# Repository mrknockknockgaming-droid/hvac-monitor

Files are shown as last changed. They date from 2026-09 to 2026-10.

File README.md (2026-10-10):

# Fullscope: continuous HVAC diagnostics

Fullscope monitors a home's heat pump or air conditioner continuously, the way a technician
would with gauges on it, and tells the contractor and the homeowner when something is going
wrong, before it becomes a no-cool call.

Two small ESP32 monitors sit on the equipment:
- **Outdoor:** refrigerant pressures, line temperatures, outdoor air.
- **Indoor:** supply and return air.

Both read which calls the thermostat is making. A cloud service turns their readings into
superheat, subcooling, delta-T and other checks, and shows them in a web app with two views:
- a **technician view** with live trends and diagnostics;
- a **homeowner view** in plain language.

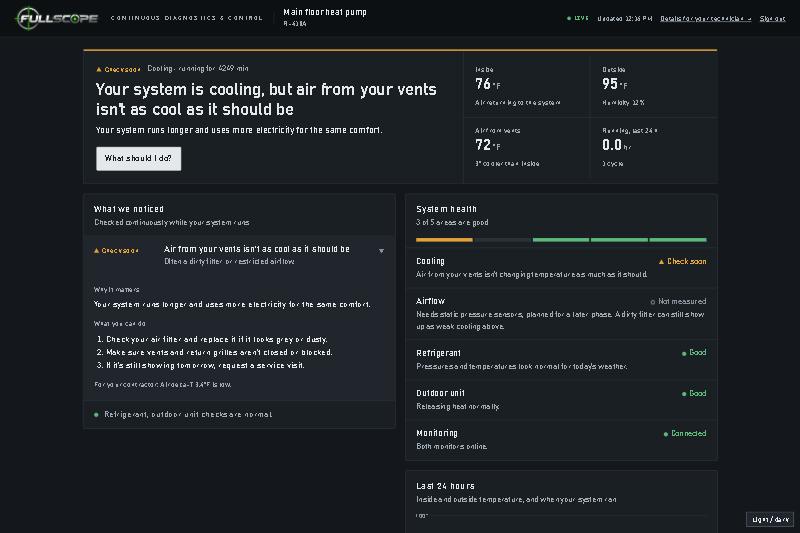
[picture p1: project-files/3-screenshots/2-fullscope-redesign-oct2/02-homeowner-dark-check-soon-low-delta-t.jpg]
Homeowner view


## Status (October 2026)

| Part | State |
|---|---|
| Node firmware (outdoor + indoor) | v0.2.0 built; both dev boards online running 0.1.0, 0.2.0 goes on at board bring-up |
| Carrier boards (rev A, KiCad) | Arrived and assembled; waiting on the pressure sensors for bring-up |
| Cloud + web app | Working locally (SQLite) and in Docker (TimescaleDB); production setup ready to deploy |
| Contractor demo | Seven scripted homes for customer interviews |
| Display thermostat (add-on) | Cloud side, screen and firmware written and tested on the PC; no hardware yet |
| Electrical module (add-on) | Diagnostics written; no hardware yet |
| 900 MHz LoRa radio | Designed and written (nodes, gateway, thermostat as gateway); waiting on a range test |

The full plan is in [project-files/1-plans/roadmap.md](project-files/1-plans/roadmap.md).

## How it fits together

```
 outdoor node ─┐                       ┌─ web app: homeowner + technician views, fleet page
 indoor node  ─┼─ WiFi (or LoRa via ─▶ MQTT broker ─▶ cloud: ingest → diagnostics → alerts
 thermostat   ─┘   a gateway)                          (FastAPI, SQLite / TimescaleDB)
                                                       └─ email alerts, thermostat config + display feed
```

- The nodes publish JSON on `hvac/<site>/<node>/{telemetry,status,reply}` and take
  calibration commands on `.../cmd`.
- The cloud judges each check only when it can be judged, for example refrigerant after
  10 minutes of steady running. A problem that lasts 5 minutes raises an alert.
- The optional display thermostat runs all its control and safety logic on the device itself,
  so heating and cooling never depend on the internet.

## What's where

| Folder | What it is |
|---|---|
| [hvac-firmware](hvac-firmware) | ESP32 firmware for the outdoor and indoor nodes (PlatformIO) |
| [hvac-cloud](hvac-cloud) | Cloud: MQTT ingest, diagnostics, alerts, REST API, the Fullscope web app, contractor demo, Docker / production setup ([DEPLOY.md](hvac-cloud/DEPLOY.md)) |
| [hvac-monitor-app](hvac-monitor-app) | PC dashboard for bench work with one system |
| [hardware](hardware) | Rev A carrier boards (KiCad, fabrication files, schematic PDFs) |
| [docs](docs) | Wiring schematics and carrier-board notes (HTML) |
| [thermostat](thermostat) | Display thermostat: design ([README](thermostat/README.md)) and firmware for the Waveshare ESP32-S3 4.3" board |
| [electrical](electrical) | Electrical monitoring module: design and diagnostic rules |
| [radio](radio) | 900 MHz LoRa: FCC research, frame format, Python reference, C++ library, gateway, range test |
| [design](design) | Fullscope design system, mockups and logos |
| [project-files](project-files) | Roadmap, contractor interview kit, parts list, screenshots, branding |
| [_archive](_archive) | Early prototypes, kept for reference |

[CLAUDE.md](CLAUDE.md) is the detailed, up-to-date technical overview of the whole project.

## Running it

**On Windows, the quick way:** `start-hvac.bat` (the Desktop "HVAC Monitor" shortcut) starts
three things:
- the MQTT broker;
- the PC dashboard on http://localhost:8080;
- the cloud with its web app on http://localhost:8000.

**Cloud only, for development:**

```powershell
cd hvac-cloud
python -m venv .venv
.venv\Scripts\python.exe -m pip install -r requirements-dev.txt
.venv\Scripts\python.exe -m pytest -q
```

Then follow [hvac-cloud/README.md](hvac-cloud/README.md) to create an account and system and
start the ingest worker and API.

**The contractor demo:** after the cloud is running, `hvac-cloud\start-demo.bat` creates a demo
contractor account with seven homes acting out common faults. The sign-ins are saved to
`hvac-cloud\demo-login.txt`.

**Firmware:** copy `include/config.example.h` to `include/config.h`, fill in WiFi and the
broker, then build and flash with PlatformIO:

```powershell
cd hvac-firmware
pio run -e outdoor -t upload
```

See [hvac-firmware/README.md](hvac-firmware/README.md) for calibration and the command list.

## Tests

| Where | Command | What it checks |
|---|---|---|
| `hvac-cloud` | `.venv\Scripts\python.exe -m pytest -q` | Cloud, diagnostics, alerts, accounts, thermostat, demo |
| `thermostat/firmware` | `pio test -e native` | The thermostat's C++ controller replayed against the Python reference |
| `radio/lora` | `pio test -e native` | LoRa frames and encryption, byte for byte against the Python reference |
| `radio` | `.venv\Scripts\python.exe -m pytest -q` | The Python frame format reference |

The native PlatformIO tests need a host C++ compiler, for example MSYS2 `ucrt64` on the PATH.

## Safety

The monitors are low-voltage (24 VAC from the equipment's control circuit). Never connect a
board to USB and 24 VAC at the same time. The electrical module and the thermostat touch more
than that, and their READMEs cover what is needed before either goes near real equipment
(isolation, qualified installation, UL 60730 / 61010). Readings are diagnostic inferences, not
confirmed diagnoses.

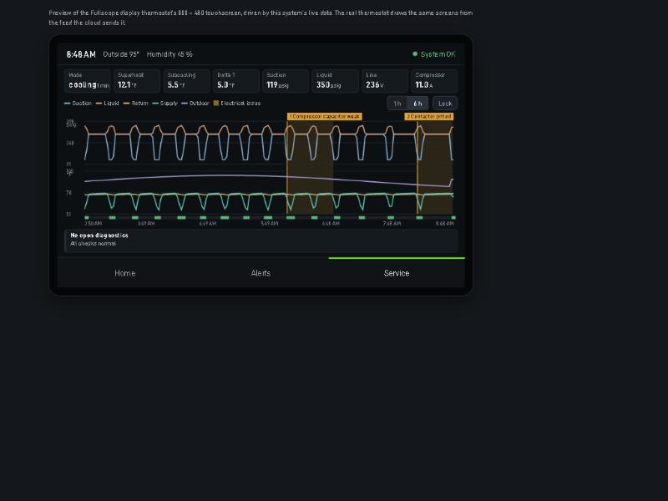
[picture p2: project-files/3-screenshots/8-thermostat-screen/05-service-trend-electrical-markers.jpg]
The thermostat's technician screen: pressure and air trend with an electrical fault marker


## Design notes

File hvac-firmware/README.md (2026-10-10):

# HVAC Monitor firmware (v0.2.0)

One PlatformIO project builds both nodes:

| Build env | Node | Sensors |
|---|---|---|
| `outdoor` | Refrigerant side | 3× XDB307 (2 fitted), 2× NTC (+2 future), SHT30, Y and O/B |
| `indoor`  | Air side | 2× DS18B20 (supply/return), Y, W, G, O/B |

Pins and net names match the rev A schematics.

## 1. Tools
1. Install **VS Code** and the **PlatformIO** extension.
2. Install an MQTT broker on your PC: **Mosquitto** (mosquitto.org). The web app will read from the same broker.
   - Mosquitto 2.x only accepts local connections by default. Create `mosquitto.conf` with:
     ```
     listener 1883 0.0.0.0
     allow_anonymous true
     ```
     and start it with `mosquitto -c mosquitto.conf -v`. Allow port 1883 through your PC firewall.
3. Give your PC a fixed IP (DHCP reservation in your router) so the nodes can always find it.

## 2. Configure
Copy `include/config.example.h` to `include/config.h` and fill in WiFi, the PC's IP (`MQTT_HOST`), and an OTA password. Use the same OTA password in the `*_ota` sections of `platformio.ini`.

**Bench / PC broker:** `MQTT_TLS 0`, port 1883 (as before; a 0.1.0 `config.h` still builds).

**Outdoor divider resistors:** the firmware assumes the schematic's values:
- the pressure dividers are 10k top and 20k bottom (R1/R2, R3/R4, R5/R6);
- the rail monitor is 10k top and 15k bottom (R7/R8).

If the board is built with 10k in place of the 20k and 15k, add `#define P_DIV_BOTTOM_K 10.0` and
`#define RAIL_DIV_BOTTOM_K 10.0` to `config.h` (see `config.example.h`). The build refuses
values that would push the ADS1115 past its 3.3 V supply (for example 22k for R8). The node's
status reports the divider gains it was built with (`p_div`, `rail_div`).

**Cloud server** (see `hvac-cloud/DEPLOY.md`): `MQTT_HOST` = the server's domain (the name in
its certificate), `MQTT_PORT 8883`, `MQTT_TLS 1`, `MQTT_USER` / `MQTT_PASS` = the server's
`MQTT_NODES_USER` / `MQTT_NODES_PASS`, and the server's `tls/ca.crt` pasted into `config.h` as

```cpp
static const char MQTT_CA_CERT[] = R"PEM(
-----BEGIN CERTIFICATE-----
...
-----END CERTIFICATE-----
)PEM";
```

(a string constant: a `#define` can't hold the multi-line certificate). The node checks the
broker's certificate and name against it. TLS needs the right date, so the node sets its
clock by NTP after WiFi connects and waits up to 15 s for it before the first TLS attempt.

### What 0.2.0 changed
- MQTT over TLS (above). Builds: plain 66 % flash, TLS 76 %.
- Every reading carries `"ts"` (UTC seconds) once NTP has set the clock. While the broker
  can't be reached, up to 120 readings (10 min at 5 s) are kept in memory and sent oldest first
  on reconnect; the cloud and the PC dashboard file them under their own time. Status reports
  `backlog` and `dropped` (readings lost to a longer outage) and `tls`.
- After any successful command the node re-publishes its retained status, so new settings
  show up at once; status now includes `interval_ms`.
- No more `nvs_get_blob ... NOT_FOUND` lines at boot for settings that were never saved.

### LoRa instead of WiFi (optional)
With an SX1262 module wired up (pins in `config.example.h`), set `LORA_ENABLED 1` and the node's
`LORA_DEVICE_ID` / `LORA_KEY` from `radio/tools/new_device.py`. The node then talks only to the
site's LoRa gateway (`radio/README.md`), which republishes everything on the usual MQTT topics.
Readings carry no `ts` (the gateway stamps them), and over-the-air updates need WiFi.

## 3. Flash
With **24 VAC disconnected**, plug the ESP32 into USB, then:
```
pio run -e outdoor -t upload -t monitor
```
(or pick the env in the PlatformIO sidebar). Use `-e indoor` for the other board.
After the first USB flash you can update over WiFi: `pio run -e outdoor_ota -t upload`.

On boot the serial monitor shows which sensors were found, e.g.
`[hw] ADS1115 #1 ok, ADS1115 #2 ok, SHT30 ok`, then one JSON line per reading.

## 4. Status LED (GPIO2)
- Fast blink: no WiFi
- Slow blink: WiFi OK, can't reach MQTT broker
- Short flash every 3 s: all good

## 5. MQTT topics
`hvac/<SITE_ID>/<node>/telemetry`, `/status` (retained, last-will), `/cmd`, `/reply`

Watch everything:
```
mosquitto_sub -h localhost -t 'hvac/#' -v
```
Send a command:
```
mosquitto_pub -h localhost -t hvac/home/outdoor/cmd -m '{"cmd":"status"}'
```

### Outdoor telemetry
```json
{"node":"outdoor","fw":"0.1.0","uptime":312,"rssi":-58,
 "mode":{"Y":true,"OB":false},
 "p":{"liq":318.4,"vap":121.7,"tsuc":null},          // psig
 "t":{"suc":54.2,"liq":96.1,"tsuc":null,"dis":null}, // °F
 "air":{"t":104.5,"rh":11.8},
 "v5":5.03,
 "raw":{"p_liq":2.31,"p_vap":1.36,"t_suc":13880,"t_liq":4712},
 "err":[]}
```
`null` means not fitted or no valid reading; `err` lists what's wrong.

### Indoor telemetry
```json
{"node":"indoor","mode":{"Y":true,"W":false,"G":true,"OB":false},
 "air":{"supply":55.8,"return":75.4,"dt":19.6},"err":[]}
```
Saturation temps, superheat and subcooling are calculated by the web app, so refrigerant tables can be updated without reflashing.

## 6. Commands
Common: `reboot`, `status`, `{"cmd":"interval","ms":5000}`

Outdoor:
| Command | Use |
|---|---|
| `{"cmd":"cal_zero","ch":"p_liq"}` | Sensor open to atmosphere → sets 0 psig |
| `{"cmd":"cal_span","ch":"p_liq","ref":300}` | At a known pressure (≥50 psi) from your reference gauge |
| `{"cmd":"cal_ref","ch":"t_suc","ref":32}` | Probe at a known temp (ice bath = 32 °F) |
| `{"cmd":"cal_set","ch":"p_vap","offset":-1.5,"scale":1.0}` | Manual values |
| `{"cmd":"cal_reset","ch":"p_liq"}` | Back to factory |
| `{"cmd":"range","ch":"p_tsuc","bar":35}` | Transducer full-scale range |
| `{"cmd":"fitted","ch":"p_tsuc","on":true}` | Enable a channel once installed |
| `{"cmd":"ntc_b","value":3950}` | Thermistor B-value |
| `{"cmd":"v33","value":3.29}` | Measured 3V3 pin voltage (better thermistor accuracy) |

Channels: `p_liq`, `p_vap`, `p_tsuc`, `t_suc`, `t_liq`, `t_tsuc`, `t_dis`

Indoor: `ds_swap` (supply/return reversed), `rescan`, `cal_ref` / `cal_set` / `cal_reset` with `t_sup` or `t_ret`.

Calibration is stored in flash and survives reboots and firmware updates.

## 7. Bench calibration procedure
1. **Zero:** both transducers open to atmosphere → `cal_zero` on `p_liq` and `p_vap`.
2. **Span:** tee both transducers and your Fieldpiece probe on a nitrogen regulator, bring it to ~300 psi, let it settle → `cal_span` with the reference reading on each channel.
3. **Check:** step through 100 / 200 / 400 psi and compare. Expect within ~2–3 psi.
4. **Thermistors:** meter the 3V3 pin → `v33`. Put both probes in a stirred ice bath → `cal_ref` with 32.
5. **Mode inputs:** apply 24 VAC to Y, confirm `"Y":true` within ~0.1 s, remove it and confirm it drops.

## Notes
- The ESP32 uses a PCB antenna: mount it in a plastic enclosure outside sheet metal. Watch `rssi` (better than −75 dBm is comfortable).
- Never connect USB and 24 VAC at the same time.

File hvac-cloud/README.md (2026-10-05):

# HVAC Monitor cloud

Stores node data for many systems and serves it over a REST API. It is the multi-customer
version of `hvac-monitor-app` (the PC dashboard), using the same MQTT topics and the same
superheat / subcooling / fault-flag math.

| Part | What it does |
|---|---|
| `hvaccloud/ingest.py` | Subscribes to `hvac/<site>/<node>/{telemetry,status,reply}`, stores raw telemetry, derived snapshots and node status, pairs command replies |
| `hvaccloud/alerts.py` | Turns fault flags that last 5 min into alerts, adds "no data" alerts, emails the account |
| `hvaccloud/api.py` | FastAPI: systems, live state, history, CSV export, settings, commands to nodes |
| `hvaccloud/calc.py` | Port of the dashboard's `Hub.compute` / `Hub.flags`; `tests/test_calc.py` checks they match |
| `hvaccloud/db.py` | SQLAlchemy models; SQLite in development, TimescaleDB hypertables in production |
| `web/` | Fullscope web app (homeowner + technician views), served by the API at `/app/` |
| `hvaccloud/electrical.py` | Optional electrical module (third node `electrical`): amps, voltage, capacitor, contactor rules |
| `hvaccloud/equipment.py` | Equipment details; nameplate subcooling targets applied after `calc` (cloud only) |
| `hvaccloud/auth.py` | Passwords (scrypt), sign-in sessions, who is asking (contractor / homeowner / API key) |
| `hvaccloud/service.py` | Maintenance reminders (air filter, tune-up) and the service contractor |
| `hvaccloud/maintenance.py` | Nightly backup of `dev.db` and thinning of old data |
| `manage.py` | Create accounts, API keys and systems; send a test alert email; backup / prune by hand |
| `demo.py`, `start-demo.bat` | Contractor demo: a separate demo account with seven homes acting out common faults |
| `demo_publisher.py` | Simulated outdoor + indoor nodes over MQTT (site `demo`); `--thermostat` adds a display thermostat and a simulated house |

A system's `site_id` is the node's `SITE_ID` in `hvac-firmware/include/config.h`, so the
firmware needs no changes. Messages from sites with no system are ignored.

## Development (no Docker)

```powershell
cd C:\Users\mrkno\hvac-monitor\hvac-cloud
python -m venv .venv
.venv\Scripts\python.exe -m pip install -r requirements-dev.txt
.venv\Scripts\python.exe -m pytest -q
```

With a Mosquitto broker on localhost:1883 (`start-hvac.bat` starts one), in separate windows:

```powershell
.venv\Scripts\python.exe manage.py create-account "Tyler" you@example.com
.venv\Scripts\python.exe manage.py create-key 1
.venv\Scripts\python.exe manage.py create-system 1 "Home" home --atm-psia 14.0
.venv\Scripts\python.exe -m hvaccloud.ingest
.venv\Scripts\python.exe demo_publisher.py          # optional, needs: manage.py create-system 1 "Demo" demo
.venv\Scripts\python.exe -m uvicorn hvaccloud.api:app --port 8000
```

Data goes to `dev.db` (SQLite). Web app: http://localhost:8000/ (sign in with the API key).
Interactive API docs: http://localhost:8000/docs (click Authorize and paste the API key).

## Contractor demo

`start-demo.bat` (or `python demo.py setup` then `python demo.py run`) adds a separate demo
account, "Desert Air Demo Co.", with seven homes, a day of history and past alerts:

| Home | Shows |
|---|---|
| Garcia residence | healthy, with a Fullscope thermostat and electrical module (its homeowner sign-in shows the homeowner page) |
| Thompson residence | low delta-T and an overdue filter |
| Patel home | high superheat, low subcooling (below the nameplate target): a slow leak |
| Miller rental | condensing 36+ °F over ambient: dirty coil or blocked airflow |
| Nguyen casita | indoor monitor offline for 3 hours |
| Brooks home | superheat near zero: floodback risk, service needed |
| Rivera home | thermostat + electrical module: the compressor's run capacitor reads weak (38 of 45 uF) since 2.5 h before setup; "See the thermostat's screen" shows the alert and, on the Service page (PIN 0000), the marker on the trend |

The sign-ins are generated at setup and saved in `demo-login.txt` (git-ignored). Readings go
straight through the ingest code (no broker or nodes), into the same database as the local
cloud; `run` first fills any gap since it last ran so the homes look continuous. Demo systems
never send email. `python demo.py reset` removes the demo account and everything in it, nothing
else.

## Display thermostat (phase 11, optional)

Design: [../thermostat/README.md](../thermostat/README.md). The thermostat runs its own control
and safety logic (`hvaccloud/thermostat.py`, `Controller`, the reference for the firmware). The
cloud stores the settings and publishes them, retained and versioned, to
`hvac/<site>/thermostat/config`. The thermostat reports on `hvac/<site>/thermostat/telemetry`.
Its state and diagnostics ride along in the system's snapshots, under `tstat`. Systems
without a thermostat are unchanged. Homeowners get a thermostat card (setpoint, mode, fan,
schedule, resume); technicians get thermostat rows on Monitor and its safety settings on
Equipment. Try it with `python demo_publisher.py --site demo --thermostat` (add
`--electrical --fault pitted_contactor` for the electrical module).

Changes made on the thermostat's own screen arrive on `hvac/<site>/thermostat/request`. Ingest
merges them into the stored settings (`thermostat.apply_request`) and sends back a newer config.

The thermostat's own screen (Home, Alerts for homeowners, Service for technicians, with a trend
and electrical fault markers) has a browser preview at `/app/thermostat.html#<system id>`, using
the display feed from `hvaccloud/display.py`. Ingest publishes the feed retained to
`hvac/<site>/thermostat/display`.

## Sign-in and roles

- **Contractor** users belong to an account and see all of its systems, including the
  technician pages. **Homeowner** users see only the systems they are members of: the
  homeowner page, read-only except "I changed it" for the air filter.
- Users sign in with email and password (scrypt hashes). The session lives in an HttpOnly
  cookie for `SESSION_DAYS` (30, renewed while in use); set `COOKIE_SECURE=true` once the site
  runs on HTTPS. Requests that change something with the cookie must carry `X-Requested-With`
  (the web app adds it), which stops other sites from forging them. Eight wrong passwords for
  one email lock it for 15 minutes; unknown emails take as long to answer as wrong passwords.
  Users change their password on the Account page, which signs out their other sessions.
  Contractors can remove a colleague from "Your team".
- **Forgotten password:** "Forgot password?" on the sign-in page emails a one-time link
  (`#/reset/<token>`, 1 hour, at most 3 emails an hour per address; the answer never says
  whether the email has a sign-in). Using it sets the new password, ends every other session
  and signs the person in. Without SMTP, a contractor can make the link for a homeowner from
  "Homeowner access" (**Reset link**) and pass it on; `manage.py set-password` also works.
- API keys still work (header `X-API-Key`) and act as a contractor of their account.
- **Invites:** on a system's Sensors & calibration page ("Homeowner access") a contractor invites
  a homeowner by email; on the Account page ("Your team") a colleague. The person opens the
  link (`#/invite/<token>`, valid 7 days, works once), chooses a password and is signed in. The
  link is emailed when SMTP is set up and always shown to copy. An email that already has a
  homeowner sign-in is given access straight away. Links use `APP_URL`, so they only work on
  this PC until the site has a public address.
- **Fleet** (`#/fleet`, contractors' landing page): every system on the account, most in need of
  attention first (service needed, offline, check soon, good to know, maintenance due), with
  current issues and open alerts, node health, filter and tune-up. Refreshes every 15 s.

```powershell
.venv\Scripts\python.exe manage.py create-user you@example.com --name "Tyler" --account 1
.venv\Scripts\python.exe manage.py create-user owner@example.com --role homeowner --system 1
.venv\Scripts\python.exe manage.py set-password you@example.com
```
Both commands ask for the password at a hidden prompt (typed twice, at least 10 characters).

## Web app

Plain HTML/CSS/JS in `web/`, no build step; styles are copied from the Fullscope mockups in
`design/`. It polls the API every 5 s.

- **Home** (`#/home/<id>`): plain-language status, inside/outside/vent temperatures, what we
  noticed (each fault flag explained for a homeowner), maintenance, recent alerts, system
  health, last 24 hours.
  - **Maintenance:** air filter (due after 90 days or 500 hours of blower run time, whichever
    comes first; the homeowner presses "I changed it") and tune-up (every 182 days), with the
    service contractor and a **Request service** button. It opens the homeowner's email with
    the current issues filled in, or calls if only a phone number is set. Run time is added up
    per day by the ingest worker (`runtime_days`).
- **Monitor** (`#/monitor/<id>`): superheat, subcooling, delta-T, condensing over ambient,
  compression ratio; live trend (15 min to 7 days); operating state; sensor health from the
  nodes' own error codes; refrigerant and air-side tables; current diagnostics; alert log;
  CSV export.
- **Equipment** (`#/equipment/<id>`), laid out like the mockup's equipment configuration:
  system type, heat pump / straight cool, O/B, refrigerant, metering device, tonnage; nameplate
  subcooling target ± tolerance, rated capacity and airflow, maximum external static; site
  elevation (sets atmospheric pressure). With a TXV or EEV and a target, subcooling in cooling is
  judged against target ± tolerance instead of the generic 3–20 °F, and Monitor shows the target.
  Superheat keeps the generic 3–30 °F (the valve controls it; a piston's target needs indoor
  humidity, phase 6). Ratings and static are stored for phase 6 and marked "not used yet". The
  PC dashboard and `calc.py` are unchanged, so the parity test still holds.
- **Electrical module** (optional, design in `../electrical/README.md`): readings on
  `hvac/<site>/electrical/telemetry` are joined to the next snapshot as `elec` and judged against
  the nameplate RLA / LRA / FLA / capacitor µF / voltage range on the Equipment page. They show as
  rows in Monitor's Operating state table ("Not installed" without a module) and roll up into the
  homeowner's "Outdoor unit" area. Try it: `demo_publisher.py --electrical --fault weak_cap`.
- **Service history** (`#/service/<id>`): log a visit (date, type, technician, work done,
  "replaced the air filter", "attach the current readings" from a snapshot under 15 minutes
  old). A tune-up moves the tune-up reminder and a changed filter the filter reminder forward
  (never back). Homeowners see the last three visits under Maintenance.
- **Sensors & calibration** (`#/setup/<id>`): for commissioning. Per channel: on/off, live
  reading, raw sensor volts or ohms, and the calibration stored on the node. Buttons send the
  firmware's commands (zero, span, ice bath / reference temperature, reset, range, B-value,
  measured 3.3 V rail, swap indoor probes, rescan, reporting interval, reboot). The command log
  shows each node's reply; after a change the page asks the node for its settings again. Buttons
  are disabled while a node is offline, and zero / reset / reboot ask for confirmation.
  Also the service contractor (name, phone, email) and the maintenance schedule (intervals and
  last-done dates).

Both views list the last 7 days of alerts (homeowner: "Recent alerts"; technician: "Alert log").

## Alerts and email

- A fault flag opens an alert once it has lasted `ALERT_HOLD_SECONDS` (5 min), and the alert
  clears once the flag has been gone that long, so a value hovering at a limit gives one alert.
- Checks that only run while the equipment runs (superheat, subcooling, delta-T, condensing over
  ambient: after 10 minutes of steady running) can't be judged while it's idle or a node is
  offline, so their alerts stay open between cycles (`alerts.unjudged`). They clear when a
  later run no longer shows the problem: one low-charge alert, not one per cycle (and no
  "back to normal" email every time the compressor stops).
- If a system that has reported goes silent for `ALERT_NO_DATA_SECONDS` (10 min), the ingest
  worker's once-a-minute sweep opens a "no data" alert; it clears on the next reading.
- Raised alerts are emailed at most once per fault type per `ALERT_EMAIL_COOLDOWN_HOURS` (6 h);
  a "back to normal" email follows an emailed alert unless someone acknowledged it.
- **Recipients** (Sensors & calibration page, "Alert email"), both on by default: the
  system's **homeowners** (everyone with homeowner access) get plain language with what to do;
  the **contractor** (the contractor panel's email, else the account's email) gets the technical
  reading, the site id and a link to the technician view.
- **Acknowledge** (Alert log) marks an open alert as being handled; the homeowner sees "Being
  handled". **Mute** stops emails for one kind of alert on a system for 1, 7 or 30 days; alerts
  are still recorded and shown.
- Email is off until SMTP is set up. Copy `.env.example` to `.env` (never committed) and fill
  in the `SMTP_*` lines. For Gmail, use `smtp.gmail.com`, port 587 and an App Password
  (Google account > Security > 2-Step Verification > App passwords). Then check it with
  `.venv\Scripts\python.exe manage.py test-email 1` and restart the ingest worker. Set where emails
  go with `manage.py set-email 1 <address>`.

Values the hardware does not measure yet (indoor humidity, static pressure, capacity) are
shown as "Not installed", never estimated. The API key is kept in the browser's local
storage; real per-user sign-in comes with going live (roadmap phase 8).

## Backups and data cleanup (SQLite)

Each node reports every 5 s, so `dev.db` grows by tens of MB a day. The ingest worker looks
after it once a night (3 AM, or on its next start if the PC was off then):

1. **Backup:** a consistent copy to `backups/dev-YYYYMMDD-HHMM.db` (safe while running),
   keeping the newest `BACKUP_KEEP` (7). `backups/` is not committed.
2. **Prune:** snapshots older than `FULL_DETAIL_DAYS` (30) are averaged into one per minute,
   raw telemetry older than that is deleted (each node's newest message is kept), and anything
   older than `KEEP_DAYS` (365) is deleted. Charts, history, summaries and CSV export work the
   same on thinned data, at 1-minute resolution.

Run either by hand with `manage.py backup` and `manage.py prune`. SQLite reuses the freed
space instead of shrinking the file. To restore: close the two cloud windows, delete
`dev.db-wal` and `dev.db-shm`, copy a backup over `dev.db`, then run `start-cloud.bat`.
On PostgreSQL, TimescaleDB's retention policy expires old data; back up with `pg_dump`.

## API

All endpoints except `/health` and `/api/auth/login` need a signed-in session cookie or the
header `X-API-Key: <key from manage.py create-key>`. Endpoints marked *tech* answer 403 to homeowners.

| Method | Path | |
|---|---|---|
| POST | `/api/auth/login` | `{"email","password"}`; sets the session cookie |
| POST | `/api/auth/logout` | Ends the session |
| GET | `/api/auth/me` | Role, user and account of whoever is asking |
| POST | `/api/auth/password` | `{"current","new"}` |
| GET | `/api/systems` | Systems this user can see |
| GET / POST | `/api/systems/{id}/visits` | Service visits (POST *tech*: `date`, `kind`, `technician`, `work`, `filter_changed`, `attach_readings`) |
| DELETE | `/api/systems/{id}/visits/{visit_id}` | *tech* Remove a visit logged by mistake |
| GET / PUT | `/api/systems/{id}/equipment` | *tech* Equipment page; PUT sends every field (null to clear) |
| GET | `/api/fleet` | *tech* All systems with status, issues, nodes and maintenance, worst first |
| POST | `/api/systems/{id}/invites` | *tech* `{"email"}`: invite a homeowner (or add an existing one) |
| GET | `/api/systems/{id}/people` | *tech* Homeowners with access and pending invites |
| DELETE | `/api/systems/{id}/members/{user_id}` | *tech* Remove a homeowner's access |
| POST / GET | `/api/account/invites`, `/api/account/people` | *tech* Invite a colleague; list the team |
| DELETE | `/api/account/users/{user_id}` | *tech* Remove a colleague (deletes their sign-in, signs them out) |
| DELETE | `/api/invites/{id}` | *tech* Revoke an invite |
| POST | `/api/auth/forgot`, `/api/auth/reset` | `{"email"}` sends a reset link; `{"token","password"}` uses it |
| POST | `/api/systems/{id}/members/{user_id}/reset-link` | *tech* A reset link for one of the system's homeowners |
| POST | `/api/invites/lookup`, `/api/invites/accept` | `{"token"}` / `{"token","name","password"}`: open an invite link and create the sign-in (the token is never in a URL the server logs) |
| GET | `/api/systems/{id}` | Settings + nodes (online, age, fw, ip, rssi) |
| PATCH | `/api/systems/{id}` | `refrigerant`, `heat_pump`, `ob_energized` (`cool`/`heat`), `atm_psia` |
| GET | `/api/systems/{id}/latest` | Newest derived snapshot (mode, pressures, sat temps, SH, SC, delta-T, flags) + each node's raw telemetry |
| GET | `/api/systems/{id}/summary?hours=24` | Compressor runtime, cycles, average on-time, outside high, inside average |
| GET | `/api/systems/{id}/history?minutes=60` | Averaged series, at most ~600 points |
| GET | `/api/systems/{id}/export.csv?minutes=1440` | Snapshots as CSV (UTC times) |
| GET | `/api/systems/{id}/alerts?days=7` | Raised alerts open during the last `days`, newest first |
| POST | `/api/systems/{id}/alerts/{alert_id}/ack` | `{"ack": true}` (false undoes) |
| GET / PUT | `/api/systems/{id}/alert-settings` | `email_owner`, `email_contractor`; GET also lists active mutes |
| PUT | `/api/systems/{id}/alert-mutes/{code}` | `{"hours": 24}`; 0 unmutes |
| GET | `/api/systems/{id}/service` | Contractor + maintenance items (status, days and run hours since, next due) |
| PUT | `/api/systems/{id}/service/contractor` | `{"name","phone","email"}` |
| PATCH | `/api/systems/{id}/service/items/{filter\|tuneup}` | `interval_days`, `interval_run_hours` (null = days only), `last_done` |
| POST | `/api/systems/{id}/service/items/{kind}/done` | `{"date":"2026-10-03"}` (defaults to today) |
| GET / PUT | `/api/systems/{id}/thermostat` | Display thermostat: settings, schedule, what it reports, whether it runs the latest version; PUT `mode`, `fan`, `heat_sp`, `cool_sp`, `schedule` (homeowners too) |
| GET | `/api/systems/{id}/thermostat/display` | What the thermostat's screen shows: plain alerts, health areas, key numbers, 6 h trend, electrical markers |
| POST / DELETE | `/api/systems/{id}/thermostat/hold` | `{"heat"?, "cool"?, "permanent"?}` holds until the next scheduled change; DELETE resumes the schedule |
| PUT | `/api/systems/{id}/thermostat/tech` | *tech* Safety settings (compressor protection, aux heat lockouts, time zone) |
| POST | `/api/systems/{id}/commands` | `{"node":"outdoor","cmd":{"cmd":"cal_zero","ch":"p_liq"}}` |
| GET | `/api/systems/{id}/commands` | Recent commands with the node's reply |

Commands are the firmware's (see the top of `hvac-firmware/src/node_outdoor.cpp`), e.g.
`{"cmd":"fitted","ch":"t_tsuc","on":true}` to enable the J9 thermistor channel.

## Docker (TimescaleDB): the production setup

Tested 2026-10-03 on Docker Desktop 29.8 / Compose 5.5 (TimescaleDB 2.30, Mosquitto 2.1): all
tables created, `snapshots` and `telemetry` as hypertables with 365-day retention, nodes
publishing as `nodes`, ingest and API on the `backend` account, anonymous and wrong-password
broker logins refused, web app served from the container.

1. Copy `.env.example` to `.env` and set `POSTGRES_PASSWORD`, `MQTT_BACKEND_PASS` and
   `MQTT_NODES_PASS` (long random strings). The broker builds its password file from these on
   every start (`mosquitto/start.sh`), so changing one only needs `docker compose up -d`.
2. `docker compose up -d --build`, then
   `docker compose exec api python manage.py create-account ...` etc. as above.
3. Point a node at it in `config.h`: `MQTT_HOST` = this machine, `MQTT_PORT 1884`,
   `MQTT_USER` = `MQTT_NODES_USER` (default `nodes`), `MQTT_PASS` = `MQTT_NODES_PASS`. Reflash.

The SQLite nightly backup / thinning doesn't run here; TimescaleDB's retention policy expires
old rows. Back up with `docker compose exec db pg_dump -U hvac hvac > backup.sql`.

**Public server:** add `-f docker-compose.prod.yml` for HTTPS (Caddy), MQTT over TLS on 8883
with a private CA (`tls/make-certs.sh`), the secure cookie and a daily `pg_dump` backup. Step by
step in [DEPLOY.md](DEPLOY.md).

## Not done yet

- Web app: service requests sent through the cloud (now the homeowner's email),
  sending the homeowner and contractor emails from separate per-user accounts.
- Per-device MQTT accounts and topic ACLs (every node shares one account for now).
- Firmware with MQTT over TLS (the server side is ready, see DEPLOY.md).

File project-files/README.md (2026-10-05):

# Project files

Everything about the HVAC Monitor / Fullscope project that isn't code: plans, the parts list,
screenshots of each stage of the web app and the thermostat screen, and branding. The design
documents live next to the code they describe; the table at the end points to each one.

Collected Oct 4, 2026. The roadmap and the interview kit are copies: the live versions are the
Claude Docs linked at the top of each file, and those are the ones to edit.

## 1-plans

| File | What it is |
|---|---|
| [roadmap.md](1-plans/roadmap.md) | Phases 0–12, the radio decision point, customer discovery and IP tracks, with what's done ([live doc](https://claude.ai/code/artifact/e6a28e8e-9f92-404c-92b2-67be47d77f7e)) |
| [contractor-interview-kit.md](1-plans/contractor-interview-kit.md) | Who to talk to, demo setup, the 10-minute demo script, 21 questions, what each answer decides, notes sheet ([live doc](https://claude.ai/code/artifact/73343a90-f40b-4778-9df8-f79033e4813c)) |

## 2-parts

[HVAC_Monitor_Parts_List.xlsx](2-parts/HVAC_Monitor_Parts_List.xlsx): a copy of the parts list from the Desktop (Oct 4), with these sheets:
- Summary, Power Kit, Outdoor Node, Indoor Node, Infrastructure
- Display Node, with the thermostat module
- LoRa Radio

Costs are split by phase: V1, Optional, Phase 2, Future (thermostat) and LoRa. The working copy stays on the Desktop.

## 3-screenshots

Taken in the browser while each feature was built and checked. They show test and demo data only.

| Folder | Shows |
|---|---|
| 1-first-web-app-sep29 | The first web app: homeowner page, technician monitor, live trends, refrigerant/air tables, sensor health |
| 2-fullscope-redesign-oct2 | The Fullscope design system: logo header, dark and light themes |
| 3-technician-tools | Alert log; Sensors & calibration (zero / span from the browser) |
| 4-homeowner | Maintenance card: filter and tune-up reminders, contractor, recent service |
| 5-accounts-and-fleet | Email and password sign-in; the contractor's fleet page, worst first |
| 6-contractor-demo | The interview demo: fleet, Brooks home (floodback), Rivera's thermostat screen and capacitor marker |
| 7-thermostat-web | Thermostat card, holds and schedule, technician rows, safety settings, phone width |
| 8-thermostat-screen | The thermostat's own 800 × 480 screen: Home, Alerts (plain language, System health, what to do), Service (trend with electrical markers) |
| 9-electrical-module | Technician electrical rows: line volts, contactor, amps, run capacitor |

## 4-branding

`fullscope-logo-original.png`, a copy of the original logo file (the `fullscope logo` file at the
top of the repo). The web app's logos and design system are in [../design](../design).

## Where everything else is

| Topic | Where |
|---|---|
| Project overview and current state | [../CLAUDE.md](../CLAUDE.md) |
| Cloud: setup, demo, alerts, API | [../hvac-cloud/README.md](../hvac-cloud/README.md) |
| Going live on a server | [../hvac-cloud/DEPLOY.md](../hvac-cloud/DEPLOY.md) |
| Node firmware: flashing, MQTT topics, commands, calibration, LoRa mode | [../hvac-firmware/README.md](../hvac-firmware/README.md) |
| Wiring schematics (rev A) | [../docs/hvac-schematics.html](../docs/hvac-schematics.html) |
| Carrier boards (rev A, KiCad, JLCPCB) | [../docs/carrier-boards.html](../docs/carrier-boards.html), [../hardware](../hardware) (schematic PDFs in each carrier folder) |
| Display thermostat: design, safety rules, screen, firmware | [../thermostat/README.md](../thermostat/README.md) |
| Electrical module: design and rules | [../electrical/README.md](../electrical/README.md) |
| 900 MHz LoRa radio: FCC rules, frames, security, gateway, range test, firmware | [../radio/README.md](../radio/README.md) |
| Design system, mockups, logos | [../design](../design) |
| PC dashboard (bench tool) | [../hvac-monitor-app](../hvac-monitor-app) |

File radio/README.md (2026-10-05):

# 900 MHz radio (LoRa) for the nodes: design and decision work

Roadmap: *Decision point: 900 MHz radio architecture (before Phase 9)*. Sheet-metal cabinets
and homeowner WiFi are the weak points for nodes at the condenser and in the attic. The idea,
like Honeywell's RedLINK: each node carries a LoRa radio and talks to a gateway (a plug-in unit,
or built into the display thermostat) that forwards to the cloud.

**Status (2026-10-03):** regulatory and module research done; radio settings chosen; frame
format, encryption and gateway logic written as a tested Python reference (`lorafmt.py`, 8 tests,
`vectors.json` for the firmware); range-test firmware for two Heltec V3 boards built (not run).
Waiting on: buying the prototype boards, the range test, contractor interviews.

## 1. US rules (FCC Part 15.247, 902–928 MHz)

There are three ways to be legal, and they decide the radio settings:

| Approach | Requirement | Power |
|---|---|---|
| Frequency hopping (FHSS) | ≥ 50 channels, pseudo-random hops, **≤ 400 ms on any channel per 20 s** | 1 W (30 dBm) |
| Digital modulation (DTS) | **6 dB bandwidth ≥ 500 kHz**, ≤ 8 dBm per 3 kHz | 1 W |
| Hybrid | hops (no 500 kHz minimum), 400 ms dwell, DTS power density | 1 W |

**A fixed 125 kHz or 250 kHz LoRa channel meets none of them**: it is too narrow for DTS and
doesn't hop. LoRaWAN avoids this by hopping over 64 channels, which needs an 8-channel
concentrator gateway (SX1302, ~$100+).

**Choice: one fixed channel at 500 kHz bandwidth (DTS).** It's legal without hopping, works with
a single-chip SX1262 gateway, and a 45-byte frame takes 77 ms at SF9. It costs 6 dB of
sensitivity against 125 kHz, but the link budget below has plenty to spare.

## 2. Radio settings and link budget

915-ish MHz, 500 kHz bandwidth, coding rate 4/5, preamble 8, explicit header, CRC on, private
sync word. Spreading factor 9 by default (11 as the fallback for a hard install).

| SF (500 kHz) | 7 | 8 | 9 | 10 | 11 | 12 |
|---|---|---|---|---|---|---|
| Outdoor frame (45 B) airtime, ms | 23 | 41 | 77 | 144 | 267 | 494 |
| SX1262 sensitivity, dBm (≈) | −117 | −120 | −123 | −126 | −128 | −131 |

At 20 dBm transmit power and SF9 the link budget is about **143 dB**. A path from a condenser
or attic through a house typically loses 90–120 dB at 915 MHz, so even with 10–20 dB for metal
cabinets and antenna placement there should be 15+ dB left. The range test (section 7) checks
that on a real house. Airtime is tiny: one 77 ms frame every 5 s is 1.5 % of the time.
(`python lorafmt.py` prints the full airtime table.)

## 3. Frames (`lorafmt.py`, format version 1)

```
| ver|type (1) | device id (4) | counter (4) | encrypted payload | tag (8) |
  └──── authenticated, not encrypted ─────┘
```

- **Readings:** outdoor 28-byte payload → 45-byte frame; indoor 13 → 30. Values are int16 tenths
  (psig, °F), humidity in tenths of a percent, the 5 V rail in 10 mV steps, mode inputs and error
  codes as bit fields, and `age` (seconds since measured, for readings kept during an outage).
  The gateway turns them back into **exactly the JSON the WiFi firmware sends**, plus `ts` and
  the radio's RSSI/SNR, and publishes it on the same MQTT topics: **the cloud and the PC
  dashboard need no changes.**
- **Status:** firmware version, interval, backlog, dropped (10 bytes).
- **Commands / replies:** every command on the Sensors & calibration page fits in 7 bytes
  (command, channel, value, flag); replies carry ok, an error code and the new offset/scale.
- **Not over LoRa:** the raw sensor volts/ohms and the full calibration table. Commissioning
  (zero, span, ice bath) can still be done over LoRa; the raw numbers are only visible when the
  node is set up on WiFi. A "send raw values" command can be added if technicians miss them.

## 4. Security

- **AES-128-CCM** per frame (encrypt + 8-byte authentication tag; mbedTLS on the ESP32 has it).
  The header is authenticated too, so the device id and counter can't be changed.
- **Per-device key**, loaded at manufacturing and registered with the cloud (Phase 9: QR claim
  codes). A copied frame from a neighbour's system fails authentication.
- **Replays refused:** the counter must go up. The node saves it to flash every 100 frames and
  jumps ahead by 100 after a reboot, so a counter is never reused; the gateway keeps the highest
  one it accepted per device.
- The nonce (device id + counter + type) never repeats for a key, which CCM requires.

## 5. Gateway

- ESP32-S3 + SX1262 (prototype: a third Heltec V3). Listens continuously on the site's channel.
- For each frame: look up the device key, authenticate, check the counter, decode, publish to
  `hvac/<site>/<node>/telemetry|status|reply` over MQTT/TLS (firmware 0.2's TLS and outage
  buffer code carries over), and add `radio: {rssi, snr}` so the technician view can show link
  quality.
- **Downlink:** the nodes run from 24 VAC, so they can listen whenever they're not sending: the
  gateway forwards a command as soon as it arrives on `.../cmd` and the node replies at once.
- Its own status (`hvac/<site>/gateway/status`): uptime, frames per node, last RSSI/SNR, errors.
- **WiFi-direct mode stays:** a node with WiFi credentials and no gateway works exactly as today.

## 6. Channel plan

Eight 500 kHz channels, 903.0 + 1.6·n MHz (n = 0–7, the LoRaWAN US915 500 kHz uplink grid). A
site uses one, chosen from its site id (FNV-1a hash mod 8, `channel_mhz` in both lorafmt.py and
the C++ library), so neighbouring systems usually don't share. The range test uses 915.0 MHz.

## 7. Range test (two Heltec V3 boards, `rangetest/`)

1. Flash one board as `sender`, one as `receiver` (PlatformIO, see `rangetest/platformio.ini`).
2. Put the receiver where a gateway would plug in (near the router or thermostat), on USB to a
   laptop logging the serial CSV.
3. Put the sender, on a USB power bank, at the outdoor unit (inside the service panel area,
   then outside the cabinet), in the attic next to the air handler, and in the garage.
4. At each spot, run SF9 for 5 minutes, then SF7 and SF11 (press PRG on both boards).

**Pass at SF9:** < 1 % packets lost, and RSSI ≥ −108 dBm (15 dB above sensitivity) at the
worst spot. If it only passes at SF11, LoRa still works but with less margin; if it fails at
SF11, rethink the antenna placement before the whole approach.

## 8. Hardware

**Prototype (order now if going ahead):**

| Item | Qty | Approx. |
|---|---|---|
| Heltec WiFi LoRa 32 (V3), **915 MHz** version (ESP32-S3 + SX1262, OLED) | 3 (2 range test + gateway) | $20–25 each |
| 915 MHz antenna, 3 dBi, SMA, with u.FL-to-SMA pigtail | 3 | $8 each |
| USB power bank (for the sender during the walk-around) | 1 | (any) |

**Production candidates (FCC modular approval, so the product doesn't need its own radio
certification beyond the usual unintentional-emitter testing):**

| Module | What it is | FCC ID |
|---|---|---|
| Heltec **HT-CT62** | ESP32-C3 + SX1262 in one 18 mm module, ~$7 | 2A2GJ-HT-CT62 |
| Seeed **Wio-SX1262** | SX1262 radio module, pairs with any ESP32 | Z4T-WIO-SX1262 |
| RAKwireless **RAK3172** | STM32WL (MCU + LoRa radio) | 2AF6B-RAK3172 |

Before choosing, confirm with each module's FCC grant (or a test lab) that it covers 500 kHz DTS
operation at the power we'd use, and which antennas it was approved with.

## 9. The decision

| | LoRa + gateway | WiFi only (today) | Cellular (LTE-M) |
|---|---|---|---|
| Reaches attic / condenser | Yes, with margin (range test to confirm) | Often weak through metal | Usually yes |
| Extra hardware per install | Gateway (~$15–25 BOM) | None | Modem per node (~$15–25) |
| Monthly cost | None | None | ~$1–3 per node |
| Install effort | Plug in gateway, pair (QR) | Enter WiFi at each node | SIM activation |
| Depends on homeowner WiFi | Gateway only | Every node | No |

Decide after the range test and the contractor interviews (who installs, how much setup they'll
tolerate, what a monthly fee does to the price).

## Firmware (written, tested on the PC, not yet run on radios)

- **`lora/lib/lorafmt`**: the C++ port of `lorafmt.py`. It covers AES-128-CCM (portable code;
  the S-box is computed rather than typed in; checked against FIPS-197), the frames, the channel
  plan and the gateway logic. `tools/make_cpp_vectors.py` produces exact cases from the Python
  reference: 300 random readings, plus statuses, commands, replies, the channel plan, and a
  gateway session with replays, a wrong key, an unknown device and a tampered frame.
  `pio test -e native` in `lora/` matches every byte (7 tests).
- **`lora/lib/lora_radio`**: the SX1262 via RadioLib on the site's channel (500 kHz, SF9,
  20 dBm). It always listens between transmissions.
- **Plug-in gateway**: `lora/src/main.cpp`, for a Heltec V3 (`pio run -e gateway_heltec`). It
  republishes frames on the usual topics and sends commands from `hvac/<site>/<node>/cmd` to the
  node. An OLED shows frames and RSSI per node, and it reports its own status (retained) on
  `hvac/<site>/gateway/status`.
- **Nodes**: `hvac-firmware`, with `LORA_ENABLED 1` in `config.h`. Readings, status (every
  5 min and after changes) and command replies go over LoRa instead of WiFi, and commands are
  handled exactly as over MQTT.
- **Thermostat as the gateway**: `thermostat/firmware`, with `LORA_GATEWAY 1`. It does the same
  job, and takes the outdoor air temperature straight from the outdoor node's frames, so the
  heat-pump lockouts work with the internet down. It needs free pins on the display board for
  the SX1262; check Waveshare's schematic.
- **Keys**: `tools/new_device.py outdoor` prints a node's device id and key, and the matching
  line for the gateway. There is one key per node.
- **Counters**:
  - Each node saves its counter every 100 frames and starts 100 ahead after a reboot, so a nonce
    is never reused.
  - The gateway saves each node's highest counter every 20 frames, so after a reboot at most 20
    old frames could be replayed once.
  - The gateway's own command counter jumps 100 ahead on boot.
- **Over LoRa there is:**
  - no "ts", because nodes on LoRa have no clock (the gateway stamps arrival time);
  - no over-the-air updates;
  - no WiFi status fields.

## Files

- `lorafmt.py`: reference frame format, encryption, gateway logic, airtime calculator.
- `test_lorafmt.py`: 8 tests; `python test_lorafmt.py` rewrites `vectors.json`.
- `vectors.json`: exact frames (key, ids, counters, bytes) the C++ firmware must reproduce.
- `rangetest/`: sender/receiver firmware for the range test (builds; not yet run on boards).
- `lora/`: C++ frame library, radio wrapper, plug-in gateway firmware and their tests (see above).
- `tools/make_cpp_vectors.py`, `tools/new_device.py`.

Run the tests: `python -m venv .venv`, `.venv\Scripts\pip install cryptography pytest`,
`.venv\Scripts\python -m pytest -q`.

Sources: FCC 47 CFR 15.247; nodakmesh.org, "FCC Part 15.247: The 500 kHz Minimum and LoRa
Mesh"; Semtech SX1261/2 datasheet (time on air, sensitivity); FCC grants listed above.

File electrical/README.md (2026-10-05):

# Electrical monitoring module (roadmap phase 11): design

Measures the outdoor unit's electrical side: compressor and condenser-fan current, line voltage,
the voltage drop across the contactor, and the run capacitor under load. Sold and installed as
a separate module so the core product stays low-voltage.

**Status (2026-10-04):** the cloud side is built and tested with simulated data (the
`electrical` node, ten diagnostic rules, technician and homeowner views, nameplate fields; see
`hvac-cloud/hvaccloud/electrical.py`). No hardware or firmware yet.

> **Line voltage.** Anything that connects to the 208/240 V side must be built and installed by
> a qualified person, with the circuit de-energized and locked out, and the measuring side
> isolated from everything a person or the low-voltage wiring can touch (section 4). Version 1
> below avoids line contact entirely.

## 1. What it catches

| Rule (code) | Needs | Measured how | Level |
|---|---|---|---|
| Compressor not running with the contactor closed (`comp_not_running`) | amps | CT on the compressor common (C) wire | fault |
| Condenser fan not running (`fan_not_running`) | amps | CT on a fan motor lead | fault |
| Cooling call but contactor not closed (`contactor_open`) | contactor state | coil voltage (24 VAC, low-voltage side) or current | fault |
| Compressor amps above RLA (`comp_amps_high`) | amps + nameplate RLA | CT | caution |
| Fan amps above FLA (`fan_amps_high`) | amps + nameplate FLA | CT | caution |
| Slow / hard start (`slow_start`) | inrush peak and duration | CT, sampled fast at start-up | caution |
| Run capacitor outside ±6 % (`cap_herm`, `cap_fan`) | current through the cap and voltage across it | CT on HERM / FAN wire + isolated voltage | caution |
| Contactor drop over 1 V (`contactor_drop`; replace over 2 V) | voltage across the closed contacts | isolated voltage, line vs load side of one pole | caution |
| Line voltage outside the nameplate range (`voltage`) | line voltage | isolated voltage | caution |

Capacitance under load: µF = amps × 2652 ÷ volts (60 Hz), compared with the rating (±6 %).
Contactor: under 1 V across closed contacts is normal (good ones read tens of millivolts); over
2 V means pitted contacts. All rules wait for a minute of compressor call before judging amps.

## 2. Two versions

**Version 1: current only (no line contact).** Clamp-on split-core current transformers (CTs)
on the insulated compressor common and fan leads, plus the contactor coil (24 VAC) for state.
Covers five of the rules (not running, fan not running, contactor not closing, high amps, slow
start). Low-voltage only, so it can be added to the outdoor carrier board's next revision or a
small add-on board, powered with the outdoor node.

**Version 2: adds isolated voltage.** Line voltage, voltage across each run-capacitor section,
and across one contactor pole: the capacitor test, contactor drop and voltage rules. Needs a
separate, isolated measuring board (section 4) and a certification path (section 6).

## 3. Sensors and parts (prototype)

| Part | Use | Notes |
|---|---|---|
| Split-core CT, 100 A (e.g. YHDC SCT-013-000, 50 mA output + burden resistor) | compressor common | 100 A so the start inrush (LRA ~70–110 A) doesn't saturate |
| Split-core CT, 5–10 A | fan lead; HERM lead for the capacitor current | small, accurate at low current |
| Energy-metering IC (e.g. ADE7953 or ATM90E26: RMS current/voltage, waveform sampling) | version 2 voltage + current | does the RMS maths; 24-bit inputs resolve millivolts for the contactor drop |
| Digital isolator + isolated DC-DC (reinforced) | version 2 | separates the line-referenced IC from the ESP32 |
| ESP32 (or the outdoor node's) ADC with a burden resistor | version 1 CT inputs | sample ~2–4 kHz for RMS; catch the inrush peak and duration at contactor close |

Wiring at the condenser: compressor C wire and fan lead through the CTs; the HERM lead through a
small CT for the capacitor current. Version 2 taps: L1/L2 (line side of the contactor), the load
side of one pole, and the capacitor C/HERM/FAN terminals, each through fused, high-value
divider resistors on the isolated board.

## 4. Isolation (version 2)

- The measuring board's ground is a line conductor. Everything on it is treated as live.
- Reinforced isolation between it and the ESP32/low-voltage side: a digital isolator for the
  IC's SPI/UART and an isolated DC-DC (or a transformer-isolated supply) rated for reinforced
  isolation at 300 V working voltage.
- Creepage/clearance on the PCB per the standard (several millimetres for 240 V), slots under
  the isolation barrier, fused inputs, divider resistors rated for the voltage.
- Its own enclosure in the unit's electrical compartment, with strain relief; the CTs clamp on
  insulated wire and don't touch conductors.

## 5. Data (already accepted by the cloud)

The module publishes `hvac/<site>/electrical/telemetry`, every few seconds:

```json
{"node": "electrical", "uptime": 312, "contactor": true,
 "v":   {"line": 241.0, "contactor": 0.05},
 "i":   {"comp": 11.8, "fan": 1.1},
 "cap": {"herm": {"v": 372.0, "i": 6.3}, "fan": {"v": 368.0, "i": 0.69}},
 "start": {"peak_a": 58.0, "ms": 240},
 "err": []}
```

Version 1 sends `null` for the voltages and capacitor values; those rules then don't run. It can
be its own ESP32 or extra fields published by the outdoor node on the `electrical` topic. Over
LoRa it would need its own compact frame type (see `radio/`, branch `radio/lora-design`).

Nameplate values for the rules go on the Equipment page: compressor RLA / LRA, fan FLA, run
capacitor µF (HERM and fan), voltage range (197–253 V assumed for 208/230 V units when empty).

## 6. Certification

Line-voltage measuring equipment needs safety certification before sale: typically UL/IEC 61010-1
(measurement equipment) with 61010-2-030, or UL 60730 if it ends up switching anything. Version 1
(current transformers on insulated wire, low-voltage electronics) is a much smaller step than
version 2. A test lab review of the version 2 isolation design early saves a re-spin.

## 7. Trying it now (no hardware)

```powershell
.venv\Scripts\python.exe demo_publisher.py --site demo --electrical --fault weak_cap
```

Faults: `weak_cap`, `pitted_contactor`, `fan_dead`, `comp_tripped`, `low_voltage`, `slow_start`
(or `none`). Enter RLA 14.1, LRA 73, fan FLA 1.4, capacitor 45/5 µF on the demo system's
Equipment page. Each fault raises its one flag in the technician view, the alert log and the
homeowner page.

## Next

1. Decide whether version 1 goes on the outdoor carrier rev B or a separate add-on board.
2. Prototype version 1: two CTs + burden resistors into the outdoor ESP32, firmware to sample
   RMS current and catch starts, publish on the `electrical` topic.
3. Version 2 isolated board design, then a test-lab review.

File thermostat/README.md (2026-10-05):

# Fullscope display thermostat (roadmap phase 11)

An optional add-on that replaces the customer's existing thermostat. Fullscope already watches
the equipment; owning the thermostat as well lets it compare what was asked for with what
happened, adjust the schedule remotely, and give the contractor one place to see both.

**Status:** design, cloud side, screen preview and firmware (on main). The firmware builds
for the Waveshare board, and its control logic is tested on the PC. Nothing has run on hardware
yet.

## The rule that shapes everything

**All control and safety logic runs on the thermostat.** The cloud only stores settings and
sends them down. With the internet, WiFi or the cloud down, the thermostat keeps heating and
cooling with the last settings it received and its own clock, and it never needs the cloud
to stay safe.

## How the pieces fit

```
 web app ── PUT /thermostat, POST/DELETE /thermostat/hold, PUT /thermostat/tech
    │
 cloud API ── stores ThermostatConfig (settings, tech, version)
    │         publishes the whole config, retained:  hvac/<site>/thermostat/config
    ▼
 thermostat ── runs the control loop every few seconds (Controller)
    │          reports every 5 s:                       hvac/<site>/thermostat/telemetry
    ▼
 ingest ── stores the report; the next indoor/outdoor snapshot carries it ("tstat")
           plus its diagnostics (room too hot/cold, setpoint not reached, call mismatch)
```

- **Config** is versioned: every change bumps `ver`. The thermostat reports the `cfg_ver` it is
  running, so the web app can show "Sending to the thermostat…" until it matches. Because the
  message is retained, a thermostat that was offline gets the latest config as soon as it
  reconnects.
- **Outdoor temperature** for the heat-pump lockouts comes from the outdoor node over the local
  broker (`hvac/<site>/outdoor/telemetry`). If it's missing, the lockouts that depend on it
  are skipped. The safe direction: aux heat is allowed and the compressor isn't locked out.
- **Time** comes from NTP, as on the nodes (firmware 0.2). The schedule is in the house's time
  zone (`tech.tz`). The firmware converts the IANA name to a POSIX TZ string.

## The screen

Three tabs on the 800 × 480 touchscreen. `hvac-cloud/web/thermostat.html` is a browser preview of
the screen, driven by a system's live data; open it from the thermostat card ("See the
thermostat's screen") or from the Equipment page.

- **Home:** room temperature, setpoint −/+, mode, what it's doing ("Cooling to 76°", "Protecting
  the compressor"), schedule or hold with Resume. Top bar: clock, outdoor temperature, humidity
  and the monitoring status ("System OK", "Check soon"), which opens Alerts.
- **Alerts (homeowner):** the monitoring system's open alerts in plain words, the same as the
  emails. Tap one for why it matters and what to do. Beside them are the System health areas,
  as on the homeowner web page, plus Comfort.
- **Service (technician, behind the service PIN):**
  - top: key numbers (mode and run time, superheat, subcooling, delta-T, suction, liquid, line
    volts, compressor amps), outlined when one has an alert
  - middle: a trend of suction and liquid pressure, and return, supply and outdoor air, over
    1 or 6 hours, with the compressor's run times along the bottom and shaded, numbered markers
    where the electrical module found a problem (weak capacitor, pitted contactor, high amps,
    voltage…)
  - bottom: the open diagnostics in technical words

  It locks again after 5 minutes without a touch. The PIN is set on the Equipment page
  (default 0000).

### The display feed

The cloud does the diagnosing, so the thermostat only draws. Ingest publishes a feed, retained,
on `hvac/<site>/thermostat/display`: at most once a minute, and at once when an alert is raised
or cleared. It is built by `hvaccloud/display.py` and is also available at
`GET /api/systems/{id}/thermostat/display`. Contents:

- status and headline
- open alerts: plain title, why, what to do, technical text, since when
- health areas
- key numbers
- the 6-hour trend at 2-minute steps
- electrical markers: code, label, start, end

It is about 6 KB. The firmware needs an MQTT buffer of at least 16 KB.

Alerts on the screen are the raised ones (5-minute hold), so it doesn't flicker. Problems that
can only be checked while the unit runs (refrigerant, delta-T, the electrical checks) stay
shown between cycles. They clear only when a later run shows them gone.

## Settings

Homeowner (`settings`): `mode` (off, heat, cool, auto, emergency_heat), `fan` (auto, on,
circulate), `heat_sp`, `cool_sp`, `schedule` (weekly periods: `{"days": [0-6], "at": "HH:MM",
"heat": 68, "cool": 78}`, Monday = 0) and `hold` (`{"heat", "cool", "until"}`; `until` null =
until resumed).

Technician only (`tech`; Equipment page): `has_aux`, `tz`, `service_pin`, `differential`, `min_on_s`,
`min_off_s` (at least 120 s), `max_starts_h`, `comp_lockout_f`, `aux_lockout_f`, `aux_droop_f`,
`aux_delay_s`, `fan_purge_s`, `circulate_min_h`. Allowed ranges are in `TECH_LIMITS`.
`heat_pump` and `ob_energized` come from the system's Equipment settings, so they are set in
one place.

## Control rules (reference: `hvac-cloud/hvaccloud/thermostat.py`, `Controller`)

The firmware implements the same rules. `tests/test_thermostat.py` checks them, including every
step of simulated random days:

| Rule | Detail |
|---|---|
| Hysteresis | A call starts at setpoint ± half the differential and ends at ∓ half |
| Auto mode | Cooling setpoint at least 3 °F above heating |
| Compressor minimum off | No restart within `min_off_s` (floor 120 s) |
| Compressor minimum run | Once started, runs `min_on_s` unless the mode is switched off |
| Starts per hour | At most `max_starts_h` |
| Reversing valve | Set only while the compressor is off, just before it starts |
| Compressor lockout | Heat pump below `comp_lockout_f` outdoors: aux heat only |
| Aux heat | Joins after the room has been `aux_droop_f` below setpoint for `aux_delay_s`, only at or below `aux_lockout_f` outdoors; emergency heat = aux only |
| Blower | On with any call, for `fan_purge_s` after it, always (fan on), or `circulate_min_h` minutes an hour |
| Sensor fail-safe | Room reading missing or outside 32–120 °F: all outputs off |

## Hardware (proposed)

- **MCU + display:** ESP32-S3 with a 3.5–4.3" capacitive touchscreen (an off-the-shelf
  ESP32-S3 display module to start), WiFi built in. Its FCC-certified radio module keeps the
  Part 15 work to a modular-approval check. Later it could double as the LoRa gateway for the
  monitors (see the radio design).
- **Power:** from R and C (24 VAC), rectified, then a buck converter to 3.3 V. Version 1
  requires a C wire. "Power stealing" without C is a later option, with known problems on some
  equipment.
- **Outputs:** Y, W, G, O/B, each a solid-state switch rated for 24 VAC loads (PhotoMOS relay,
  or opto-triac plus triac). They are open on reset and power loss, with a hardware watchdog
  that drops all outputs if the firmware stops servicing it. A second compressor stage (Y2) and
  aux stage (W2) are left for later.
- **Room sensor:** SHT4x on a tab thermally isolated from the board, with self-heating
  compensation for the display and regulator (calibrated against a reference in the
  enclosure).
- **Terminals:** R, C, Y, W, G, O/B, labelled like a standard thermostat sub-base.

## Diagnostics the cloud adds (on top of the monitors' and the electrical module's)

| Code | When | Level |
|---|---|---|
| `room_hot` | Room ≥ 90 °F | Service needed |
| `room_cold` | Room ≤ 50 °F | Service needed |
| `setpoint_not_reached` | Calling ≥ 90 min and still ≥ 2 °F off target | Check soon |
| `call_mismatch` | Thermostat's Y differs from the Y the indoor node sees (alerts after the usual 5-min hold) | Check soon |
| `node_offline` (node thermostat) | No thermostat report | Good to know |

`call_mismatch` is the one only Fullscope can do: it catches a broken wire or a stuck relay
between the thermostat and the equipment.

## Certification and liability (to confirm with a compliance lab)

- **UL 60730-1 / UL 60730-2-9** (automatic electrical controls, temperature-sensing controls)
  is the usual listing for a line-voltage-free 24 V thermostat sold in the US. It covers the
  software class for the safety functions above, which is why they are kept small and
  separately tested.
- **FCC Part 15:** a pre-certified WiFi module plus unintentional-radiator testing of the
  finished product.
- **Optional later:** ENERGY STAR connected-thermostat certification (needs a data-sharing
  API) and California Title 24 JA5 (occupant-controlled smart thermostat; demand-response
  signals).
- Installation by the contractor, using the existing thermostat wires. No line-voltage work.

## Firmware (`firmware/`, PlatformIO)

```
pio test -e native         # the control logic on this PC (needs a host g++, e.g. MSYS2 ucrt64)
pio run -e waveshare43     # build for the Waveshare ESP32-S3-Touch-LCD-4.3
```

- **`lib/tstat_core`**: the controller, schedule, holds, config parsing, telemetry and the
  display-feed parser. It is a line-by-line port of `hvaccloud/thermostat.py`, with no Arduino
  code. `tools/make_vectors.py` runs the Python Controller through four scenarios, 32,400 steps:
  - cooling with a schedule and holds
  - a heat-pump winter with aux heat, emergency heat and lockouts
  - auto mode with mode changes and sensor glitches
  - a furnace with AC

  The C++ must give the same outputs at every step. Holds made on the screen are checked against
  Python too, including month, year and leap-day rollovers. `tools/make_feed_sample.py` produces
  a real display feed for the parser test.
- **`src/`**:
  - `main.cpp`: every 2 s read the room, step the controller, set the outputs; report every 5 s;
    feed the watchdog every 200 ms
  - `io.cpp`: SHT45; MCP23017 outputs, state sensing and watchdog
  - `net.cpp`: WiFi, MQTT, NTP, time zone; settings kept in flash
  - `display.cpp`: LovyanGFX RGB panel, GT911 touch, CH422G backlight and resets
  - `ui.cpp`: the three LVGL screens
- **Safety details:**
  - The controller runs on the chip's monotonic clock, so the wall clock jumping when NTP first
    sets it can't cut short a minimum-off time.
  - Until the clock is set, the schedule and timed holds are suspended, and it runs the base
    setpoints.
  - Tech values from the cloud are clamped to the safe limits on the thermostat too.
  - Three failed room readings in a row turn everything off.
  - Settings are kept in flash, so it runs the last settings after a power cut with no
    internet.
- **Changes made on the screen** (−/+, mode, resume):
  - They are applied at once and saved under the same version, so a stale retained config can't
    undo them.
  - They are sent on `hvac/<site>/thermostat/request`, 1.5 s after the last tap. The cloud merges
    them into the stored settings (`thermostat.apply_request`), bumps the version and sends the
    config back.
  - The thermostat only applies a config newer than the one it has.
- **Before the first power-up:**
  - Copy `include/config.example.h` to `include/config.h` and fill it in.
  - Check the display pin numbers in `include/board.h` against Waveshare's schematic.
  - Calibrate `ROOM_OFFSET_F` against a reference thermometer once the case is closed.

## Trying it without hardware

```
python demo_publisher.py --site demo --thermostat
```

This simulates a house whose room temperature drifts toward the outdoor temperature. The
reference controller runs it, following the config the cloud publishes. Changing the setpoint,
mode or schedule in the web app changes what the simulated equipment does, and the
indoor/outdoor readings follow.

## Open questions

- Version 1 display hardware: a module (faster) or a custom board with the carrier design
  (cheaper at volume)?
- Editing the whole schedule on the thermostat itself. Setpoint, mode and resume changes already
  go back to the cloud as requests; schedule edits would use the same path.
- Demand response and utility programs: which ones the target market's contractors care about.

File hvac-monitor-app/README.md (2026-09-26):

# HVAC Monitor — PC dashboard

Receives data from the ESP32 nodes over MQTT, stores it, calculates saturation
temperatures, superheat, subcooling and air delta-T, and shows it all live in your browser.

## Start it (Windows)
1. Install **Python 3.12** from python.org. On the first installer screen, tick **"Add python.exe to PATH"**.
2. Keep Mosquitto running (the `mosquitto -c hvac.conf -v` window).
3. Double-click **`start.bat`**. The first run sets up a Python environment and installs two packages
   (paho-mqtt and CoolProp), which takes a minute. It also builds the refrigerant tables once.
4. Your browser opens **http://localhost:8080**.

Want to look around before the hardware is wired? Double-click **`start-demo.bat`** for simulated data.

You can open the dashboard from your phone on the same WiFi at `http://<your-PC-IP>:8080`
(allow Python through Windows Firewall on private networks when asked).

## What it calculates
| Mode | Low side | High side | Superheat | Subcooling |
|---|---|---|---|---|
| Cooling | vapor port | liquid line | suction line temp − dew point | bubble point − liquid line temp |
| Heating (heat pump) | true suction | vapor line (discharge) | true-suction temp − dew point | bubble point − liquid line temp |

Also: air ΔT (return − supply), condensing temperature over ambient, and liquid approach (cooling).
Mode comes from the Y, W, G and O/B inputs. Heating superheat appears once the true-suction
transducer and thermistor are installed and marked as fitted.

Refrigerants: R-410A, R-32, R-454B, R-22, R-134a, R-407C. Blends use separate bubble and dew curves.

## Setup panel
- **Refrigerant** for the connected system
- **Heat pump / air conditioner**
- **Reversing valve:** O (energized in cooling, most brands) or B (energized in heating)
- **Atmospheric pressure:** 14.7 at sea level, about 14.0 around 1,200 ft. Gauge readings are converted to absolute for the tables.

Settings are saved in `config.json`. MQTT broker address, site ID and web port can be changed there too.

## Calibration panel
Sends the calibration commands to the nodes (zero, span, temperature reference, reset, mark
sensor installed). Replies from the node appear in the log below the form.

## Data
Stored in `hvac_data.db` (SQLite), kept for 90 days. **Export CSV** downloads the selected time range.

## Flags
Conservative first-pass checks, judged only after 10 minutes of steady running: floodback risk,
high or low superheat and subcooling, low air ΔT, high condensing-over-ambient, plus offline nodes
and sensor faults. Thresholds live in `Hub.flags()` in `server.py`.

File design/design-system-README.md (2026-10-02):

# Fullscope

Fullscope is the interface of a residential HVAC monitoring and diagnostic system for contractors and service technicians. ESP32 nodes on the refrigerant and air sides of a split system report over MQTT; the software calculates saturation temperatures, superheat, subcooling, delta-T, static pressure and capacity, and interprets them. It should read like a professional service instrument: calm, dense, exact. It is a tool, not a marketing site.

## Brand

- **Name**: Fullscope. **Tagline**: *Continuous diagnostics & control* — written in sentence case in running text; the logo itself sets it in capitals.
- **Logo**: chrome wordmark with a green reticle. Files in the Logos group: the full lockup with tagline and the wordmark alone, each as the original on black and as a transparent PNG. The artwork is light chrome and glow, so the transparent version only works on dark grounds — never place it on white or light grey; use the black original there.
- **In the UI** the transparent wordmark sits at the left of the header bar, which is dark (`bar-*` tokens) in both themes so the logo always has its ground. The tagline is set as text in the logo's style — tracked capitals (`.caps`, 0.18em) — the one place the UI uses all caps. Below about 120px wide the tagline in the lockup is unreadable, so use the wordmark and set the tagline as text beside it.
- **Brand colours** (`brand-black`, `brand-chrome`, `brand-green`) belong to the logo and brand surfaces only. The UI never uses the reticle green — green in the UI means *ok*, and a neon brand green next to state colours would blur that.

The **Monitor** screen (component `Dashboard`) is the reference layout. Everything else in this system is a piece of it.

## The four questions

The Monitor screen is ordered so a technician can answer, top to bottom:

1. **What is the system doing right now?** — status bar: mode and thermostat calls (Y G O W), node links, last update, outdoor air, runtime.
2. **Are refrigerant conditions normal?** — summary strip (superheat, subcooling) and the unified refrigerant table.
3. **Is the air side performing?** — delta-T, TESP, airflow, capacity; the air-side table with static pressure.
4. **Is anything wrong?** — diagnostics counts in the status bar, the diagnostics table with evidence.

## Raw → calculated → interpretation

This is the product's core rule. Never hide a measurement behind a score.

| Layer | Where it appears | Marker |
|---|---|---|
| Raw measurement | Tables, trend, sensor health | `MEAS` tag (solid outline) |
| Calculated value | Tables, summary strip, trend "Calculated" lane | `CALC` tag (dashed outline) |
| Configured value | Airflow, targets, limits | `CFG` tag |
| Interpretation | Only status words (Normal / Above target / High) and the diagnostics table | state glyph + word |

Diagnostics always show their evidence and use hedged language: "Possible airflow restriction", never "Airflow is restricted". Each row expands to *what triggered it*, *current vs expected*, *how long*, and *possible causes ranked by evidence*.

## Voice

- Sentence case everywhere; no all-caps headings. Short tags (`MEAS`, `CALC`, `Y`, `O`) and the tagline are the only uppercase.
- Units always, and always visually secondary: `128.4 psig`, `12.4 °F`, `0.72 in. w.c.`, `1,400 CFM`, `34,900 BTU/hr`. Negative static uses a true minus (−0.28); positive static carries a plus (+0.44).
- Don't imply precision you don't have: capacity rounds to 100 BTU/hr and states its airflow source.
- Missing optional sensors say "Not installed", in `ink-faint` — never a fault. Only a sensor configured as required can raise a fault.

## Visual foundations

- **Dark first**, charcoal not black (`bg`, `surface`, `surface-2`, `surface-3`, `inset` for chart wells). A light theme exists for bright rooms and printing.
- **Structure from lines, not cards.** Hairlines (`line`) divide rows and cells; panels have a 1px outline and `radius-2` (3px) at most. No shadows, gradients, glows or glass.
- **Colour means state.** `ok`, `caution`, `fault`, `advisory`, `sensor`, `offline`. Every state is also a glyph shape (● ▲ ■ ◆ ✕ ○) plus a word, so it survives colour blindness and greyscale printing. A non-normal summary cell gets a 2px top rule in its state colour; a warning cell also gets `caution-soft` behind it.
- **Low vs high side** are told apart by a 2px rule under the column header (`side-low` steel, `side-high` copper) and by line colour in the trend — never by filling whole areas blue and red.
- **Type**: everything is set in DIN, the face of the logo's tagline — D-DIN (open licence, DIN 1451) loaded as a web font on every device, Bahnschrift (Microsoft's DIN 1451, built into Windows) as the fallback. One family for all text, including tags, ids and numbers; D-DIN has regular and bold, so headings are bold and values regular. Self-host the D-DIN files before production rather than relying on a public font CDN.
- **Numbers**: tabular numerals everywhere (`font-feature-settings: "tnum"`). The value dominates; label above in `ink-muted`; target and source below in `caption`.
- **Density**: 13px body, 6px/12px cell padding, 12px gaps. Designed for a 13–16" laptop at 1366–1440 wide; collapses to two and then one column for tablets.

## Trend chart

Stacked lanes sharing one time axis (pressure, temperature, calculated, static, capacity), each with its own scale — the SCADA/oscilloscope pattern, not dual-axis overlays. A `Y` run bar on top shows compressor calls. Presets (Refrigerant, Air side, Pressure, Temperature, Performance, All) choose channels; the legend is also the live readout and switches to cursor values on hover. Saturation temperatures are dashed in their side's colour. Configured limits (max ESP) draw as dashed `caution` lines; targets as a faint band.

## Homeowner view

A second screen (group **Homeowner**) for the people who live with the equipment. Same tokens and state colours; different rules:

- **Plain language, no jargon.** "Air may be restricted", not "High TESP". Level words map to states: *Good* (`ok`), *Good to know* (`advisory`), *Check soon* (`caution`), *Service needed* (`fault`), *Offline* (`offline`). A sensor error is told to the homeowner as *Good to know* with "your contractor has been notified".
- **One headline, one next action.** The top card says what the system is doing and what to do about it, in a sentence.
- **Few numbers, all everyday ones**: inside and outside temperature, air from the vents, hours run. Pressures, superheat and static stay in the technician view; the one number a contractor needs appears once in a "For your contractor" line.
- **Still hedged.** "May be", "most often" — the same honesty as the technician diagnostics.
- **No health score.** Health is five named areas each with a word; the bar counts areas, it doesn't grade.
- Larger type (15px body, 28px headline) and more space than the technician view; one column below 860px, built for phones first.

## Iconography

None beyond state glyphs, a checkbox and a chevron. Text labels do the work.

## Extending

New measurements (compressor amps, voltage, filter ΔP, coil ΔP, extra probes) are new rows in an existing table and new channels in an existing lane; new systems or sites go in the status-bar system selector. Don't add cards.

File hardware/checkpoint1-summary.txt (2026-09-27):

=== outdoor-carrier: 46 components, 25 nets, 0 mismatches

J1  24 VAC
   1 R     VAC_IN     F1.1
   2 C     GND        32 pins

U2  LM2596HV
   1 IN+   VRAW       C1.1, C2.1, D2.1
   2 IN-   GND        31 pins
   3 OUT+  +5V        5 pins
   4 OUT-  GND        31 pins

U1  ESP32 DevKit
   4 D34   MODE_Y     R12.2, U5.5
   5 D35   MODE_OB    R14.2, U6.5
  14 GND   GND        31 pins
  15 VIN   +5V        5 pins
  17 D22   SCL        J8.4, U3.3, U4.3
  20 D21   SDA        J8.3, U3.4, U4.4
  29 GND   GND        31 pins
  30 3V3   +3V3       9 pins
  not connected: 1:EN, 2:VP, 3:VN, 6:D32, 7:D33, 8:D25, 9:D26, 10:D27, 11:D14, 12:D12, 13:D13, 16:D23, 18:TX0, 19:RX0, 21:D19, 22:D18, 23:D5, 24:TX2, 25:RX2, 26:D4, 27:D2, 28:D15

U3  ADS1115 0x48
   1 VDD   +3V3       9 pins
   2 GND   GND        31 pins
   3 SCL   SCL        J8.4, U1.17, U4.3
   4 SDA   SDA        J8.3, U1.20, U4.4
   5 ADDR  GND        31 pins
   7 A0    P_LIQ      C3.1, R1.2, R2.1
   8 A1    P_VAP      C4.1, R3.2, R4.1
   9 A2    P_TSUC     C5.1, R5.2, R6.1
  10 A3    V5_MON     C6.1, R7.2, R8.1
  not connected: 6:ALRT

U4  ADS1115 0x49
   1 VDD   +3V3       8 pins
   2 GND   GND        32 pins
   3 SCL   SCL        J8.4, U1.17, U3.3
   4 SDA   SDA        J8.3, U1.20, U3.4
   5 ADDR  +3V3       8 pins
   7 A0    T_SUC      C7.1, J6.1, R9.2
   8 A1    T_LIQ      C8.1, J7.1, R10.2
   9 A2    T_TSUC     C9.1, J9.1, R15.2
  10 A3    T_DIS      
  not connected: 6:ALRT

J8  SHT30 FS400
   1 3V3   +3V3       9 pins
   2 GND   GND        32 pins
   3 SDA   SDA        U1.20, U3.4, U4.4
   4 SCL   SCL        U1.17, U3.3, U4.3

J3  XDB307 liquid
   1 +5    +5V        5 pins
   2 SIG   P_LIQ_IN   R1.1
   3 GND   GND        32 pins

J4  XDB307 vapor
   1 +5    +5V        5 pins
   2 SIG   P_VAP_IN   R3.1
   3 GND   GND        32 pins

J5  XDB307 t.suction
   1 +5    +5V        5 pins
   2 SIG   P_TSUC_IN  R5.1
   3 GND   GND        32 pins

J6  TH1 suction
   1 TH    T_SUC      C7.1, R9.2, U4.7
   2 TH    GND        32 pins

J7  TH2 liquid
   1 TH    T_LIQ      C8.1, R10.2, U4.8
   2 TH    GND        32 pins

J9  TH3 t.suction
   1 TH    T_TSUC     C9.1, R15.2, U4.9
   2 TH    GND        32 pins

J2  Mode in 24 VAC
   1 Y     Y_24V      R11.1
   2 O/B   OB_24V     R13.1

=== indoor-carrier: 29 components, 21 nets, 0 mismatches

J1  24 VAC
   1 R     VAC_IN     F1.1
   2 C     GND        18 pins

U2  LM2596HV
   1 IN+   VRAW       C1.1, C2.1, D2.1
   2 IN-   GND        17 pins
   3 OUT+  +5V        1 pins
   4 OUT-  GND        17 pins

U1  ESP32 DevKit
   2 VP    MODE_G     R7.2, U5.5
   3 VN    MODE_OB    R9.2, U6.5
   4 D34   MODE_Y     R3.2, U3.5
   5 D35   MODE_W     R5.2, U4.5
  14 GND   GND        17 pins
  15 VIN   +5V        1 pins
  17 D22   SCL        J5.4
  20 D21   SDA        J5.3
  26 D4    ONEWIRE    J3.2, J4.2, R1.2
  29 GND   GND        17 pins
  30 3V3   +3V3       8 pins
  not connected: 1:EN, 6:D32, 7:D33, 8:D25, 9:D26, 10:D27, 11:D14, 12:D12, 13:D13, 16:D23, 18:TX0, 19:RX0, 21:D19, 22:D18, 23:D5, 24:TX2, 25:RX2, 27:D2, 28:D15

J3  DS18B20 supply air
   1 3V3   +3V3       8 pins
   2 DQ    ONEWIRE    J4.2, R1.2, U1.26
   3 GND   GND        18 pins

J4  DS18B20 return air
   1 3V3   +3V3       8 pins
   2 DQ    ONEWIRE    J3.2, R1.2, U1.26
   3 GND   GND        18 pins

J5  I2C expansion (DNP)
   1 3V3   +3V3       8 pins
   2 GND   GND        18 pins
   3 SDA   SDA        U1.20
   4 SCL   SCL        U1.17

J2  Mode in 24 VAC
   1 Y     Y_24V      R2.1
   2 W     W_24V      R4.1
   3 G     G_24V      R6.1
   4 O/B   OB_24V     R8.1

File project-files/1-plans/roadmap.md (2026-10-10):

# HVAC Monitor Roadmap

Sep 24, 2026 · @Tyler

## Overview

Phase 0 is done and Phase 1 is under way. The design, firmware (0.1.0 on the dev boards, 0.2.0 ready to flash), PC dashboard, rev A carrier boards and the cloud stack with its web app are all built. Both nodes are flashed and online, and the rev A carrier boards have arrived from JLCPCB and are assembled. Waiting on the pressure sensors.

Phases run in order. Customer discovery and IP protection run alongside the build from now on. Tick items as you finish them.

## Phase 0: Design groundwork (done)

- [x] Sensor selection and parts list
- [x] Rev A wiring schematics, outdoor and indoor nodes
- [x] Firmware 0.1.0 builds cleanly; the cloud uses its existing MQTT topics, so no separate cloud mode is needed
- [x] PC dashboard app with refrigerant tables
- [x] Mosquitto broker running, ESP32 connected over MQTT
- [x] Cloud stack rebuilt (database, ingest, API) with the Fullscope web app: homeowner and technician views
- [x] Rev A carrier boards designed in KiCad and ordered from JLCPCB (release hardware-rev-a)

## Phase 1: Bench bring-up

- [ ] Build the three 24 VAC to 5 V power supplies
- [ ] Set each LM2596HV to 5.00 V before connecting loads
- [x] Flash both boards and confirm WiFi (2.4 GHz) and MQTT with the PC app
- [ ] Assemble and bench-test one outdoor and one indoor carrier board before building the spares

## Phase 2: Outdoor node on the bench

- [ ] Wire the ADS1115s, dividers, XDB307 transducers, thermistors and SHT30
- [x] Firmware takes the divider resistor values from config.h, so the outdoor board can be built with 10k in place of the 20k and 15k (set for your build); it refuses values that would overdrive the ADC
- [ ] Build notes: 5% resistors are fine for the opto inputs and pull-ups; use 1% for the dividers and 1% (or 0.1%) 10k for the thermistor references, then set v33, check the thermistors' B value and ice-bath each probe; unmarked H11AA1s: find pin 1 with a meter's diode test (the LED pair reads ~1.1 V both ways)
- [ ] Wire the Y and O/B opto inputs
- [ ] Zero the transducers open to atmosphere (use the Sensors & calibration page for this and the steps below)
- [ ] Span against the Fieldpiece on nitrogen at about 300 psi, then check 100, 200 and 400 psi
- [ ] Measure the 3V3 pin and set v33; calibrate thermistors in an ice bath
- [ ] Test Y and O/B with 24 VAC

## Phase 3: Indoor node on the bench

- [ ] Wire the DS18B20 probes and the Y, W, G and O/B inputs
- [ ] Calibrate both probes in an ice bath; swap supply/return if reversed
- [ ] Confirm the delta-T reading in the dashboard

## Phase 4: Install on your own system

- [ ] Mount nodes in shaded, vented, light-colored enclosures outside the cabinets
- [ ] Braze in the true-suction access fitting (or defer to Phase 6)
- [ ] Set atmospheric pressure to about 14.0 psia in the PC app
- [ ] Run through several weeks of real cooling cycles and log the data

## Phase 5: Validate the diagnostics

- [ ] Compare superheat, subcooling and delta-T against your own gauge readings
- [ ] Tune the alert thresholds from real data
- [x] Equipment page in the web app, and nameplate subcooling targets for TXV/EEV systems (cloud; the PC dashboard keeps the generic limits)
- [ ] Add charging-chart target superheat for piston systems (needs indoor humidity from Phase 6)

## Phase 6: Complete the V1 sensors

- [ ] Buy and fit the third XDB307 (0–35 bar) and a thermistor at true suction
- [ ] Enable them with the fitted command; confirm heating-mode superheat
- [ ] Add 3× SDP810-500Pa static pressure sensors with a TCA9548A mux
- [ ] Add SHT45 supply and return humidity (enables piston target superheat and capacity estimates)
- [ ] Update firmware and schematics to rev B

## Phase 7: Cloud stack, running locally

- [x] Run the cloud locally without Docker (SQLite): the HVAC Monitor shortcut now starts the ingest worker and the Fullscope web app at localhost:8000
- [x] Web app restyled to the Fullscope design system: logo on a dark header bar, dark-first theme, D-DIN type self-hosted (no font CDN)
- [x] Sensors & calibration page in the web app: zero, span, ice bath, channels on/off and node settings sent to the nodes from the browser, with each node's reply logged
- [x] Nightly backup of the local database (keeps 7) and cleanup of old data: full detail for 30 days, then 1-minute averages, deleted after a year
- [x] Homeowner maintenance card: filter reminder by days or actual blower run time, tune-up reminder, service contractor details and a Request service button
- [x] Service history: log visits with the readings at the time; tune-ups and filter changes reset the reminders, and homeowners see recent visits
- [x] Install WSL and Docker Desktop (a restart, and accepting Docker's license), then start the TimescaleDB stack (tested: hypertables with 365-day retention, broker logins, data through to the API; broker passwords now come from .env)
- [x] Create your account and system with manage.py
- [ ] Register both nodes: they appear on their first message once powered and online (no firmware change needed, same MQTT topics)
- [ ] Confirm history, alerts, email and remote calibration all work (all built; needs the nodes online and alert email set up)

## Phase 8: Go live in the cloud

- [x] Production setup built and tested on the PC: HTTPS through Caddy, MQTT over TLS (port 8883) with a private CA, secure cookie, daily database backups with a tested restore, and a deployment checklist (DEPLOY.md)
- [ ] Rent a server and register a domain
- [ ] Deploy with DEPLOY.md (about an hour once the server and domain exist; HTTPS and the secure cookie come with it)
- [x] Firmware 0.2.0 written and built for both nodes: MQTT over TLS, timestamped readings with a 10-minute outage buffer, settings sent back after changes (cloud and dashboard store caught-up readings at their own time)
- [ ] Flash firmware 0.2.0 at carrier-board bring-up, then test TLS, the clock sync and the outage buffer on real hardware
- [x] Per-user sign-in with contractor and homeowner roles (email and password, secure session cookie; homeowners see only their own system)
- [x] Invite links for homeowners and contractor colleagues, and a contractor Fleet page listing every system, most in need of attention first
- [x] Review of the cloud code for bugs and security: 8 fixes (alert emails now reach homeowners, password change signs out other sessions, remove colleagues, invite tokens kept out of logs, and smaller hardening)
- [x] Password reset: emailed one-time link, or a link the contractor makes for a homeowner when email is off
- [ ] Move sign-in to a managed provider (Auth0 or Clerk) for password reset, two-factor and phone-friendly login
- [x] Build alerts: a fault lasting 5 min raises an alert, "no data" after 10 min of silence, alert lists in the web app, email with a 6 h cooldown
- [x] Alert recipients (owner and/or contractor; plain-language emails for the owner, technical for the contractor), acknowledge, and mute by alert type
- [x] Alerts for checks that only run while the system runs (refrigerant, delta-T) stay open between cycles instead of clearing every time the compressor stops: one problem, one alert, no "back to normal" email each cycle
- [ ] Turn on alert email (SMTP account and recipient address), and copy the server's daily backups (built) and the CA key off the server regularly

## Decision point: 900 MHz radio architecture (before Phase 9)

Sheet-metal cabinets and homeowner WiFi are the weak points for nodes at the condenser and in the attic. Honeywell's RedLINK solves the same problem with a 900 MHz link to a gateway. Proposed design: the outdoor and indoor nodes each carry a LoRa radio and talk to a gateway that connects to the network. The standard gateway is a plug-in unit; the optional display node, which replaces the existing thermostat, has the gateway built in. Example: a two-story house with the air handler in the attic, where neither equipment node sits near the router.

- [x] Research the US rules: a fixed LoRa channel must be 500 kHz wide (or hop across 50+ channels). Chosen: one 500 kHz channel at SF9, 77 ms per reading, about 143 dB link budget (design in radio/README.md)
- [ ] Buy 3 Heltec WiFi LoRa 32 V3 boards (915 MHz) and prototype the link (range-test firmware is written and builds)
- [ ] Range-test on your own house: attic, condenser and thermostat location, antennas outside the cabinets
- [x] Define a compact telemetry format that fits LoRa airtime limits: 45-byte encrypted frames that decode to the same JSON, so the cloud needs no changes (tested reference in radio/lorafmt.py)
- [x] Gateway buffers readings and forwards them to the cloud over WiFi (written and merged into main Oct 4, not yet run on radios: a plug-in gateway for a Heltec V3, or the thermostat as the gateway, which also feeds the outdoor temperature to the controller offline)
- [x] LoRa firmware for the nodes (LORA\_ENABLED in config.h: readings, status and calibration commands over the radio), with the frame format and encryption ported to C++ and checked byte for byte against the Python reference; each site picks one of 8 channels from its site id; a tool makes each node's id and key
- [x] Keep a WiFi-direct mode for installs without a display node (kept: WiFi stays the default; LoRa is a config switch)
- [ ] Confirm the production module's FCC grant covers 500 kHz operation (candidates with modular approval: Heltec HT-CT62, Seeed Wio-SX1262, RAK3172)
- [ ] Decide: LoRa + gateway, WiFi only, or cellular (use the contractor interviews)

## Phase 9: Productize the device

- [ ] Custom PCB in KiCad combining power, ADCs, optos and the LoRa radio (JLCPCB)
- [ ] Route each equipment node's antenna outside the cabinet
- [ ] Plug-in gateway (standard with every system): LoRa to both nodes, WiFi to the cloud
- [ ] Decide on ESP32-C5 for the gateway's WiFi (adds 5 GHz support)
- [ ] Enable secure boot and flash encryption
- [ ] Load unique device credentials at manufacturing
- [ ] Bluetooth WiFi setup for the gateway from a phone, with QR claim codes that pair all devices
- [ ] Cloud firmware updates, relayed through the gateway to the nodes
- [ ] Local buffering during outages (nodes keep 10 minutes since firmware 0.2; longer storage and the gateway still to do)
- [ ] Heat-rated production enclosures

## Phase 10: Pilot

- [ ] Install on 5–10 systems with a friendly contractor
- [ ] Fix reliability issues found in the field
- [ ] Refine the contractor portal from their feedback
- [ ] Invite homeowners as viewers (invite links are built)

## Phase 11: Optional add-ons

### Display thermostat (replaces the existing thermostat)

- [x] Software side built (merged into main Oct 4): control and safety logic that runs on the thermostat itself (minimum off and run times, starts per hour, reversing valve switched only at rest, compressor and aux heat lockouts by outdoor temperature, emergency heat, sensor fail-safe), weekly schedule and holds, settings sent to the thermostat as a retained, versioned config, homeowner thermostat card, technician safety settings on the Equipment page, new alerts (room too hot or cold, setpoint not reached, thermostat and equipment disagree), a simulator; design in thermostat/README.md
- [x] Thermostat screen designed (browser preview at the real 800 × 480 size): Home; Alerts for homeowners (the monitoring system's alerts in plain words, System health areas, tap for what to do); Service for technicians behind a PIN (key numbers, pressure and air trend over 1 or 6 hours with markers where electrical problems were found, open diagnostics). The cloud sends the thermostat a ready-to-draw feed. Run-only alerts now stay open between cycles instead of clearing each time the compressor stops
- [x] Thermostat firmware written (builds for the Waveshare ESP32-S3 4.3" board, not yet run on hardware): the control and safety logic ported to C++ and checked against the Python version at every one of 32,400 simulated steps; screens, room sensor, output switches, hardware watchdog, settings kept in flash; changes made on the thermostat work offline and sync back to the cloud
- [ ] ESP32-S3 touchscreen with the gateway built in (LoRa + WiFi), so no separate plug-in gateway is needed
- [ ] Output relays for Y, Y2, W, W2, G and O/B, powered from R and C
- [ ] Scheduling, setpoints and heat pump / aux heat staging
- [ ] Safety logic: compressor minimum off time, short-cycle protection, aux heat lockout by outdoor temp, fail-safe if the firmware locks up
- [ ] Uses the system's own data for smarter control (defrost awareness, lockouts when a fault is detected)
- [ ] Thermostat safety certification (UL 60730) on top of FCC
- [ ] Buy the Waveshare ESP32-S3 4.3" touch board (\~$40), check its pin numbers against the schematic, and run the firmware on it
- [x] Thermostat merged into main (Oct 4), so the demo runs without switching branches; it stays unused until thermostat hardware exists

### Electrical monitoring module

- [ ] Amps, contactor voltage drop and capacitor under load (kept separate so the core product stays low-voltage)
- [x] Software side built (merged into main Oct 4): 10 diagnostic rules (compressor or fan not running, contactor not closing, amps vs RLA/FLA, run capacitor ±6 %, contactor drop, line voltage, slow starts), nameplate fields on the Equipment page, technician and homeowner views, a simulator with each fault; design in electrical/README.md
- [ ] Version 1 hardware, clamp-on current sensors only (no line contact, covers 5 of the 10 rules): prototype with the outdoor ESP32, then choose an add-on board or the outdoor carrier rev B
- [ ] Version 2: isolated voltage board for the capacitor test, contactor drop and line voltage, then a test-lab review for UL/IEC 61010
- [x] Electrical module merged into main with the thermostat (Oct 4); it stays unused until a module is installed

## Phase 12: Launch

- [ ] FCC Part 15 testing; UL/ETL for the electrical module
- [ ] Multi-contractor accounts and subscription billing
- [ ] Push notifications
- [ ] Install guides and support docs
- [ ] Volume sourcing direct from manufacturers
- [ ] Final pricing: hardware plus subscription

## Parallel tracks (start now)

### Customer discovery

Their answers shape Phases 5, 8 and 10.

- [x] Demo and interview kit ready: start-demo.bat (seven scripted homes with common faults) and the [Contractor Interview Kit](https://claude.ai/code/artifact/73343a90-f40b-4778-9df8-f79033e4813c) (21 questions, demo script, notes sheet)
- [x] Thermostat in the demo: a seventh home, Rivera, with a thermostat and electrical module whose run capacitor is weakening, shown on the thermostat's Alerts and Service screens; Garcia's homeowner view has a thermostat too. The interview kit's demo script has a Rivera step, shown after question 16
- [x] Project files organized (Oct 4): a project-files folder in the repo with this roadmap and the interview kit, the parts list, 43 screenshots by topic and the logo; a README on the GitHub repo's front page; HVAC Monitor Start and Fullscope Thermostat shortcuts on the Desktop (the thermostat screen now signs in and comes straight back)
- [ ] List 5–10 HVAC contractors to talk to
- [ ] Ask which alerts would save them truck rolls
- [ ] Ask what they would pay per system per month
- [ ] Ask who should get alerts: owner, dispatcher, technician or homeowner

### IP protection

- [ ] Book a consultation with a patent attorney
- [ ] File a provisional application before showing the system publicly or starting the pilot
- [ ] Keep dated notes and design files as you go

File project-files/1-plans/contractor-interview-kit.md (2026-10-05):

# Contractor Interview Kit

Oct 3, 2026 · Tyler · exported Oct 4, 2026 from the
[live doc](https://claude.ai/code/artifact/73343a90-f40b-4778-9df8-f79033e4813c) (the doc is the
current version; edit it there)

Talk to 5–10 HVAC contractors this fall: show them the Fullscope demo for 10 minutes, then ask the questions below. Their answers decide the radio, who gets alerts, the price and which add-on comes next.

## Who to talk to

Aim for residential service companies with 3–30 technicians that sell maintenance agreements: they feel truck rolls and callbacks most, and are the likely first buyers. Mix in one or two owner-operators and one larger shop to see the range.

- **Best first calls:** people you already know from the trade, supply-house counter regulars, your own former employers or crews.
- **Where else:** local ACCA chapter or supply-house training nights, Facebook/Reddit HVAC business groups, manufacturer dealer meetings.
- **Ask for:** 30 minutes, "I'm building a monitoring tool for residential systems and want a contractor's honest opinion before I go further." Offer coffee or lunch.
- **Talk to the owner or service manager**, not only a technician: they decide what gets bought and what a monthly fee is worth.
- **Before showing anything publicly**, the roadmap's IP track says to see a patent attorney first. Keep these conversations one-to-one; consider a simple NDA for anyone you don't know.

## Before the call

The demo runs on your PC with your normal cloud; it is a separate demo account and sends no email.

1. Start the **HVAC Monitor** shortcut (broker, dashboard, cloud).
2. Double-click `hvac-cloud\start-demo.bat`. The first time it builds the demo (about a minute), then it keeps the seven homes live in a window titled "HVAC demo – leave this open" and shows the two demo sign-ins.
3. If the demo was set up before the Rivera home existed (before Oct 4), close the demo window, run `python demo.py reset` in `hvac-cloud`, rerun the **HVAC Monitor** shortcut so the cloud has the thermostat code, and start `start-demo.bat` again.
4. In the browser, sign in as the **demo contractor** (`demo@fullscope.example`). Open a second browser window (or a private window) signed in as the **Garcia homeowner** (`garcia@fullscope.example`). The passwords are in `hvac-cloud\demo-login.txt`.
5. Have this doc open on a tablet or printed, with the notes sheet at the end.
6. Showing it in person: laptop on the table. Over video: share only the browser window.

To start over with a fresh demo: run `python demo.py reset` in `hvac-cloud`, then `start-demo.bat` again.

## The 10-minute demo

Show, then stop talking: the point is their reaction, not the pitch. Ask questions 1–5 first so their answers aren't shaped by what you show.

1. **Fleet page (1 min).** Seven customer systems, worst first. "Which of these would you send a truck to today?" Watch what they look at.
2. **Brooks home (2 min).** Superheat near zero, liquid floodback risk, marked *Service needed*. Show the live trend, the refrigerant table, and the alert log (when it started, Acknowledge).
3. **Patel home (1 min).** High superheat and subcooling below the nameplate target: a slow leak caught before the customer calls. Point at the Equipment page's TXV target.
4. **Miller rental (1 min).** Condensing 36°F+ over ambient: dirty coil. "Would you sell a coil cleaning off this?"
5. **Thompson residence (1 min).** Low delta-T and a filter 118 days old: something the homeowner can fix themselves.
6. **Garcia homeowner view (2 min).** Switch to the homeowner window: plain words, five health areas, maintenance with "I changed it", *Request service*, recent service visits.
7. **Rivera home: thermostat and electrical (2 min, after question 16).** Say first that these are designed and working in software, with no hardware yet. On the thermostat card, open *See the thermostat's screen*: the Alerts tab shows "A part in your outdoor unit is wearing out" in plain words. Then Service (PIN 0000): the pressure and air trend with the weak-capacitor marker where it started. Back in the technician view, Operating state shows the capacitor at 38 of 45 µF. "Would you replace that capacitor before it fails? Would your customers want this on their wall?"
8. **Nguyen casita (30 s).** An indoor monitor offline: how a dropped sensor looks without crying wolf.
9. **Sensors & calibration and Service history (1 min).** Zero and span from the browser; a visit logged with the readings attached.

Don't demo what doesn't exist yet (the radio): ask about it in the questions instead. The thermostat and electrical module work in software but have no hardware yet: show Rivera only after asking question 16, so their first answer isn't shaped by the demo.

## Questions

Ask about what they do today, not what they'd buy: "tell me about the last time…" beats "would you use…". Write down numbers and their exact words.

### Before the demo: their business today

1. How many techs, how many service calls a week in summer, and how many maintenance agreements do you carry?
2. Tell me about the last callback or emergency call that could have been caught earlier. What did it cost you?
3. What share of no-cool calls turn out to be a capacitor, contactor, dirty filter or coil, or low charge?
4. Do you use any monitoring or smart-thermostat alerts today? What do you like and hate about them?
5. How do you find out a customer's system has a problem: they call, you find it on a PM, something else?

### After the demo: value

6. Which of those six homes would you act on first, and what would you do?
7. Which alerts would save you a truck roll or win you a job? Which would you ignore?
8. What's missing that would make you install this on a customer's system tomorrow?

### Alerts

9. Who should get each kind of alert: owner, dispatcher, the tech on the account, the homeowner? Email, text, an app?
10. How many alerts a week per 100 customers is too many?
11. Should the homeowner see problems at all, or only the contractor first?

### Installing it

12. How long can an install take before it isn't worth it on a PM visit: 15 minutes, 30, an hour?
13. Who would install it: a senior tech, anyone on a PM, the installer at changeout?
14. Homeowner WiFi at the condenser and in the attic: how often is it a problem? Would a plug-in gateway that talks to the units by radio be worth $20–30 more?

### Add-ons

15. Electrical monitoring (compressor and fan amps, capacitor health, contactor wear) without opening the panel: how much would that be worth on top?
16. A thermostat that's part of the system (scheduling plus the diagnostics): would you rather sell that, or keep the customer's own thermostat?

### Price and business model

17. What would you pay per system per month, and would you pass it to the homeowner, bundle it into a maintenance agreement, or absorb it?
18. Hardware: what's acceptable up front per system, and should it be yours or the homeowner's?
19. Would this help you sell more maintenance agreements? How many more, roughly?

### Wrap-up

20. Would you put it on 3–5 of your customers' systems as a pilot this cooling season, at no cost, in exchange for feedback?
21. Who else should I talk to?

## What the answers decide

Each open roadmap decision, the questions that settle it, and the answer that would tip it. After 5 interviews, tally the notes sheet against this table.

| Decision | Questions | Tips toward |
|---|---|---|
| Radio: LoRa + gateway, WiFi only, or cellular | 12, 13, 14 | WiFi trouble at the unit is common and installs must be fast → LoRa + gateway; rarely a problem → stay WiFi; no-WiFi homes matter and a monthly fee is fine → cellular |
| Who gets which alert, and how | 9, 10, 11 | Today: homeowners get plain email, the contractor the technical one. Wanting texts, a dispatcher queue or contractor-first → change the routing before the pilot |
| Price per system per month, and who pays | 17, 18, 19 | Sets the subscription and whether hardware is sold or bundled; if most bundle it into agreements, price per agreement, not per homeowner |
| Electrical module: when | 3, 15 | Capacitors and contactors are a big share of no-cool calls and they'd pay extra → version 1 (current sensors only) goes on carrier rev B |
| Display thermostat: build or not | 16 | Most prefer to keep the customer's thermostat → park it; some want to sell one → design it after the pilot |
| What "done" means for the pilot | 6, 7, 8 | The most-asked missing feature becomes the last item before the pilot |
| Pilot partners | 20, 21 | Two or three yeses → schedule installs for the next cooling season |
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

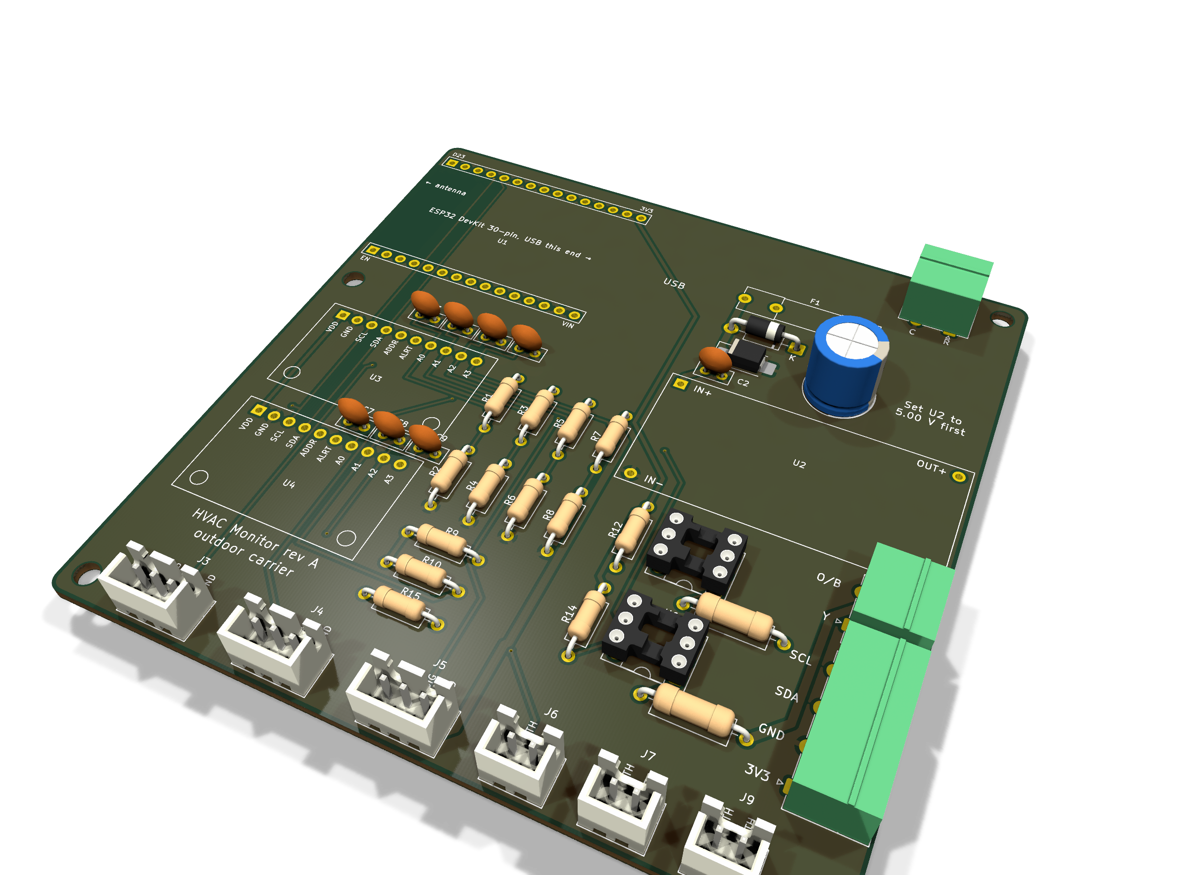
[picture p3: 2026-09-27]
hardware/outdoor-carrier/fab/renders/outdoor-carrier-iso.png

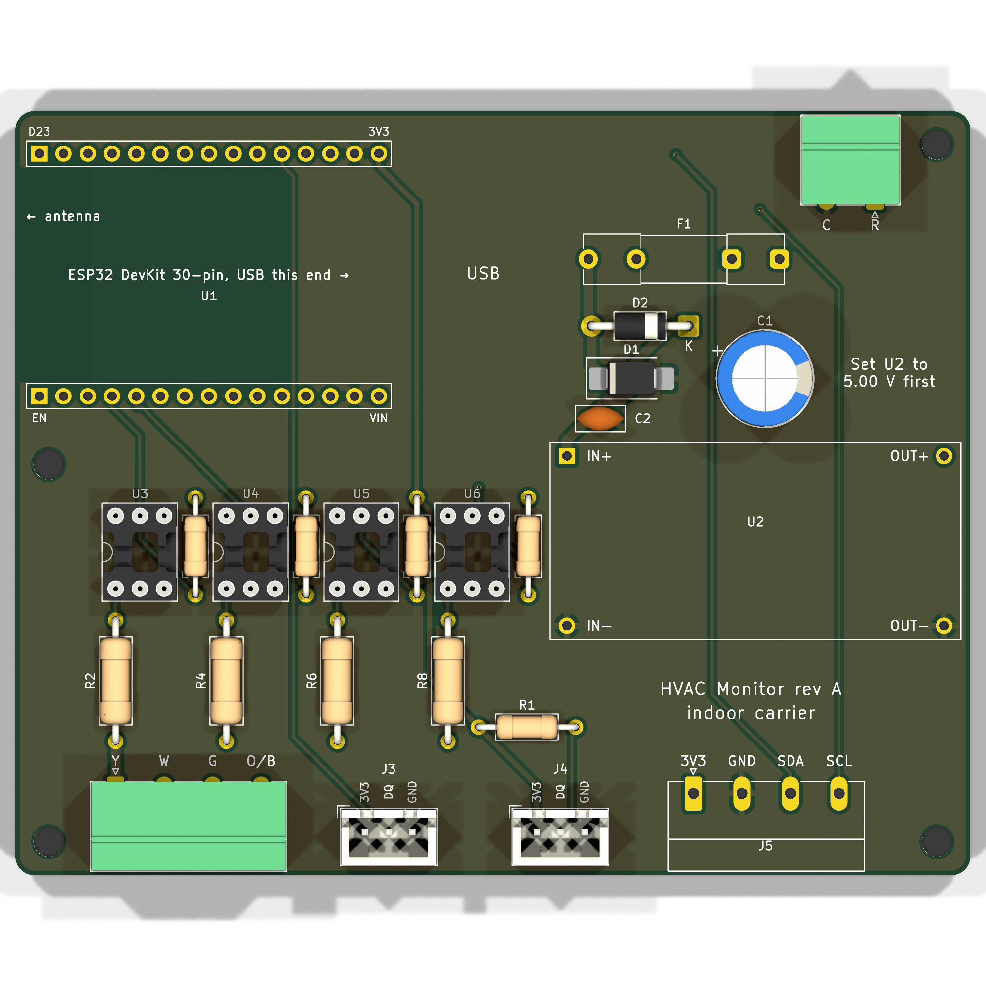
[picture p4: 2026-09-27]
hardware/indoor-carrier/fab/renders/indoor-carrier-top.png

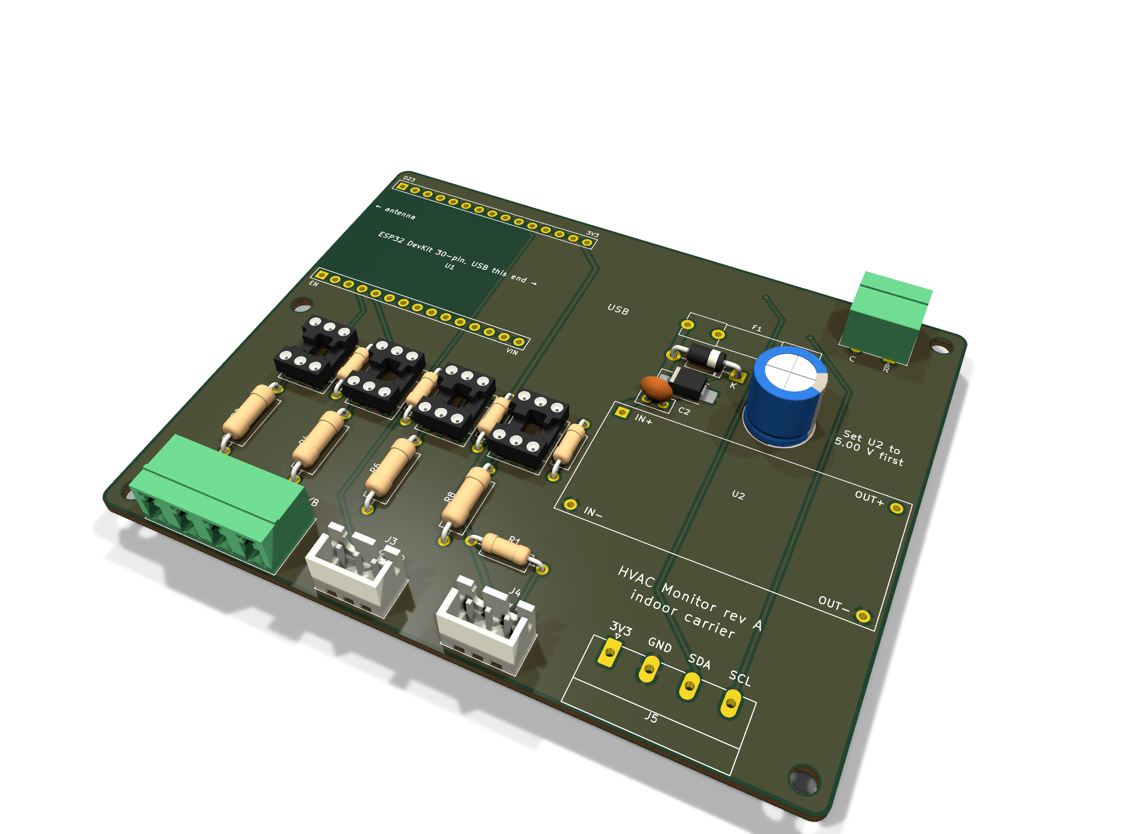
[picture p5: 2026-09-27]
hardware/indoor-carrier/fab/renders/indoor-carrier-iso.png

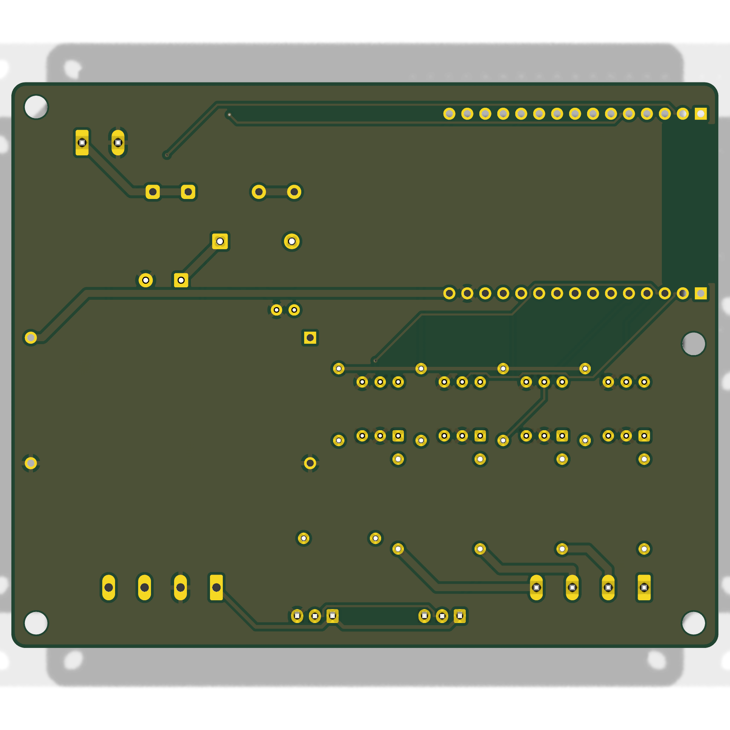
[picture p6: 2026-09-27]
hardware/indoor-carrier/fab/renders/indoor-carrier-bottom.png

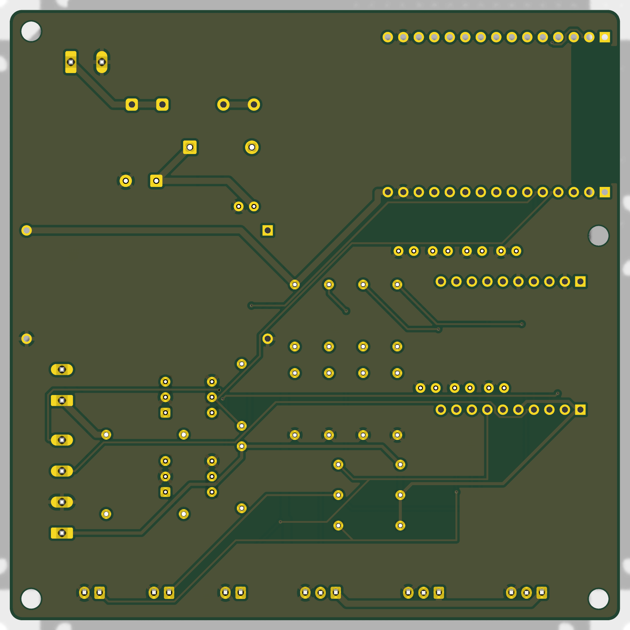
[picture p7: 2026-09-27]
hardware/outdoor-carrier/fab/renders/outdoor-carrier-bottom.png

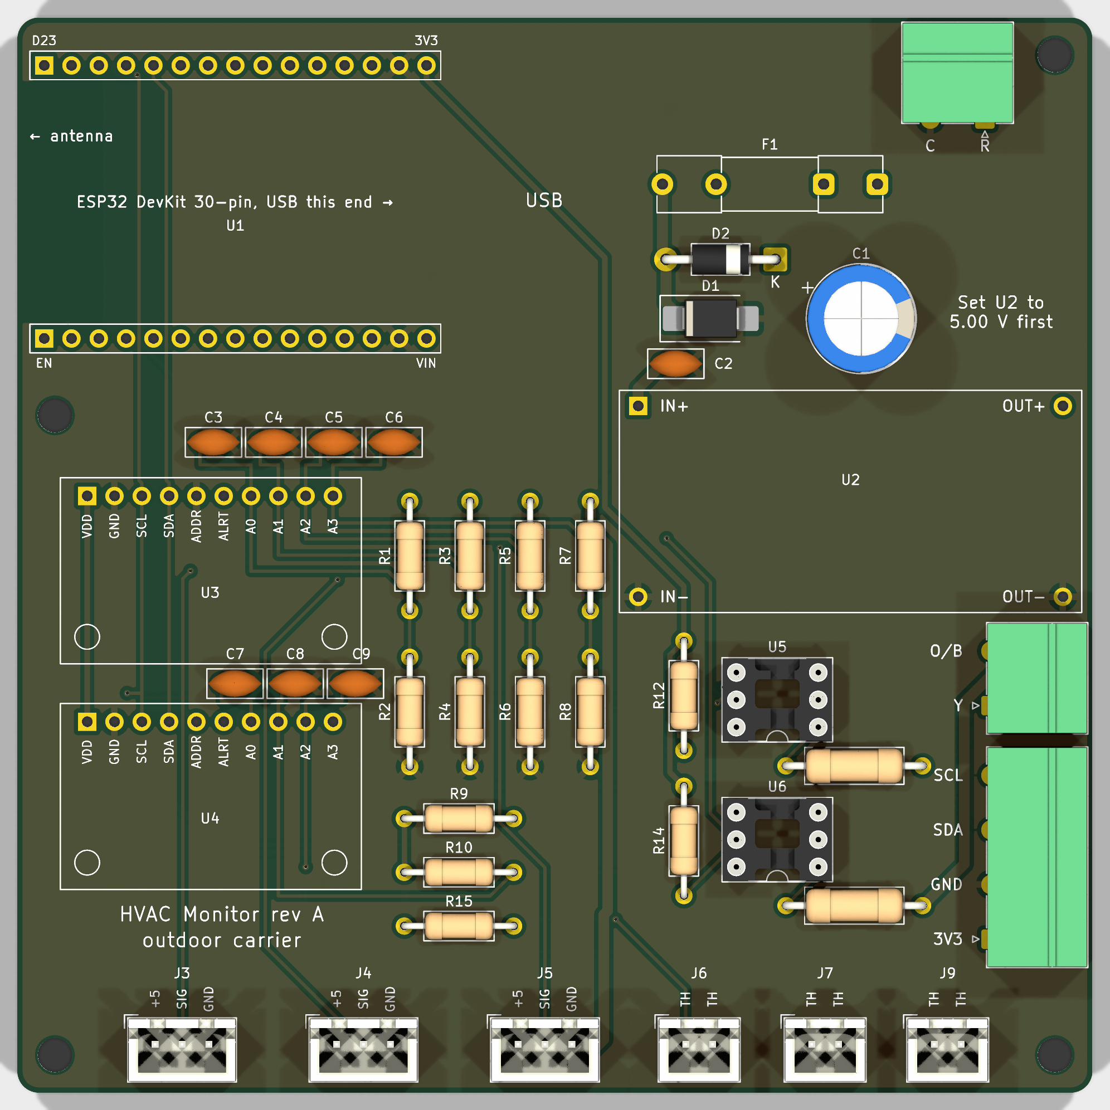
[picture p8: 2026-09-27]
hardware/outdoor-carrier/fab/renders/outdoor-carrier-top.png

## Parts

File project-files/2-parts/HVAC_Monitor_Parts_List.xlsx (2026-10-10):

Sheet: Summary
HVAC Monitoring System — Cost Summary
Totals pull from each node sheet by phase. Edit quantities/costs (blue) on node sheets.
Node | V1 (core) | Optional | Phase 2 | Future | LoRa | All Items
Outdoor Node
Indoor Node
Display Node
LoRa Radio
Infrastructure
Total
Notes
• Power supply kit cost is included in each node's total (3 kits); the Power Kit sheet is not added separately.
• XDB307-3 price ($73.67) is from the Amazon listing you found; other prices are estimates — verify before ordering.
• Production BOM will be far lower: buy transducers direct from the manufacturer at volume and move to a custom PCB.
• Phase legend: V1 = proof of concept · Optional = recommended extras · Phase 2 = electrical monitoring · Future = thermostat replacement · LoRa = 900 MHz radio (range test, node radios, gateway).
• LoRa and the thermostat module follow radio/README.md and thermostat/README.md; both are designs not yet built, so treat prices as estimates.

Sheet: Power Kit
Power Kit — Parts List
Blue = editable estimate. Prices are approximate single-unit retail (Sept 2026); links are supplier search pages.
Build 3 kits — one each for outdoor, indoor and display nodes. Kit cost flows into each node sheet.
Item | Part / Spec | Qty | Est. Unit Cost ($) | Line Total ($) | Phase | Supplier | Link | Notes
Power supply kit parts
Inline fuse holder | 5x20mm or ATO, 18 AWG leads | 1 | $3.00 |  | V1 | DigiKey | Search (https://www.digikey.com/en/products/result?keywords=inline+fuse+holder+5x20mm) | Install on R
Fuse | 0.5 A fast-blow | 1 | $1.00 |  | V1 | DigiKey | Search (https://www.digikey.com/en/products/result?keywords=0.5A+fast+blow+fuse+5x20)
TVS diode | SMBJ48CA bidirectional | 1 | $0.50 |  | V1 | DigiKey | Search (https://www.digikey.com/en/products/result?keywords=SMBJ48CA) | Across 24 VAC input; clamps contactor coil spikes
Rectifier diode | 1N4007 | 1 | $0.10 |  | V1 | DigiKey | Search (https://www.digikey.com/en/products/result?keywords=1N4007) | Half-wave: keeps C as DC ground
Bulk capacitor | 470 µF 63 V electrolytic | 1 | $0.60 |  | V1 | DigiKey | Search (https://www.digikey.com/en/products/result?keywords=470uF+63V+electrolytic)
Bypass capacitor | 0.1 µF 100 V ceramic | 1 | $0.10 |  | V1 | DigiKey | Search (https://www.digikey.com/en/products/result?keywords=0.1uF+100V+ceramic+capacitor)
Buck converter module | LM2596HV (60 V input), set to 5.0 V | 1 | $4.00 |  | V1 | Amazon | Search (https://www.amazon.com/s?k=LM2596HV+buck+converter+module) | Must be HV version; 24 VAC rectifies to ~40 V peak
Terminal block | 2-pos pluggable 5.08 mm | 1 | $1.00 |  | V1 | DigiKey | Search (https://www.digikey.com/en/products/result?keywords=2+position+pluggable+terminal+block+5.08mm) | R, C input
 |  |  | Total

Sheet: Outdoor Node
Outdoor Node — Parts List
Blue = editable estimate. Prices are approximate single-unit retail (Sept 2026); links are supplier search pages.
Item | Part / Spec | Qty | Est. Unit Cost ($) | Line Total ($) | Phase | Supplier | Link | Notes
Controller & interface
ESP32 dev board | ESP32-WROOM-32U (external antenna) | 1 | $10.00 |  | V1 | Amazon | Search (https://www.amazon.com/s?k=ESP32-WROOM-32U+dev+board) | Metal cabinet blocks WiFi
Antenna + pigtail | 2.4 GHz antenna, u.FL to RP-SMA bulkhead | 1 | $8.00 |  | V1 | Amazon | Search (https://www.amazon.com/s?k=2.4GHz+antenna+u.FL+RP-SMA+pigtail) | Mount antenna outside cabinet
Power supply kit | See 'Power Kit' sheet | 1 |  |  | V1 | Built in-house |  | Cost links to Power Kit sheet
ADC module | ADS1115 16-bit, 4-ch | 2 | $6.00 |  | V1 | Amazon | Search (https://www.amazon.com/s?k=ADS1115+module) | Addresses 0x48 / 0x49; run at 3.3 V
AC-input optocoupler | H11AA1 | 3 | $0.80 |  | V1 | DigiKey | Search (https://www.digikey.com/en/products/result?keywords=H11AA1) | Y, O/B, spare
Opto series resistor | 4.7k ½ W | 3 | $0.10 |  | V1 | DigiKey | Search (https://www.digikey.com/en/products/result?keywords=4.7k+1%2F2W+resistor) | One per opto input
Opto pull-up resistor | 10k ¼ W | 3 | $0.05 |  | V1 | DigiKey | Search (https://www.digikey.com/en/products/result?keywords=10k+1%2F4W+resistor) | One per opto output
Refrigerant sensors
Pressure transducer (high/vapor) | XDB307-3, 0.5–4.5 V, 5–12 V, 0–50 bar, 7/16-20 UNF | 2 | $73.67 |  | V1 | Amazon | Search (https://www.amazon.com/s?k=XDB307-3+0.5-4.5V+7%2F16-20UNF+0-50bar) | Liquid line + vapor line port. Price from Amazon listing (LDGSUPH). Confirm depressor with seller
Pressure transducer (true suction) | XDB307-3, 0.5–4.5 V, 0–35 bar | 1 | $73.67 |  | V1 | Amazon | Search (https://www.amazon.com/s?k=XDB307-3+0.5-4.5V+7%2F16-20UNF+0-35bar) | Never sees discharge pressure
Pipe thermistor | 10k NTC strap-on | 2 | $12.00 |  | V1 | Amazon | Search (https://www.amazon.com/s?k=10k+NTC+strap+on+pipe+temperature+sensor+HVAC) | Suction line + liquid line
Pipe thermistor (true suction) | 10k NTC strap-on | 1 | $12.00 |  | Optional | Amazon | Search (https://www.amazon.com/s?k=10k+NTC+strap+on+pipe+temperature+sensor+HVAC) | Heating-mode superheat
Discharge line thermistor | High-temp 10k NTC, 150 °C+ | 1 | $15.00 |  | Optional | Amazon | Search (https://www.amazon.com/s?k=high+temperature+10k+NTC+pipe+sensor+150C) | Compressor health indicator
Signal conditioning
Divider resistor (top) | 10k 1% metal film | 3 | $0.05 |  | V1 | DigiKey | Search (https://www.digikey.com/en/products/result?keywords=10k+1%25+metal+film+resistor) | Sensor dividers: 4.5 V -> 3.0 V
Divider resistor (bottom) | 20k 1% metal film | 3 | $0.05 |  | V1 | DigiKey | Search (https://www.digikey.com/en/products/result?keywords=20k+1%25+metal+film+resistor) | R2, R4, R6. 10k also works: set P_DIV_BOTTOM_K 10.0 in config.h
Rail monitor divider | 10k + 15k 1% (pair) | 1 | $0.10 |  | V1 | DigiKey | Search (https://www.digikey.com/en/products/result?keywords=15k+1%25+metal+film+resistor) | R7 (10k) / R8 (15k): measures the 5 V rail for ratiometric correction. R8 may be 10k (RAIL_DIV_BOTTOM_K 10.0); 15k is the most it can be
Thermistor reference resistor | 10k 0.1% | 4 | $0.50 |  | V1 | DigiKey | Search (https://www.digikey.com/en/products/result?keywords=10k+0.1%25+resistor) | 2 used in V1, 2 for optional thermistors
ADC filter capacitor | 0.1 µF ceramic | 7 | $0.10 |  | V1 | DigiKey | Search (https://www.digikey.com/en/products/result?keywords=0.1uF+50V+ceramic+capacitor) | One per ADC input
Outdoor air
Temp/humidity sensor | SHT45 with PTFE membrane | 1 | $15.00 |  | V1 | Amazon | Search (https://www.amazon.com/s?k=SHT45+PTFE+membrane+sensor) | I²C 0x44
Radiation shield | Solar radiation shield | 1 | $25.00 |  | V1 | Amazon | Search (https://www.amazon.com/s?k=solar+radiation+shield+temperature+sensor) | Keeps sun off the SHT45
Refrigerant hardware
Access valve | Braze-on 1/4" SAE access valve, sized to line | 1 | $6.00 |  | V1 | HVAC supply house | Search (https://www.google.com/search?q=braze+on+access+valve+1%2F4+SAE) | True suction port; requires brazing + EPA 608
Flare gaskets | 1/4" flare copper gaskets / seals | 1 | $8.00 |  | V1 | Amazon | Search (https://www.amazon.com/s?k=1%2F4+flare+copper+gasket+HVAC) | Pack
Flare hose | Short 1/4" flare hose, F x M | 3 | $12.00 |  | Optional | Amazon | Search (https://www.amazon.com/s?k=1%2F4+flare+hose+12+inch+HVAC) | Isolates sensors from vibration
Schrader cores & caps | Spare kit | 1 | $10.00 |  | V1 | Amazon | Search (https://www.amazon.com/s?k=schrader+valve+core+cap+kit+HVAC)
Enclosure & wiring
Enclosure | IP65 ABS, ~200×150×75 mm | 1 | $25.00 |  | V1 | Amazon | Search (https://www.amazon.com/s?k=IP65+ABS+enclosure+200x150x75) | Mount outside compressor compartment
Cable glands | PG7 / PG9 assortment | 1 | $10.00 |  | V1 | Amazon | Search (https://www.amazon.com/s?k=PG7+PG9+cable+gland+assortment)
Prototype board | Perfboard / proto PCB | 1 | $8.00 |  | V1 | Amazon | Search (https://www.amazon.com/s?k=prototype+PCB+perfboard)
Terminal blocks | Pluggable 5.08 mm assortment | 1 | $12.00 |  | V1 | Amazon | Search (https://www.amazon.com/s?k=pluggable+terminal+block+5.08mm+assortment)
Sensor cable | 22 AWG shielded 3-cond, 50 ft | 1 | $25.00 |  | V1 | Amazon | Search (https://www.amazon.com/s?k=22+AWG+shielded+3+conductor+cable+50ft)
Thermostat wire | 18/5, 50 ft | 1 | $30.00 |  | V1 | Amazon | Search (https://www.amazon.com/s?k=18%2F5+thermostat+wire+50ft)
Insulation tape | Foam pipe insulation tape | 1 | $10.00 |  | V1 | Amazon | Search (https://www.amazon.com/s?k=foam+pipe+insulation+tape) | Over thermistors
Zip ties | UV-rated / stainless | 1 | $8.00 |  | V1 | Amazon | Search (https://www.amazon.com/s?k=UV+resistant+zip+ties)
Phase 2 electrical
Energy monitor board | ATM90E32-based (e.g. CircuitSetup) | 1 | $80.00 |  | Phase 2 | CircuitSetup | Search (https://www.google.com/search?q=CircuitSetup+ATM90E32+energy+meter) | True RMS current + voltage
Current transformer | Split-core CT | 3 | $12.00 |  | Phase 2 | Amazon | Search (https://www.amazon.com/s?k=split+core+current+transformer+SCT-013) | Compressor common, start winding, condenser fan
Isolated amplifier | AMC1311 or similar (board) | 2 | $15.00 |  | Phase 2 | DigiKey | Search (https://www.digikey.com/en/products/result?keywords=AMC1311) | Contactor drop + capacitor voltage
HV divider resistors | High-voltage rated resistor set | 1 | $5.00 |  | Phase 2 | DigiKey | Search (https://www.digikey.com/en/products/result?keywords=high+voltage+resistor+1W)
Voltage reference transformer | 9–12 VAC | 1 | $12.00 |  | Phase 2 | Amazon | Search (https://www.amazon.com/s?k=9VAC+wall+transformer) | For energy monitor
Fused test leads / taps | 600 V rated, 1/4" spade | 1 | $20.00 |  | Phase 2 | Amazon | Search (https://www.amazon.com/s?k=fused+test+leads+600V+spade)
HV barrier | Separate compartment / insulating barrier | 1 | $10.00 |  | Phase 2 | Fabricate |  | Isolate line voltage from low voltage
 |  |  | Total

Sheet: Indoor Node
Indoor Node — Parts List
Blue = editable estimate. Prices are approximate single-unit retail (Sept 2026); links are supplier search pages.
Item | Part / Spec | Qty | Est. Unit Cost ($) | Line Total ($) | Phase | Supplier | Link | Notes
Controller & interface
ESP32 dev board | ESP32-WROOM-32U (external antenna) | 1 | $10.00 |  | V1 | Amazon | Search (https://www.amazon.com/s?k=ESP32-WROOM-32U+dev+board) | Furnace cabinet blocks WiFi
Antenna + pigtail | 2.4 GHz antenna, u.FL to RP-SMA | 1 | $8.00 |  | V1 | Amazon | Search (https://www.amazon.com/s?k=2.4GHz+antenna+u.FL+RP-SMA+pigtail)
Power supply kit | See 'Power Kit' sheet | 1 |  |  | V1 | Built in-house |  | Cost links to Power Kit sheet
I²C multiplexer | TCA9548A | 1 | $6.00 |  | V1 | Amazon | Search (https://www.amazon.com/s?k=TCA9548A+I2C+multiplexer) | SDP810s share one address
AC-input optocoupler | H11AA1 | 4 | $0.80 |  | V1 | DigiKey | Search (https://www.digikey.com/en/products/result?keywords=H11AA1) | Y, W, G, O/B
Opto series resistor | 4.7k ½ W | 4 | $0.10 |  | V1 | DigiKey | Search (https://www.digikey.com/en/products/result?keywords=4.7k+1%2F2W+resistor) | One per opto input
Opto pull-up resistor | 10k ¼ W | 4 | $0.05 |  | V1 | DigiKey | Search (https://www.digikey.com/en/products/result?keywords=10k+1%2F4W+resistor) | One per opto output
I²C extender | PCA9615 differential I²C | 2 | $12.00 |  | Optional | Amazon | Search (https://www.amazon.com/s?k=PCA9615+differential+I2C) | For runs over ~1 m
Air sensors
Duct temp/humidity probe | SHT45 probe with PTFE membrane | 2 | $25.00 |  | V1 | Amazon | Search (https://www.amazon.com/s?k=SHT45+probe+PTFE+waterproof) | Supply + return
Differential pressure sensor | Sensirion SDP810-500Pa | 3 | $45.00 |  | V1 | DigiKey | Search (https://www.digikey.com/en/products/result?keywords=SDP810-500Pa) | Return, furnace-to-coil, supply
Static pressure tip | Dwyer A-301 style | 3 | $15.00 |  | V1 | HVAC supply house | Search (https://www.google.com/search?q=Dwyer+A-301+static+pressure+tip)
Grommets | Rubber grommets for tips | 1 | $5.00 |  | V1 | Amazon | Search (https://www.amazon.com/s?k=rubber+grommet+assortment)
Silicone tubing | 3/16" ID, ~10 ft | 1 | $10.00 |  | V1 | Amazon | Search (https://www.amazon.com/s?k=3%2F16+ID+silicone+tubing+10ft)
Filter pressure sensor | SDP810-500Pa | 1 | $45.00 |  | Optional | DigiKey | Search (https://www.digikey.com/en/products/result?keywords=SDP810-500Pa) | Filter pressure drop
Filter static tip | Dwyer A-301 style | 1 | $15.00 |  | Optional | HVAC supply house | Search (https://www.google.com/search?q=Dwyer+A-301+static+pressure+tip)
Enclosure & wiring
Enclosure | ABS project box | 1 | $15.00 |  | V1 | Amazon | Search (https://www.amazon.com/s?k=ABS+project+box+enclosure)
I²C cable | 22 AWG shielded 4-cond, 50 ft | 1 | $25.00 |  | V1 | Amazon | Search (https://www.amazon.com/s?k=22+AWG+shielded+4+conductor+cable+50ft)
Thermostat wire | 18/5, 50 ft | 1 | $30.00 |  | V1 | Amazon | Search (https://www.amazon.com/s?k=18%2F5+thermostat+wire+50ft)
Glands, terminals, perfboard | Assortment | 1 | $20.00 |  | V1 | Amazon | Search (https://www.amazon.com/s?k=cable+gland+terminal+block+perfboard+kit)
Phase 2 electrical
Energy monitor board | ATM90E32-based | 1 | $80.00 |  | Phase 2 | CircuitSetup | Search (https://www.google.com/search?q=CircuitSetup+ATM90E32+energy+meter)
Current transformer | Split-core CT | 2 | $12.00 |  | Phase 2 | Amazon | Search (https://www.amazon.com/s?k=split+core+current+transformer+SCT-013) | Blower + inducer (inducer optional)
Isolated amplifier | AMC1311 or similar | 1 | $15.00 |  | Phase 2 | DigiKey | Search (https://www.digikey.com/en/products/result?keywords=AMC1311) | PSC blower capacitor voltage
Voltage reference transformer | Matched to 120 or 240 V equipment | 1 | $12.00 |  | Phase 2 | Amazon | Search (https://www.amazon.com/s?k=9VAC+wall+transformer)
 |  |  | Total

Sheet: Display Node
Display Node — Parts List
Blue = editable estimate. Prices are approximate single-unit retail (Sept 2026); links are supplier search pages.
Item | Part / Spec | Qty | Est. Unit Cost ($) | Line Total ($) | Phase | Supplier | Link | Notes
Display & power
Touch display board | Waveshare ESP32-S3 4.3" Touch LCD | 1 | $40.00 |  | V1 | Amazon | Search (https://www.amazon.com/s?k=Waveshare+ESP32-S3+4.3+touch+LCD) | 800 × 480 touchscreen; also the system hub and (with LoRa) the gateway
Power supply kit | See 'Power Kit' sheet | 1 |  |  | V1 | Built in-house |  | Needs C wire at thermostat
C-wire adapter | Venstar Add-a-Wire | 1 | $30.00 |  | Optional | Amazon | Search (https://www.amazon.com/s?k=Venstar+Add-a-Wire) | Only if no C wire
Wall mount | Enclosure or 3D-printed bezel | 1 | $15.00 |  | V1 | 3D print / Amazon
Room temp/humidity | SHT45 | 1 | $15.00 |  | Optional | Amazon | Search (https://www.amazon.com/s?k=SHT45+sensor+breakout) | For the display-only version. The thermostat version uses the one in its section below
Alarm buzzer | Piezo buzzer | 1 | $1.00 |  | Optional | Amazon | Search (https://www.amazon.com/s?k=piezo+buzzer+3.3V)
Thermostat-replacement version (see thermostat/README.md)
Output switches | PhotoMOS solid-state relay, 60 V AC/DC, 2.5 A (Panasonic AQV252G) | 6 | $5.00 |  | Future | DigiKey | Search (https://www.digikey.com/en/products/result?keywords=AQV252G) | Y, Y2, W, W2, G, O/B. Open on reset/power loss; silent, no contact wear
Output surge clamp | TVS diode SMBJ36CA bidirectional | 6 | $0.50 |  | Future | DigiKey | Search (https://www.digikey.com/en/products/result?keywords=SMBJ36CA) | Across each output: clamps contactor/valve coil kick below the 60 V switch rating
SSR LED resistor | 330 Ω ¼ W | 6 | $0.05 |  | Future | DigiKey | Search (https://www.digikey.com/en/products/result?keywords=330+ohm+resistor+1%2F4W) | ~5 mA from 3.3 V into each PhotoMOS LED
I/O expander | MCP23017 I²C 16-bit GPIO expander | 1 | $2.00 |  | Future | DigiKey | Search (https://www.digikey.com/en/products/result?keywords=MCP23017) | 6 outputs + watchdog line + 5 state-sense inputs over I²C (the 4.3" board's GPIOs go to the LCD). Resets to all-off
Hardware watchdog | TI TPS3823-33 supervisor with watchdog | 1 | $1.50 |  | Future | DigiKey | Search (https://www.digikey.com/en/products/result?keywords=TPS3823-33) | Its RESET drives the ESP32 EN and the MCP23017 RESET: if the firmware stops, every output turns off
State-sense optos | H11AA1 | 5 | $0.80 |  | Future | DigiKey | Search (https://www.digikey.com/en/products/result?keywords=H11AA1) | Read back what the equipment actually gets (Y, Y2, W, G, O/B)
Opto series resistor | 4.7k ½ W | 5 | $0.10 |  | Future | DigiKey | Search (https://www.digikey.com/en/products/result?keywords=4.7k+ohm+1%2F2W+resistor) | One per state-sense input
Opto pull-up resistor | 10k ¼ W | 5 | $0.05 |  | Future | DigiKey | Search (https://www.digikey.com/en/products/result?keywords=10k+ohm+resistor) | One per opto output
Room temp/humidity (control) | SHT45 on a thermally isolated tab / short flex cable | 1 | $15.00 |  | Future | Amazon | Search (https://www.amazon.com/s?k=SHT45+breakout) | Controls the house: keep it away from the display and regulator heat
Wiring terminal block | 8-pos pluggable 5.08 mm (R, C, Y, Y2, W, W2, G, O/B) | 1 | $3.00 |  | Future | DigiKey | Search (https://www.digikey.com/en/products/result?keywords=8+position+pluggable+terminal+block+5.08mm) | Labelled like a standard thermostat sub-base
Output carrier PCB | Small 2-layer board for the switches, optos and terminals (JLCPCB, 5 pcs) | 1 | $20.00 |  | Future | JLCPCB | Search (https://jlcpcb.com/) | Mounts behind the display board; I²C + 5 V from the power kit
Connectors & jumpers | JST-SH / Dupont jumper set | 1 | $6.00 |  | Future | Amazon | Search (https://www.amazon.com/s?k=JST+SH+1.0mm+jumper+cable+kit) | Display board to output carrier
Wall back plate | 3D-printed back plate with wire opening + screws/anchors | 1 | $8.00 |  | Future | 3D print / Amazon |  | Replaces the old thermostat's sub-base
 |  |  | Total

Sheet: LoRa Radio
LoRa Radio (900 MHz) — Parts List
Blue = editable estimate. Prices are approximate single-unit retail (Oct 2026); links are supplier search pages.
From radio/README.md (branch radio/lora-design): one fixed 500 kHz channel in 902–928 MHz, SX1262 radios, gateway built into the thermostat or a plug-in unit.
Item | Part / Spec | Qty | Est. Unit Cost ($) | Line Total ($) | Phase | Supplier | Link | Notes
Range test (do first: decides LoRa vs WiFi)
LoRa dev board | Heltec WiFi LoRa 32 V3, 915 MHz version (ESP32-S3 + SX1262, OLED) | 2 | $22.00 |  | LoRa | Heltec | Search (https://heltec.org/?s=WiFi+LoRa+32+V3) | Sender + receiver for the range test (radio/rangetest firmware)
Antenna | 915 MHz 3 dBi, SMA, with u.FL-to-SMA pigtail | 2 | $8.00 |  | LoRa | Amazon | Search (https://www.amazon.com/s?k=915MHz+antenna+SMA+u.FL+pigtail) | Must be 915 MHz, not 868
USB power bank | Any, USB-C | 1 | $20.00 |  | Optional | Amazon | Search (https://www.amazon.com/s?k=USB+C+power+bank) | Powers the sender on the walk-around. Skip if owned
Node radios (outdoor + indoor)
LoRa radio module | Seeed Wio-SX1262 (SX1262, FCC modular approval Z4T-WIO-SX1262) | 2 | $9.00 |  | LoRa | Seeed | Search (https://www.seeedstudio.com/catalogsearch/result/?q=Wio-SX1262) | On SPI of each node's ESP32; solder to carrier rev B or a breakout
Module breakout | Castellated-module breakout / adapter board | 2 | $3.00 |  | LoRa | Amazon | Search (https://www.amazon.com/s?k=SX1262+module+breakout+adapter+board) | Until the carrier boards get a LoRa footprint
Antenna (outside the cabinet) | 915 MHz 3 dBi, outdoor-rated, SMA bulkhead | 2 | $12.00 |  | LoRa | Amazon | Search (https://www.amazon.com/s?k=915MHz+outdoor+antenna+SMA+bulkhead) | Sheet-metal cabinets block the signal: mount outside, as with the WiFi antenna
RF pigtail | u.FL (IPEX) to SMA bulkhead, 15 cm | 2 | $4.00 |  | LoRa | Amazon | Search (https://www.amazon.com/s?k=u.FL+to+SMA+bulkhead+pigtail+15cm)
Coax extension | RG316 SMA male–female, 1 m | 2 | $6.00 |  | Optional | Amazon | Search (https://www.amazon.com/s?k=RG316+SMA+extension+1m) | Only if the antenna can't sit at the enclosure
Gateway
Thermostat built-in gateway | Seeed Wio-SX1262 on the display board's SPI | 1 | $9.00 |  | LoRa | Seeed | Search (https://www.seeedstudio.com/catalogsearch/result/?q=Wio-SX1262) | Confirm free SPI + 3 GPIO on the Waveshare 4.3" board; otherwise use the plug-in gateway
Gateway antenna | 915 MHz 2–3 dBi, small SMA or internal flex | 1 | $6.00 |  | LoRa | Amazon | Search (https://www.amazon.com/s?k=915MHz+flex+antenna+u.FL) | Inside the thermostat housing
Plug-in gateway (no thermostat) | Heltec WiFi LoRa 32 V3, 915 MHz | 1 | $22.00 |  | Optional | Heltec | Search (https://heltec.org/?s=WiFi+LoRa+32+V3) | For homes that keep their own thermostat; the range-test receiver can become this
Gateway power | USB-C 5 V 1 A wall adapter | 1 | $8.00 |  | Optional | Amazon | Search (https://www.amazon.com/s?k=USB+C+wall+charger+5V)
Gateway enclosure | Small ABS box or 3D-printed case | 1 | $8.00 |  | Optional | Amazon | Search (https://www.amazon.com/s?k=Heltec+V3+case)
Production modules (for reference; qty 0 = not in the totals)
All-in-one node module | Heltec HT-CT62 (ESP32-C3 + SX1262), FCC 2A2GJ-HT-CT62 | 0 | $7.00 |  | Future | Heltec | Search (https://heltec.org/?s=HT-CT62) | Replaces ESP32 + radio on a custom board
MCU + radio module | RAKwireless RAK3172 (STM32WL), FCC 2AF6B-RAK3172 | 0 | $9.00 |  | Future | RAKwireless | Search (https://store.rakwireless.com/search?q=RAK3172) | Alternative
 |  |  | Total
• Before buying production modules, confirm each module's FCC grant covers 500 kHz DTS operation at the power used, and its approved antennas.
• The WiFi antennas on the outdoor/indoor sheets stay: nodes keep WiFi-direct mode when there is no gateway.

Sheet: Infrastructure
Infrastructure — Parts List
Blue = editable estimate. Prices are approximate single-unit retail (Sept 2026); links are supplier search pages.
Item | Part / Spec | Qty | Est. Unit Cost ($) | Line Total ($) | Phase | Supplier | Link | Notes
Prototype infrastructure
Home Assistant server | Home Assistant Green (or Raspberry Pi 5 4 GB) | 1 | $129.00 |  | V1 | Amazon | Search (https://www.amazon.com/s?k=Home+Assistant+Green) | Runs HA + ESPHome
Bench transformer | 24 VAC 40 VA | 1 | $15.00 |  | V1 | Amazon | Search (https://www.amazon.com/s?k=24VAC+40VA+transformer)
Breadboard kit | Breadboards + jumper wires | 1 | $20.00 |  | V1 | Amazon | Search (https://www.amazon.com/s?k=breadboard+jumper+wire+kit)
USB cables | USB-C / micro-USB assortment | 1 | $10.00 |  | V1 | Amazon | Search (https://www.amazon.com/s?k=USB+C+micro+USB+cable+pack)
Heat shrink | Assortment | 1 | $10.00 |  | V1 | Amazon | Search (https://www.amazon.com/s?k=heat+shrink+tubing+assortment)
Multimeter | True RMS | 1 | $40.00 |  | Optional | Amazon | Search (https://www.amazon.com/s?k=true+RMS+multimeter) | Skip if owned
Soldering station | Temp-controlled | 1 | $60.00 |  | Optional | Amazon | Search (https://www.amazon.com/s?k=temperature+controlled+soldering+station) | Skip if owned
Reference gauge | Digital manifold / probes | 1 | $0.00 |  | V1 | Owned |  | Existing Fieldpiece probes for calibration
 |  |  | Total

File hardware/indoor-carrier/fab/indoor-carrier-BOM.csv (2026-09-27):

Refs | Value | Footprint | Qty | DNP | Off-board
C1 | 470µF 63V | Capacitor_THT:CP_Radial_D10.0mm_P5.00mm | 1
C2 | 0.1µF | Capacitor_THT:C_Disc_D5.0mm_W2.5mm_P2.50mm | 1
D1 | SMBJ48CA | Diode_SMD:D_SMB_Handsoldering | 1
D2 | 1N4007 | Diode_THT:D_DO-41_SOD81_P10.16mm_Horizontal | 1
F1 | 0.5 A fast | Fuse:Fuseholder_Clip-5x20mm_Littelfuse_111_Inline_P20.00x5.00mm_D1.05mm_Horizontal | 1
J1 | 24 VAC | Connector_Phoenix_MC_HighVoltage:PhoenixContact_MC_1,5_2-G-5.08_1x02_P5.08mm_Horizontal | 1
J2 | Mode in 24 VAC | Connector_Phoenix_MC_HighVoltage:PhoenixContact_MC_1,5_4-G-5.08_1x04_P5.08mm_Horizontal | 1
J3 | DS18B20 supply air | Connector_JST:JST_XH_B3B-XH-A_1x03_P2.50mm_Vertical | 1
J4 | DS18B20 return air | Connector_JST:JST_XH_B3B-XH-A_1x03_P2.50mm_Vertical | 1
J5 | I2C expansion | Connector_Phoenix_MC_HighVoltage:PhoenixContact_MC_1,5_4-G-5.08_1x04_P5.08mm_Horizontal | 1 | DNP
R1 | 4.7k | Resistor_THT:R_Axial_DIN0207_L6.3mm_D2.5mm_P10.16mm_Horizontal | 1
R2,R4,R6,R8 | 4.7k ½W | Resistor_THT:R_Axial_DIN0309_L9.0mm_D3.2mm_P12.70mm_Horizontal | 4
R3,R5,R7,R9 | 10k | Resistor_THT:R_Axial_DIN0207_L6.3mm_D2.5mm_P10.16mm_Horizontal | 4
U1 | ESP32 DevKit | hvac_carrier:ESP32_DevKit_30pin_W25.4mm | 1
U2 | LM2596HV | hvac_carrier:LM2596HVS_Module | 1
U3-U6 | H11AA1 | Package_DIP:DIP-6_W7.62mm_Socket | 4

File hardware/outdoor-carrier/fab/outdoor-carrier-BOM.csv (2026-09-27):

Refs | Value | Footprint | Qty | DNP | Off-board
C1 | 470µF 63V | Capacitor_THT:CP_Radial_D10.0mm_P5.00mm | 1
C2-C9 | 0.1µF | Capacitor_THT:C_Disc_D5.0mm_W2.5mm_P2.50mm | 8
D1 | SMBJ48CA | Diode_SMD:D_SMB_Handsoldering | 1
D2 | 1N4007 | Diode_THT:D_DO-41_SOD81_P10.16mm_Horizontal | 1
F1 | 0.5 A fast | Fuse:Fuseholder_Clip-5x20mm_Littelfuse_111_Inline_P20.00x5.00mm_D1.05mm_Horizontal | 1
J1 | 24 VAC | Connector_Phoenix_MC_HighVoltage:PhoenixContact_MC_1,5_2-G-5.08_1x02_P5.08mm_Horizontal | 1
J2 | Mode in 24 VAC | Connector_Phoenix_MC_HighVoltage:PhoenixContact_MC_1,5_2-G-5.08_1x02_P5.08mm_Horizontal | 1
J3 | XDB307 liquid | Connector_JST:JST_XH_B3B-XH-A_1x03_P2.50mm_Vertical | 1
J4 | XDB307 vapor | Connector_JST:JST_XH_B3B-XH-A_1x03_P2.50mm_Vertical | 1
J5 | XDB307 t.suction | Connector_JST:JST_XH_B3B-XH-A_1x03_P2.50mm_Vertical | 1
J6 | TH1 suction | Connector_JST:JST_XH_B2B-XH-A_1x02_P2.50mm_Vertical | 1
J7 | TH2 liquid | Connector_JST:JST_XH_B2B-XH-A_1x02_P2.50mm_Vertical | 1
J8 | SHT30 FS400 | Connector_Phoenix_MC_HighVoltage:PhoenixContact_MC_1,5_4-G-5.08_1x04_P5.08mm_Horizontal | 1
J9 | TH3 t.suction | Connector_JST:JST_XH_B2B-XH-A_1x02_P2.50mm_Vertical | 1
R1,R3,R5,R7 | 10k 1% | Resistor_THT:R_Axial_DIN0207_L6.3mm_D2.5mm_P10.16mm_Horizontal | 4
R2,R4,R6 | 20k 1% | Resistor_THT:R_Axial_DIN0207_L6.3mm_D2.5mm_P10.16mm_Horizontal | 3
R8 | 15k 1% | Resistor_THT:R_Axial_DIN0207_L6.3mm_D2.5mm_P10.16mm_Horizontal | 1
R9,R10,R15 | 10k 0.1% | Resistor_THT:R_Axial_DIN0207_L6.3mm_D2.5mm_P10.16mm_Horizontal | 3
R11,R13 | 4.7k ½W | Resistor_THT:R_Axial_DIN0309_L9.0mm_D3.2mm_P12.70mm_Horizontal | 2
R12,R14 | 10k | Resistor_THT:R_Axial_DIN0207_L6.3mm_D2.5mm_P10.16mm_Horizontal | 2
TH1,TH2 | 10k NTC B3950 |  | 2 |  | Excluded from board
TH3 | 10k NTC B3950 |  | 1 | DNP | Excluded from board
U1 | ESP32 DevKit | hvac_carrier:ESP32_DevKit_30pin_W25.4mm | 1
U2 | LM2596HV | hvac_carrier:LM2596HVS_Module | 1
U3 | ADS1115 0x48 | hvac_carrier:ADS1115_Module | 1
U4 | ADS1115 0x49 | hvac_carrier:ADS1115_Module | 1
U5,U6 | H11AA1 | Package_DIP:DIP-6_W7.62mm_Socket | 2

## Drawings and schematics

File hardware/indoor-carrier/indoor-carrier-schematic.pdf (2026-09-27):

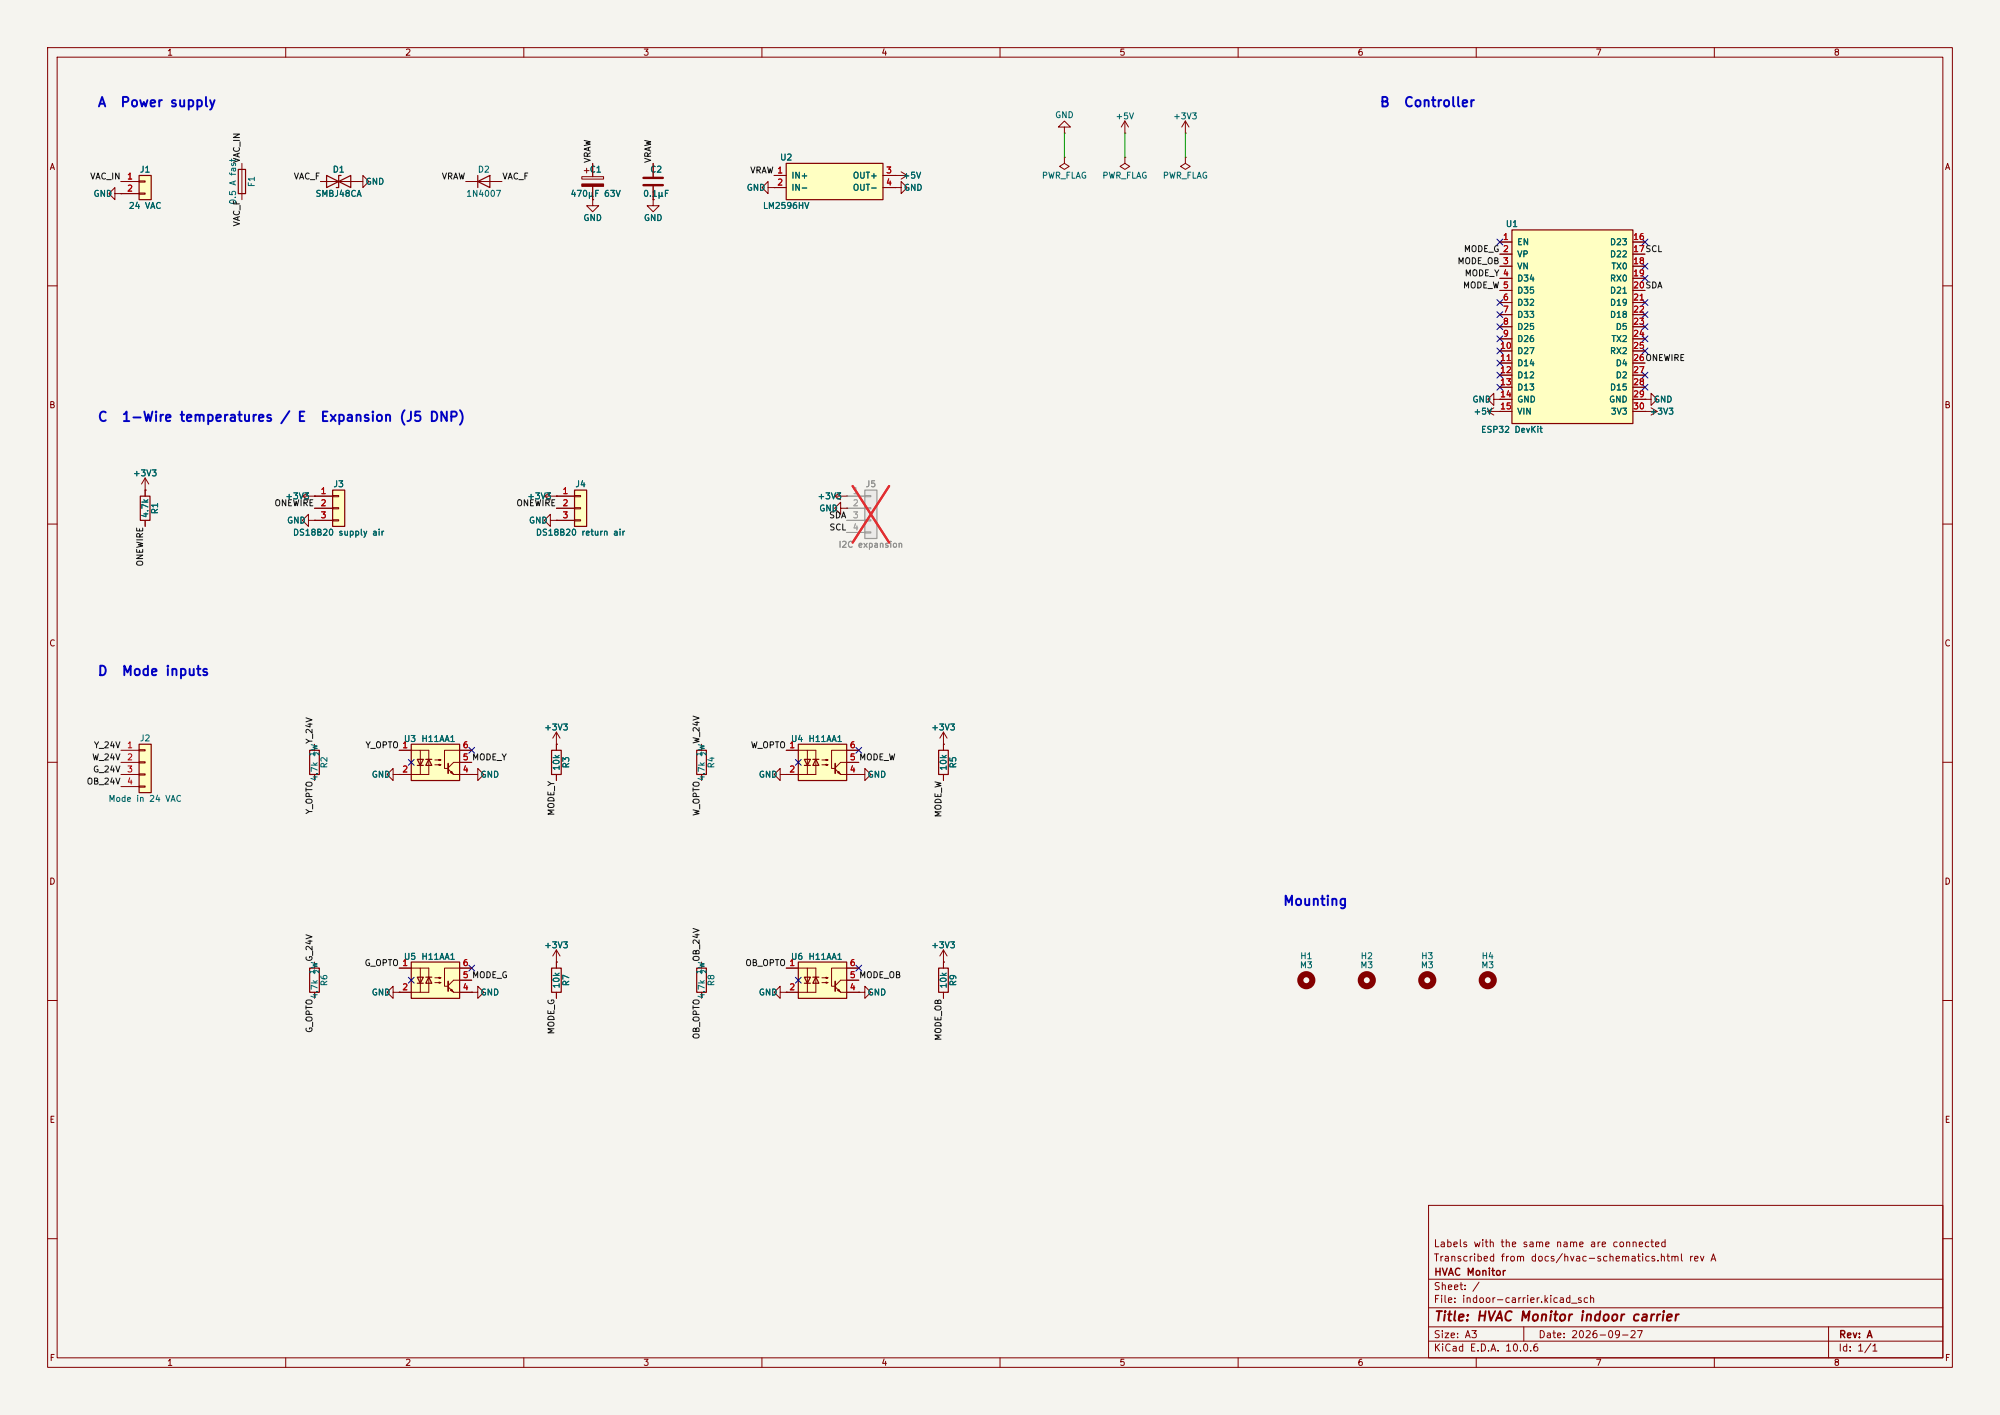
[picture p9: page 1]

C 1-Wire temperatures / E Expansion (J5 DNP)

Labels with the same name are connected
Transcribed from docs/hvac-schematics.html rev A
HVAC Monitor
Sheet: /
File: indoor-carrier.kicad_sch
Title: HVAC Monitor indoor carrier

Size: A3 | Rev: A | F Date: 2026-09-27
KiCad E.D.A. 10.0.6 | Id: 1/1

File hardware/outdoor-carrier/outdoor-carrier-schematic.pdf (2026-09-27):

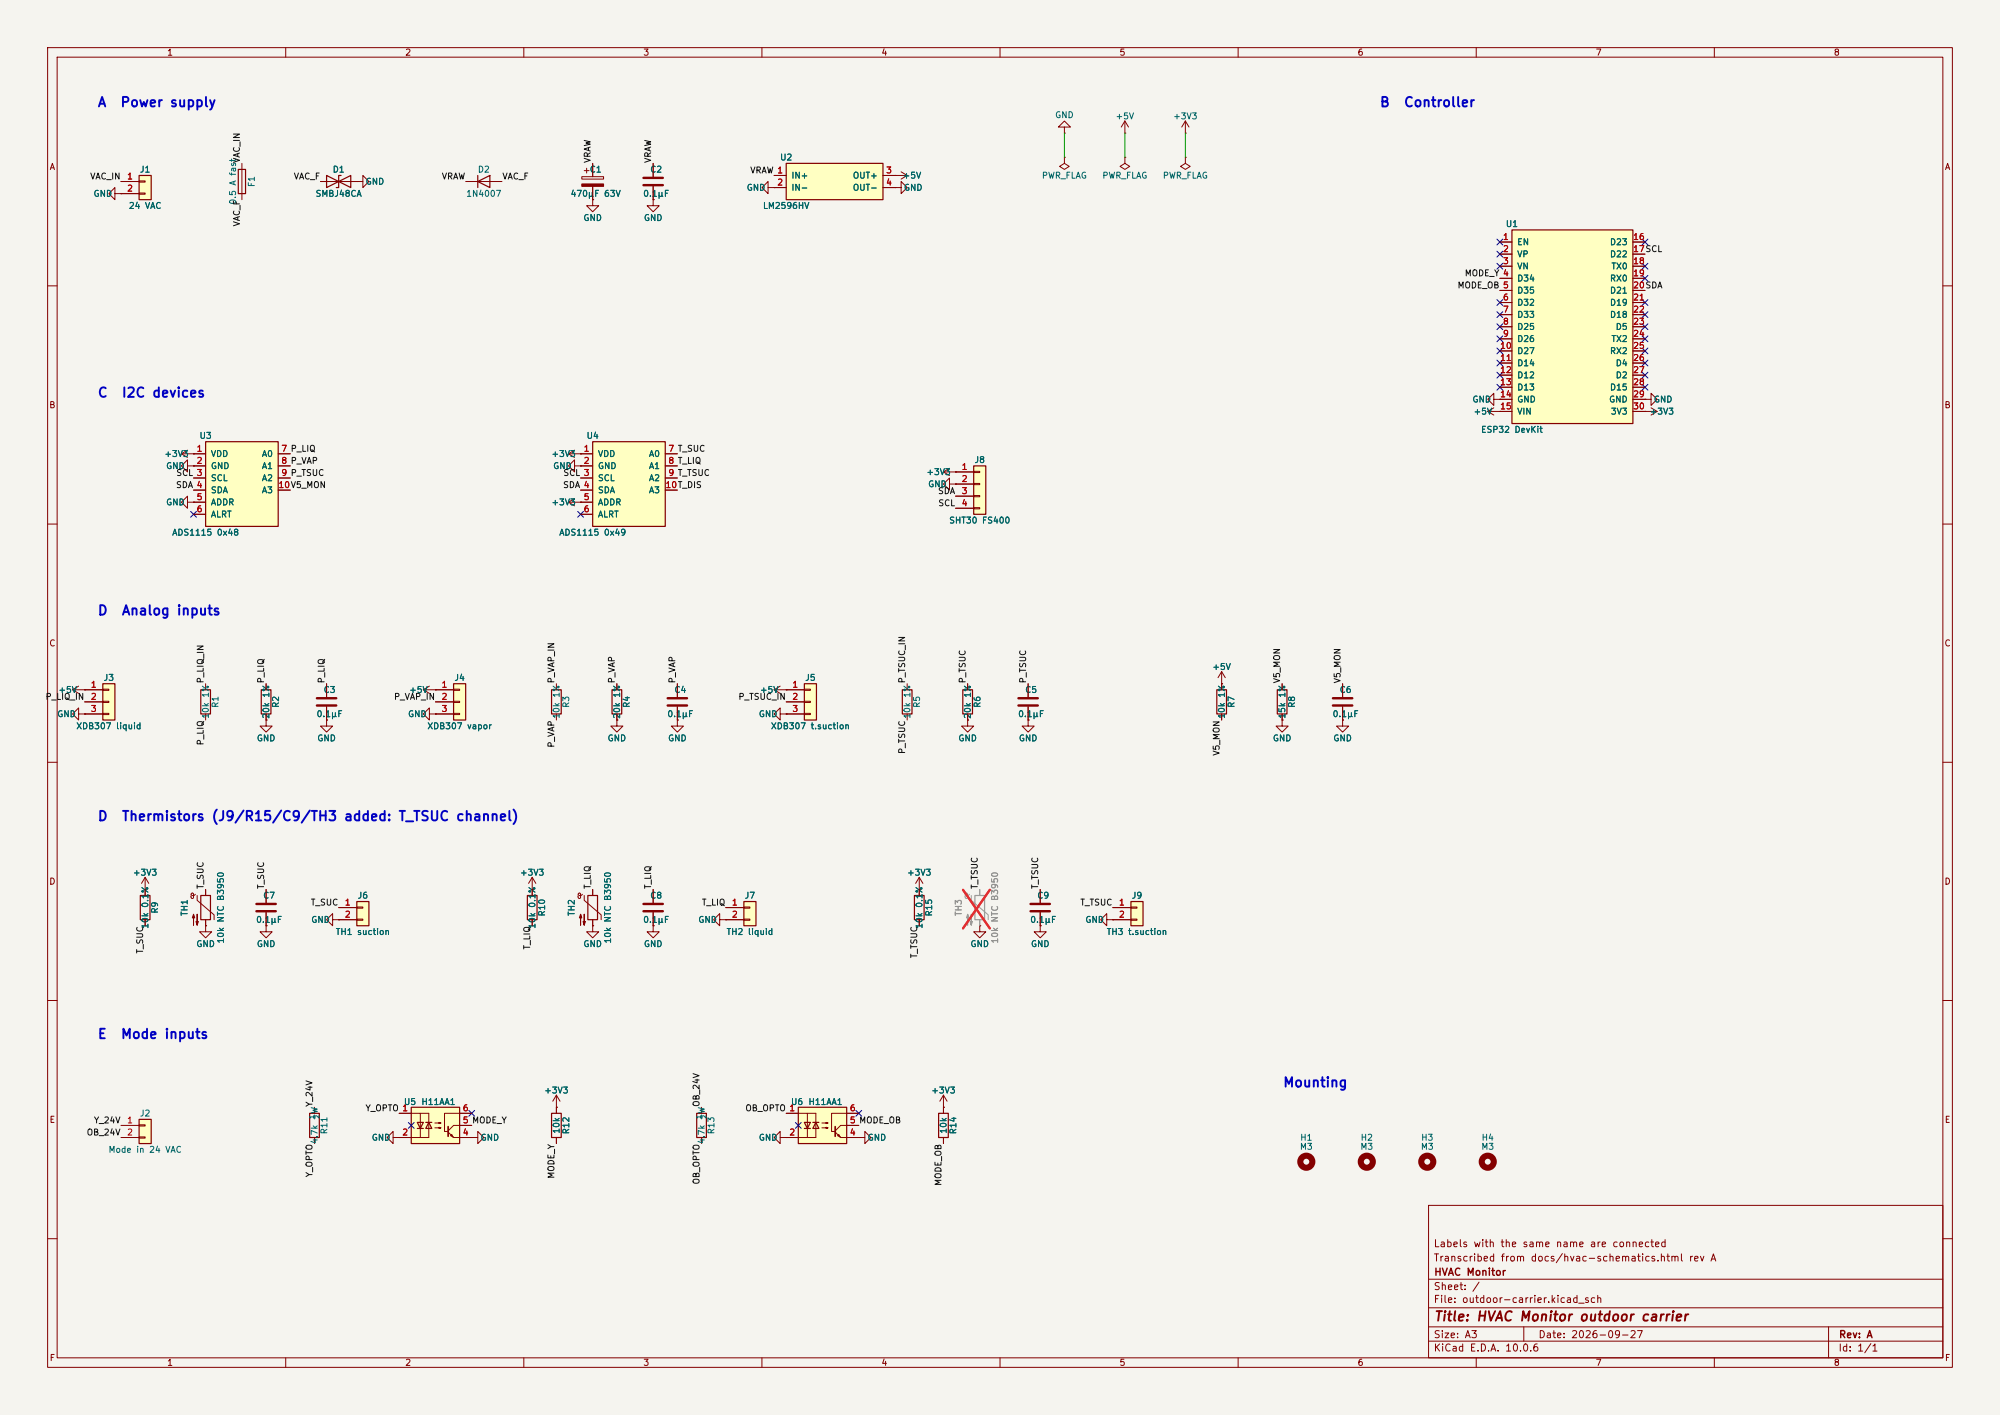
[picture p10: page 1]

Labels with the same name are connected
Transcribed from docs/hvac-schematics.html rev A
HVAC Monitor
Sheet: /
File: outdoor-carrier.kicad_sch
Title: HVAC Monitor outdoor carrier

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

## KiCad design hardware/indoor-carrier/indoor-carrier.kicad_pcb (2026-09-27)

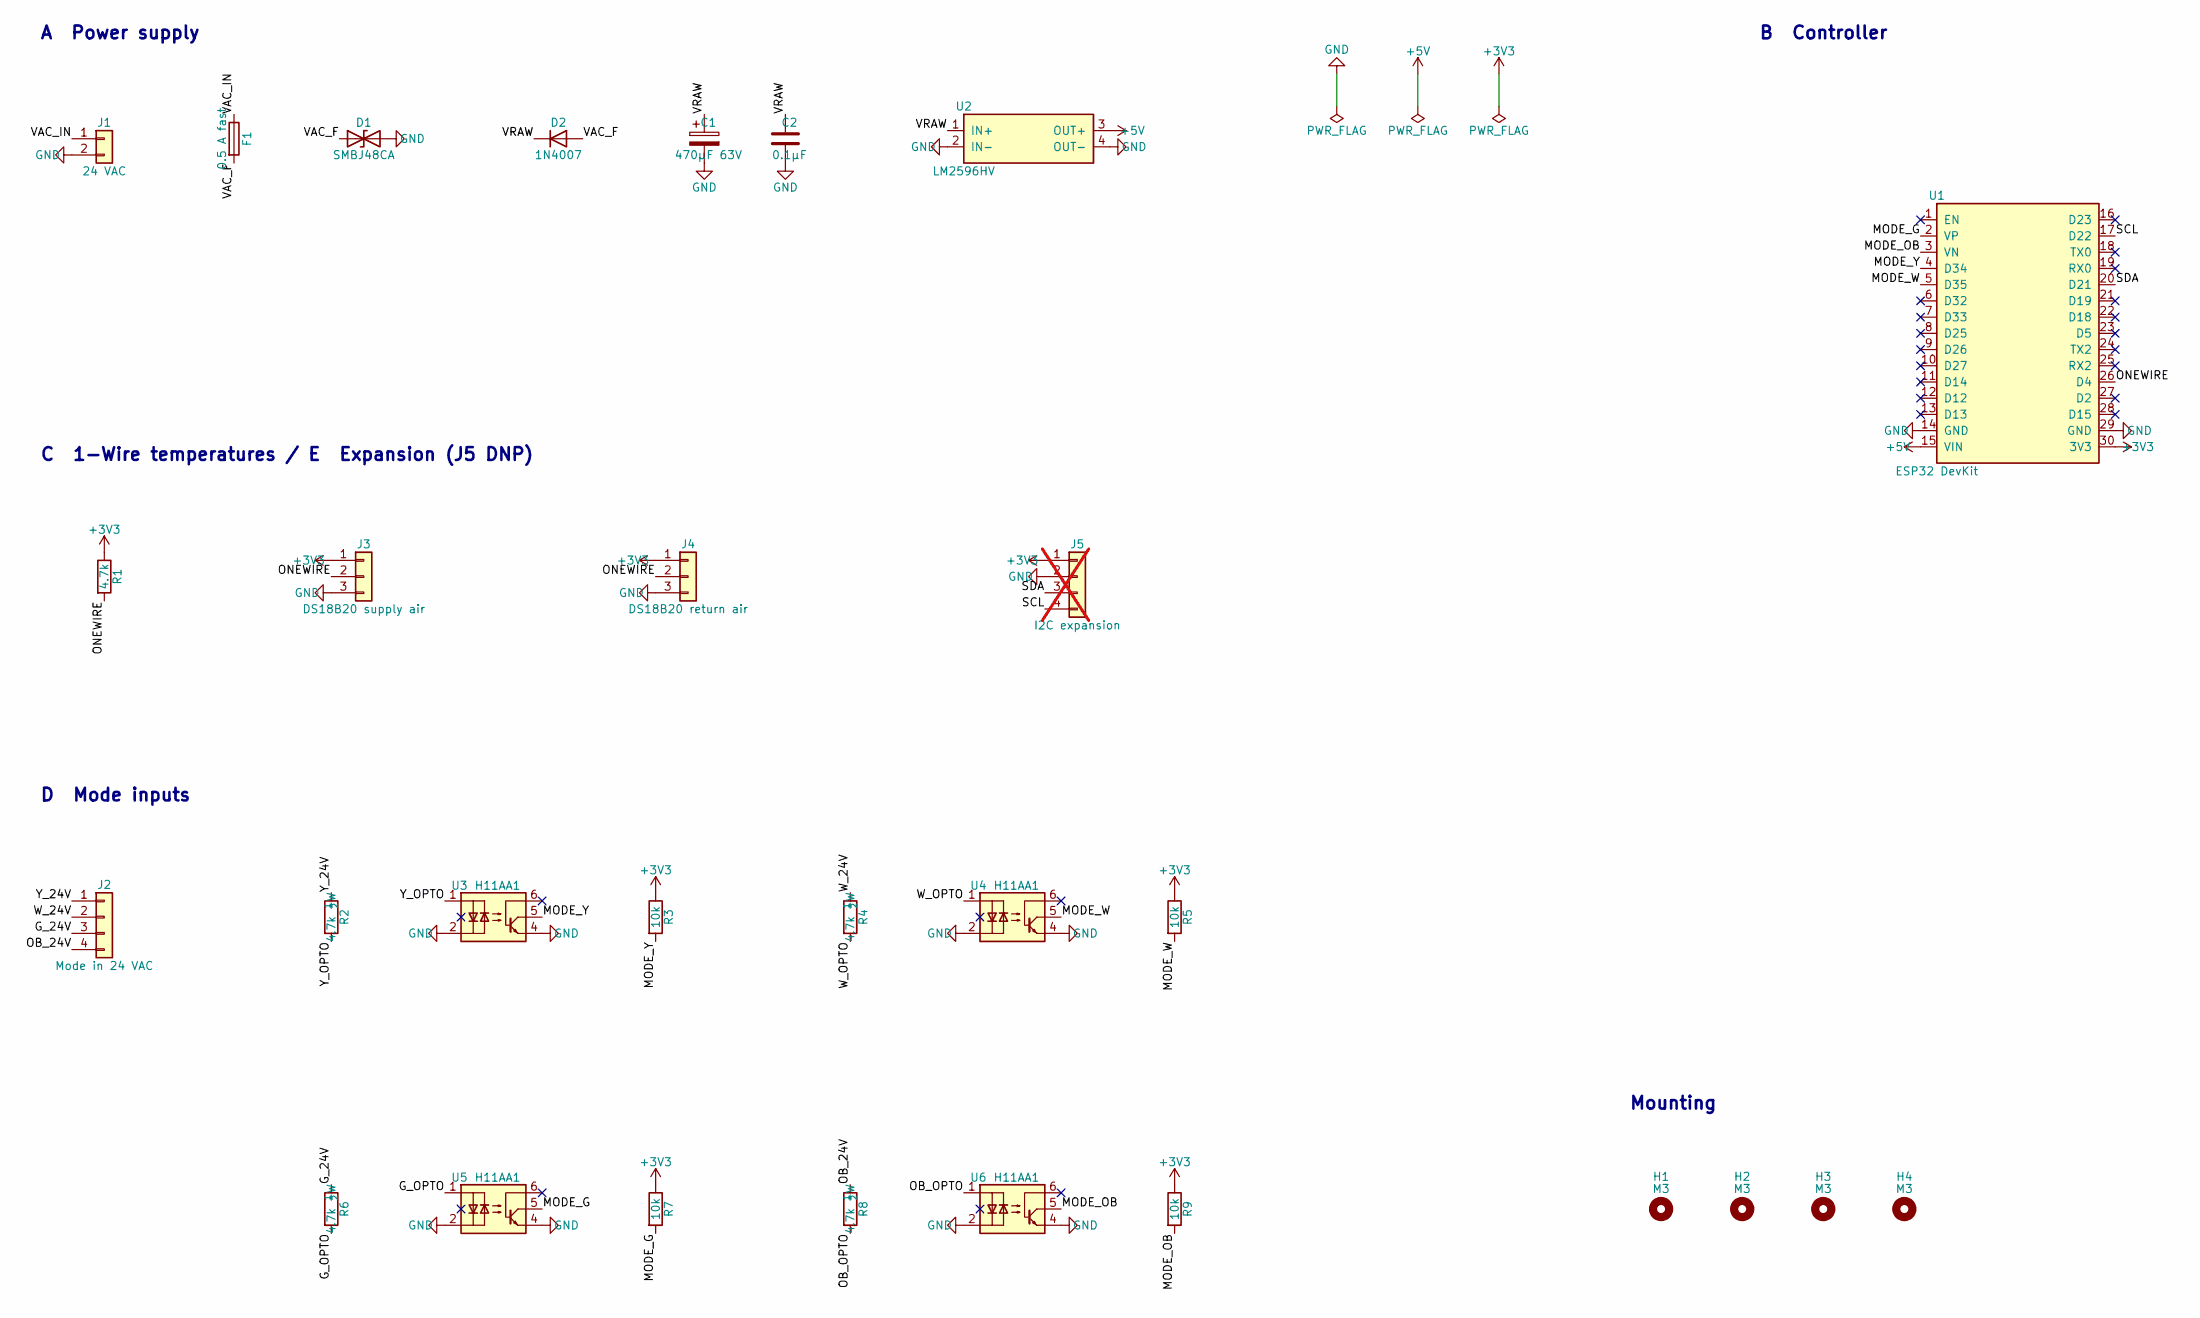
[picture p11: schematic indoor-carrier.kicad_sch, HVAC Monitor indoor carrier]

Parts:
C1: 470µF 63V; CP_Radial_D10.0mm_P5.00mm
C2: 0.1µF; C_Disc_D5.0mm_W2.5mm_P2.50mm
D1: SMBJ48CA; D_SMB_Handsoldering
D2: 1N4007; D_DO-41_SOD81_P10.16mm_Horizontal
F1: 0.5 A fast; Fuseholder_Clip-5x20mm_Littelfuse_111_Inline_P20.00x5.00mm_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
H1, H2, H3, H4: M3; MountingHole_3.2mm_M3_DIN965
J1: 24 VAC; PhoenixContact_MC_1,5_2-G-5.08_1x02_P5.08mm_Horizontal
J2: Mode in 24 VAC; PhoenixContact_MC_1,5_4-G-5.08_1x04_P5.08mm_Horizontal
J3: DS18B20 supply air; JST_XH_B3B-XH-A_1x03_P2.50mm_Vertical
J4: DS18B20 return air; JST_XH_B3B-XH-A_1x03_P2.50mm_Vertical
J5: I2C expansion; PhoenixContact_MC_1,5_4-G-5.08_1x04_P5.08mm_Horizontal; not fitted
R1: 4.7k; R_Axial_DIN0207_L6.3mm_D2.5mm_P10.16mm_Horizontal
R2, R4, R6, R8: 4.7k ½W; R_Axial_DIN0309_L9.0mm_D3.2mm_P12.70mm_Horizontal
R3, R5, R7, R9: 10k; R_Axial_DIN0207_L6.3mm_D2.5mm_P10.16mm_Horizontal
U1: ESP32 DevKit; ESP32_DevKit_30pin_W25.4mm
U2: LM2596HV; LM2596HVS_Module
U3, U4, U5, U6: H11AA1; DIP-6_W7.62mm_Socket

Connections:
+3V3: J3.1, J4.1, J5.1, R1.1, R3.1, R5.1, R7.1, R9.1, U1.30 (3V3)
+5V: U1.15 (VIN), U2.3 (OUT+)
/G_24V: J2.3, R6.1
/G_OPTO: R6.2, U5.1
/MODE_G: R7.2, U1.2 (VP), U5.5
/MODE_OB: R9.2, U1.3 (VN), U6.5
/MODE_W: R5.2, U1.5 (D35), U4.5
/MODE_Y: R3.2, U1.4 (D34), U3.5
/OB_24V: J2.4, R8.1
/OB_OPTO: R8.2, U6.1
/ONEWIRE: J3.2, J4.2, R1.2, U1.26 (D4)
/SCL: J5.4, U1.17 (D22)
/SDA: J5.3, U1.20 (D21)
/VAC_F: D1.1 (A1), D2.2 (A), F1.2
/VAC_IN: F1.1, J1.1
/VRAW: C1.1, C2.1, D2.1 (K), U2.1 (IN+)
/W_24V: J2.2, R4.1
/W_OPTO: R4.2, U4.1
/Y_24V: J2.1, R2.1
/Y_OPTO: R2.2, U3.1
GND: C1.2, C2.2, D1.2 (A2), J1.2, J3.3, J4.3, J5.2, U1.14 (GND), U1.29 (GND), U2.2 (IN−), U2.4 (OUT−), U3.2, U3.4, U4.2, U4.4, U5.2, U5.4, U6.2, U6.4

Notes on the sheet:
C 1-Wire temperatures / E Expansion (J5 DNP)
Mounting
B Controller
A Power supply
D Mode inputs

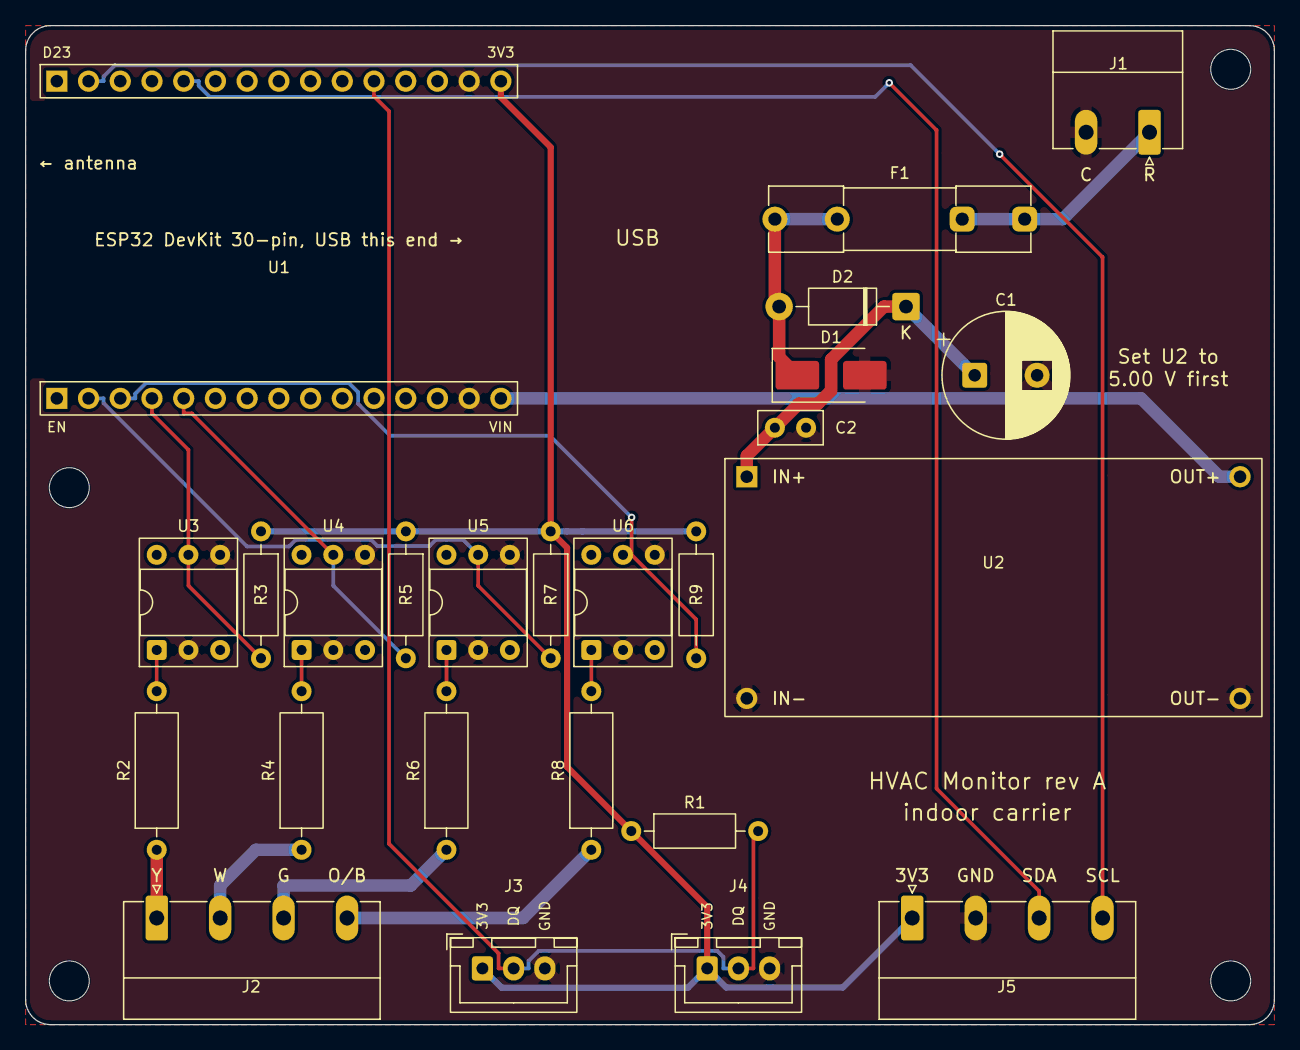
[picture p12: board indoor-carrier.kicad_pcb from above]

Board: 2 copper layers, 100.0 x 80.0 mm, 29 parts (0 on the bottom side), 21 nets.

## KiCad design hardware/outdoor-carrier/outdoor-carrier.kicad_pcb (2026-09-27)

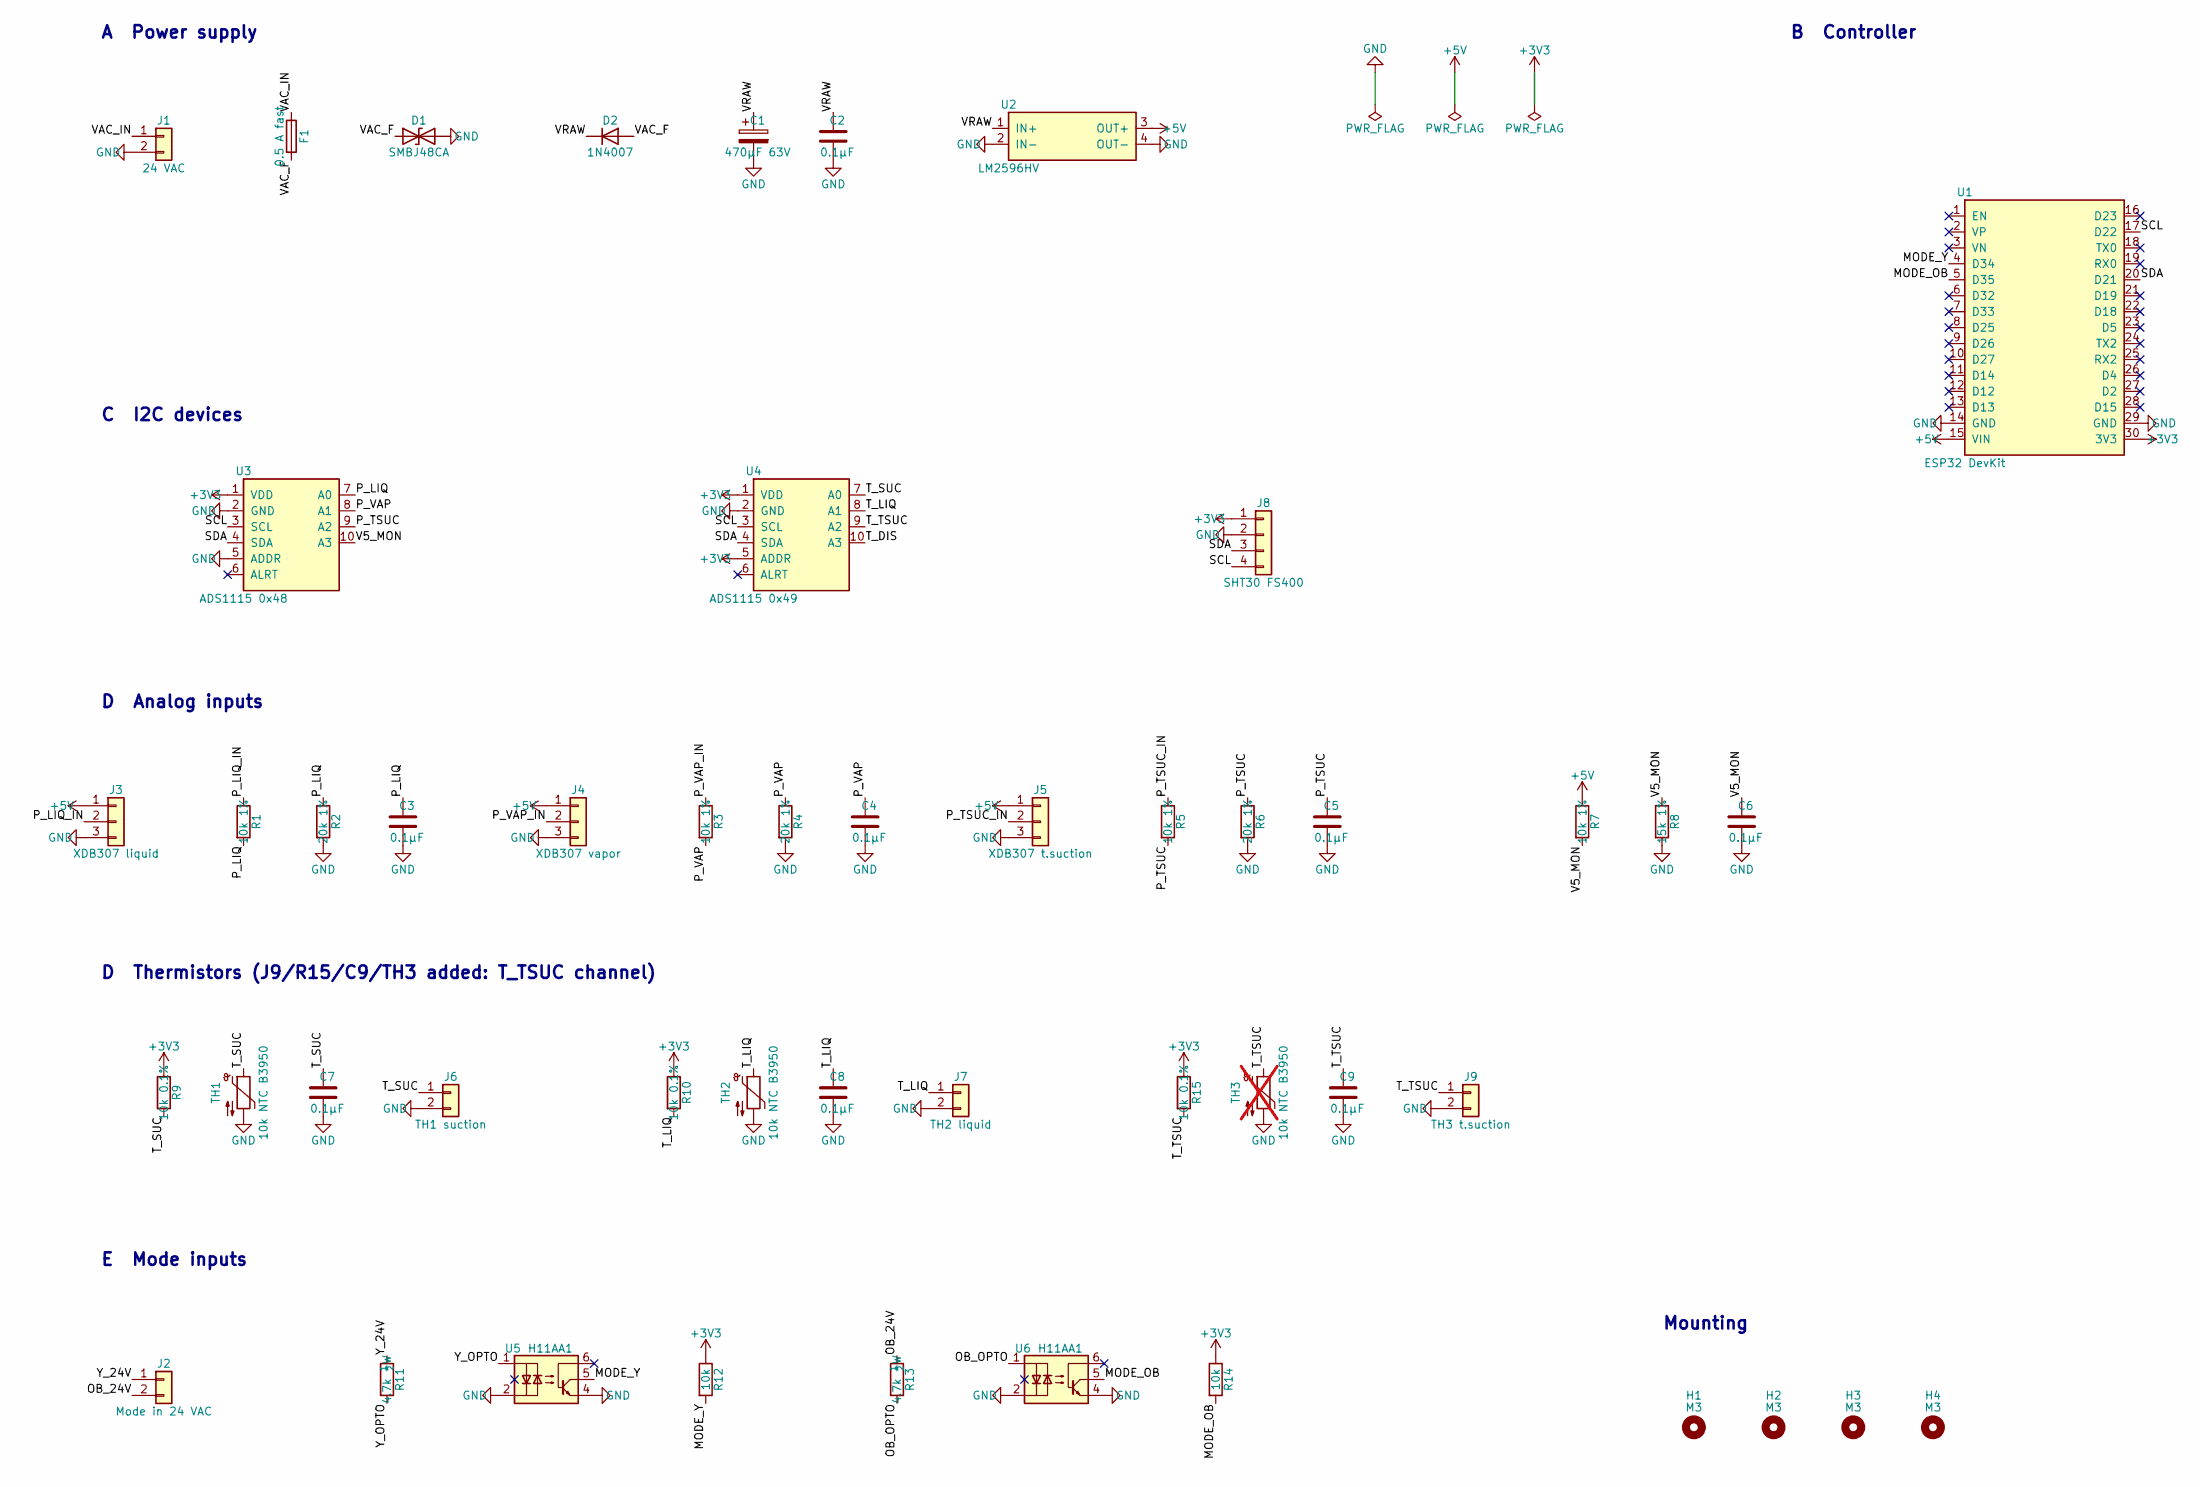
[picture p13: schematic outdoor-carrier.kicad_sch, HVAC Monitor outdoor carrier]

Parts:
C1: 470µF 63V; CP_Radial_D10.0mm_P5.00mm
C2, C3, C4, C5, C6, C7, C8, C9: 0.1µF; C_Disc_D5.0mm_W2.5mm_P2.50mm
D1: SMBJ48CA; D_SMB_Handsoldering
D2: 1N4007; D_DO-41_SOD81_P10.16mm_Horizontal
F1: 0.5 A fast; Fuseholder_Clip-5x20mm_Littelfuse_111_Inline_P20.00x5.00mm_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
H1, H2, H3, H4: M3; MountingHole_3.2mm_M3_DIN965
J1: 24 VAC; PhoenixContact_MC_1,5_2-G-5.08_1x02_P5.08mm_Horizontal
J2: Mode in 24 VAC; PhoenixContact_MC_1,5_2-G-5.08_1x02_P5.08mm_Horizontal
J3: XDB307 liquid; JST_XH_B3B-XH-A_1x03_P2.50mm_Vertical
J4: XDB307 vapor; JST_XH_B3B-XH-A_1x03_P2.50mm_Vertical
J5: XDB307 t.suction; JST_XH_B3B-XH-A_1x03_P2.50mm_Vertical
J6: TH1 suction; JST_XH_B2B-XH-A_1x02_P2.50mm_Vertical
J7: TH2 liquid; JST_XH_B2B-XH-A_1x02_P2.50mm_Vertical
J8: SHT30 FS400; PhoenixContact_MC_1,5_4-G-5.08_1x04_P5.08mm_Horizontal
J9: TH3 t.suction; JST_XH_B2B-XH-A_1x02_P2.50mm_Vertical
R1, R3, R5, R7: 10k 1%; R_Axial_DIN0207_L6.3mm_D2.5mm_P10.16mm_Horizontal
R2, R4, R6: 20k 1%; R_Axial_DIN0207_L6.3mm_D2.5mm_P10.16mm_Horizontal
R8: 15k 1%; R_Axial_DIN0207_L6.3mm_D2.5mm_P10.16mm_Horizontal
R9, R10, R15: 10k 0.1%; R_Axial_DIN0207_L6.3mm_D2.5mm_P10.16mm_Horizontal
R11, R13: 4.7k ½W; R_Axial_DIN0309_L9.0mm_D3.2mm_P12.70mm_Horizontal
R12, R14: 10k; R_Axial_DIN0207_L6.3mm_D2.5mm_P10.16mm_Horizontal
TH1, TH2: 10k NTC B3950
TH3: 10k NTC B3950; not fitted
U1: ESP32 DevKit; ESP32_DevKit_30pin_W25.4mm
U2: LM2596HV; LM2596HVS_Module
U3: ADS1115 0x48; ADS1115_Module
U4: ADS1115 0x49; ADS1115_Module
U5, U6: H11AA1; DIP-6_W7.62mm_Socket

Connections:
+3V3: J8.1, R9.1, R10.1, R12.1, R14.1, R15.1, U1.30 (3V3), U3.1 (VDD), U4.1 (VDD), U4.5 (ADDR)
+5V: J3.1, J4.1, J5.1, R7.1, U1.15 (VIN), U2.3 (OUT+)
/MODE_OB: R14.2, U1.5 (D35), U6.5
/MODE_Y: R12.2, U1.4 (D34), U5.5
/OB_24V: J2.2, R13.1
/OB_OPTO: R13.2, U6.1
/P_LIQ: C3.1, R1.2, R2.1, U3.7 (A0)
/P_LIQ_IN: J3.2, R1.1
/P_TSUC: C5.1, R5.2, R6.1, U3.9 (A2)
/P_TSUC_IN: J5.2, R5.1
/P_VAP: C4.1, R3.2, R4.1, U3.8 (A1)
/P_VAP_IN: J4.2, R3.1
/SCL: J8.4, U1.17 (D22), U3.3 (SCL), U4.3 (SCL)
/SDA: J8.3, U1.20 (D21), U3.4 (SDA), U4.4 (SDA)
/T_DIS: U4.10 (A3)
/T_LIQ: C8.1, J7.1, R10.2, TH2.1, U4.8 (A1)
/T_SUC: C7.1, J6.1, R9.2, TH1.1, U4.7 (A0)
/T_TSUC: C9.1, J9.1, R15.2, TH3.1, U4.9 (A2)
/V5_MON: C6.1, R7.2, R8.1, U3.10 (A3)
/VAC_F: D1.1 (A1), D2.2 (A), F1.2
/VAC_IN: F1.1, J1.1
/VRAW: C1.1, C2.1, D2.1 (K), U2.1 (IN+)
/Y_24V: J2.1, R11.1
/Y_OPTO: R11.2, U5.1
GND: C1.2, C2.2, C3.2, C4.2, C5.2, C6.2, C7.2, C8.2, C9.2, D1.2 (A2), J1.2, J3.3, J4.3, J5.3, J6.2, J7.2, J8.2, J9.2, R2.2, R4.2, R6.2, R8.2, TH1.2, TH2.2, TH3.2, U1.14 (GND), U1.29 (GND), U2.2 (IN−), U2.4 (OUT−), U3.2 (GND), U3.5 (ADDR), U4.2 (GND), U5.2, U5.4, U6.2, U6.4

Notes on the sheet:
E Mode inputs
A Power supply
D Thermistors (J9/R15/C9/TH3 added: T_TSUC channel)
Mounting
D Analog inputs
B Controller
C I2C devices

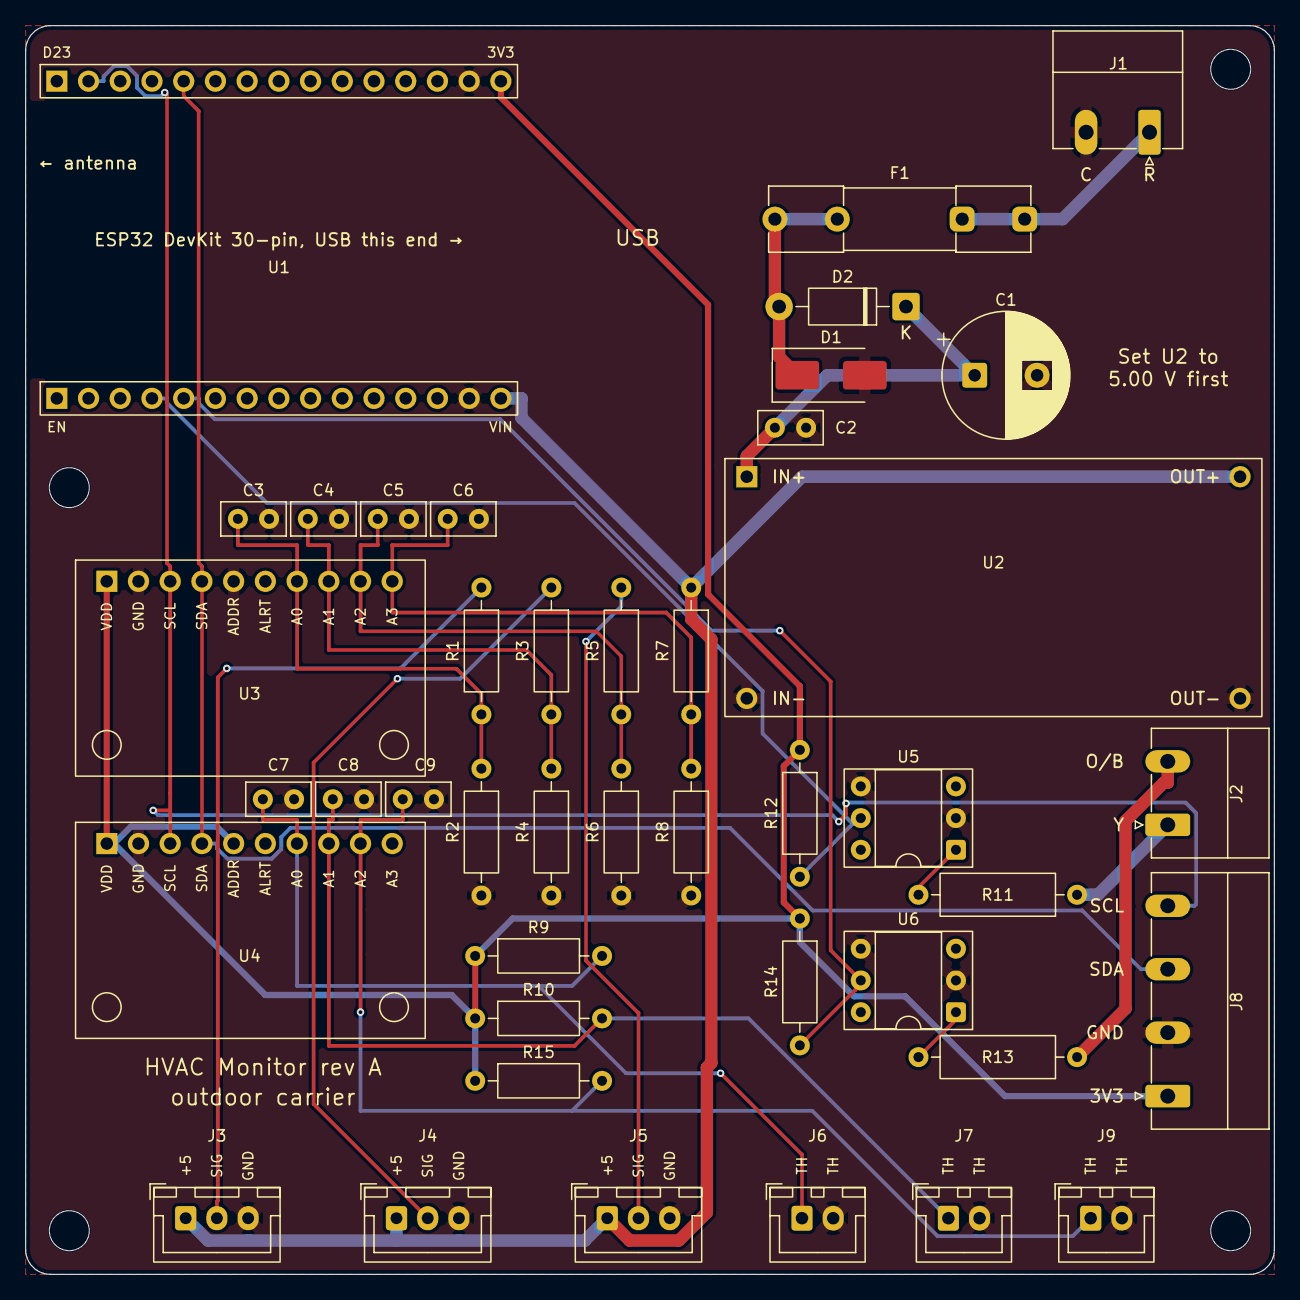
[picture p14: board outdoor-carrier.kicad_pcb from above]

Board: 2 copper layers, 100.0 x 100.0 mm, 46 parts (0 on the bottom side), 24 nets.

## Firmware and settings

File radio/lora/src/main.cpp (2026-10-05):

// Plug-in LoRa gateway (Heltec WiFi LoRa 32 V3) for homes that keep their own thermostat.
// Receives the nodes' frames on the site's channel, checks them (lorafmt::Gateway) and publishes
// exactly what the WiFi firmware would have, on the same topics; commands from the cloud
// (hvac/<site>/<node>/cmd) go back to the node over the radio. Its own status, retained, on
// hvac/<site>/gateway/status. See radio/README.md.
#include <Arduino.h>
#include <Preferences.h>
#include <PubSubClient.h>
#include <U8g2lib.h>
#include <WiFi.h>
#include <WiFiClientSecure.h>
#include <time.h>

#include "config.h"
#include "lora_gateway.h"
#include "lora_radio.h"

static const char* FW = "0.1.0";
static const LoraPins PINS = {8, 14, 12, 13};                 // Heltec V3: NSS, DIO1, RST, BUSY
static const int PIN_VEXT = 36, PIN_OLED_RST = 21, PIN_OLED_SDA = 17, PIN_OLED_SCL = 18;

struct DeviceCfg { uint32_t id; const char* key; const char* node; };
static const DeviceCfg DEVICES[] = {LORA_DEVICES};

#if MQTT_TLS
WiFiClientSecure tcp;
#else
WiFiClient tcp;
#endif
PubSubClient mqtt(tcp);
Preferences prefs;
U8G2_SSD1306_128X64_NONAME_F_SW_I2C oled(U8G2_R0, PIN_OLED_SCL, PIN_OLED_SDA, PIN_OLED_RST);
LoraRadio radio;
lorafmt::Gateway gw;

struct Stats { uint32_t frames = 0, refused = 0, saved_counter = 0; int rssi = 0; float snr = 0; uint32_t last_ms = 0; };
static Stats stats[sizeof(DEVICES) / sizeof(DEVICES[0])];
static uint32_t refused_unknown = 0, last_status = 0, last_attempt = 0, last_screen = 0;
static const char* last_error = "";

static String topic(const char* node, const char* kind) { return String("hvac/") + SITE_ID + "/" + node + "/" + kind; }

static void save_counters(bool force) {
    // Replay protection keeps the highest counter per node in flash, every 20 frames (a reboot can
    // let at most 20 old frames through once). Our own command counter jumps 100 ahead on boot.
    for (size_t i = 0; i < gw.devices().size(); i++) {
        lorafmt::Device& d = gw.devices()[i];
        if (!d.seen || (!force && d.last_counter - stats[i].saved_counter < 20)) continue;
        char key[12];
        snprintf(key, sizeof key, "c%08x", static_cast<unsigned>(d.id));
        prefs.putUInt(key, d.last_counter);
        stats[i].saved_counter = d.last_counter;
    }
}

static void publish_status() {
    JsonDocument doc;
    doc["online"] = true;
    doc["fw"] = FW;
    doc["ip"] = WiFi.localIP().toString();
    doc["rssi"] = WiFi.RSSI();
    doc["radio"] = radio.ok();
    doc["channel_mhz"] = lorafmt::channel_mhz(SITE_ID);
    doc["refused_unknown"] = refused_unknown;
    JsonObject nodes = doc["nodes"].to<JsonObject>();
    for (size_t i = 0; i < gw.devices().size(); i++) {
        JsonObject n = nodes[gw.devices()[i].node].to<JsonObject>();
        n["frames"] = stats[i].frames;
        n["refused"] = stats[i].refused;
        if (stats[i].frames) {
            n["rssi"] = stats[i].rssi;
            n["snr"] = stats[i].snr;
            n["age_s"] = (millis() - stats[i].last_ms) / 1000;
        }
    }
    String out;
    serializeJson(doc, out);
    mqtt.publish(topic("gateway", "status").c_str(), out.c_str(), true);
}

static void on_mqtt(char* t, byte* payload, unsigned int len) {
    // hvac/<site>/<node>/cmd -> a command frame for that node
    String tp(t);
    const int a = tp.indexOf('/', 5), b = tp.indexOf('/', a + 1);
    if (a < 0 || b < 0) return;
    const String node = tp.substring(a + 1, b);
    JsonDocument cmd;
    if (deserializeJson(cmd, payload, len)) return;
    uint8_t frame[lorafmt::MAX_FRAME];
    const char* why = nullptr;
    const size_t n = gw.command(SITE_ID, node.c_str(), cmd.as<JsonVariantConst>(), frame, &why);
    if (!n) {
        // tell the cloud, in the shape a node's reply has, so the command log shows why
        JsonDocument reply;
        reply["cmd"] = cmd["cmd"];
        reply["ok"] = false;
        reply["error"] = why ? why : "can't be sent over LoRa";
        String out;
        serializeJson(reply, out);
        mqtt.publish(topic(node.c_str(), "reply").c_str(), out.c_str());
        return;
    }
    lorafmt::Device* d = gw.find(SITE_ID, node.c_str());
    char key[12];
    snprintf(key, sizeof key, "t%08x", static_cast<unsigned>(d->id));
    prefs.putUInt(key, d->tx_counter);
    radio.send(frame, n);
}

static void connect_mqtt() {
    if (millis() - last_attempt < 5000 && last_attempt) return;
    last_attempt = millis();
    const String will = topic("gateway", "status");
    const char* user = strlen(MQTT_USER) ? MQTT_USER : nullptr;
    const char* pass = strlen(MQTT_PASS) ? MQTT_PASS : nullptr;
    if (!mqtt.connect((String("lora-gw-") + SITE_ID).c_str(), user, pass, will.c_str(), 1, true, "{\"online\":false}")) return;
    for (const lorafmt::Device& d : gw.devices()) mqtt.subscribe(topic(d.node.c_str(), "cmd").c_str(), 1);
    publish_status();
}

static void screen() {
    oled.clearBuffer();
    oled.setFont(u8g2_font_6x12_tf);
    char line[32];
    snprintf(line, sizeof line, "LoRa gw %s %.1f", SITE_ID, lorafmt::channel_mhz(SITE_ID));
    oled.drawStr(0, 11, line);
    snprintf(line, sizeof line, "%s %s", WiFi.status() == WL_CONNECTED ? "WiFi" : "no WiFi", mqtt.connected() ? "MQTT" : "no MQTT");
    oled.drawStr(0, 23, radio.ok() ? line : "RADIO ERROR");
    int y = 35;
    for (size_t i = 0; i < gw.devices().size() && y <= 59; i++, y += 12) {
        if (stats[i].frames) snprintf(line, sizeof line, "%-7s %lu %ddBm", gw.devices()[i].node.c_str(), static_cast<unsigned long>(stats[i].frames), stats[i].rssi);
        else snprintf(line, sizeof line, "%-7s waiting", gw.devices()[i].node.c_str());
        oled.drawStr(0, y, line);
    }
    oled.sendBuffer();
}

void setup() {
    Serial.begin(115200);
    pinMode(PIN_VEXT, OUTPUT);
    digitalWrite(PIN_VEXT, LOW);                 // powers the OLED
    delay(100);
    oled.begin();
    prefs.begin("lora-gw", false);
    for (const DeviceCfg& c : DEVICES) {
        uint8_t key[16];
        if (!lorafmt::parse_key(c.key, key) || c.id == 0) {
            Serial.printf("gateway: device %s has no id/key: run radio/tools/new_device.py\n", c.node);
            continue;
        }
        gw.add(c.id, key, SITE_ID, c.node);
        lorafmt::Device& d = gw.devices().back();
        char k[12];
        snprintf(k, sizeof k, "c%08x", static_cast<unsigned>(c.id));
        if (prefs.isKey(k)) {
            d.last_counter = prefs.getUInt(k);
            d.seen = true;
            stats[gw.devices().size() - 1].saved_counter = d.last_counter;
        }
        snprintf(k, sizeof k, "t%08x", static_cast<unsigned>(c.id));
        d.tx_counter = prefs.getUInt(k, 0) + 100;
        prefs.putUInt(k, d.tx_counter);
    }
    radio.begin(PINS, lorafmt::channel_mhz(SITE_ID));
    WiFi.mode(WIFI_STA);
    WiFi.setAutoReconnect(true);
    WiFi.begin(WIFI_SSID, WIFI_PASS);
    configTime(0, 0, "pool.ntp.org", "time.nist.gov");
#if MQTT_TLS
    tcp.setCACert(MQTT_CA_CERT);
#endif
    mqtt.setServer(MQTT_HOST, MQTT_PORT);
    mqtt.setBufferSize(2048);
    mqtt.setCallback(on_mqtt);
}

void loop() {
    if (WiFi.status() == WL_CONNECTED && !mqtt.connected()) connect_mqtt();
    if (mqtt.connected()) mqtt.loop();

    uint8_t frame[lorafmt::MAX_FRAME];
    size_t n;
    int rssi;
    float snr;
    if (radio.receive(frame, n, sizeof frame, rssi, snr)) {
        const time_t now = time(nullptr);
        const double received_at = now > 1700000000 ? now + (millis() % 1000) / 1000.0 : -1;
        std::string tp;
        JsonDocument doc;
        const char* why = nullptr;
        lorafmt::Device* d = n >= lorafmt::HEADER_LEN ? gw.find(lorafmt::peek_device(frame)) : nullptr;
        const size_t idx = d ? d - gw.devices().data() : 0;
        if (gw.receive(frame, n, received_at, true, rssi, snr, tp, doc, &why)) {
            stats[idx].frames++;
            stats[idx].rssi = rssi;
            stats[idx].snr = snr;
            stats[idx].last_ms = millis();
            String out;
            serializeJson(doc, out);
            const bool retain = tp.size() > 7 && tp.compare(tp.size() - 7, 7, "/status") == 0;
            if (mqtt.connected()) mqtt.publish(tp.c_str(), out.c_str(), retain);
            save_counters(false);
        } else {
            if (d) stats[idx].refused++; else refused_unknown++;
            last_error = why ? why : "?";
            Serial.printf("gateway: refused a frame (%s), %d dBm\n", last_error, rssi);
        }
    }
    if (millis() - last_status > 60000 && mqtt.connected()) {
        last_status = millis();
        save_counters(true);
        publish_status();
    }
    if (millis() - last_screen > 1000) {
        last_screen = millis();
        screen();
    }
    delay(2);
}

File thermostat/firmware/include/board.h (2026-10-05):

// Waveshare ESP32-S3-Touch-LCD-4.3 plus the thermostat's output board (thermostat/README.md).
// Pin numbers for the display come from Waveshare's documentation for this board:
// CHECK THEM against the board's schematic before the first power-up.
#pragma once
#include <Arduino.h>

constexpr const char* FW_VERSION = "0.1.0";

// ---- shared I2C bus (touch, CH422G, and our parts on the header)
constexpr int PIN_I2C_SDA = 8;
constexpr int PIN_I2C_SCL = 9;
constexpr int PIN_TOUCH_INT = 4;

// ---- RGB panel (800 x 480, RGB565)
constexpr int LCD_W = 800, LCD_H = 480;
constexpr int PIN_LCD_DE = 5, PIN_LCD_VSYNC = 3, PIN_LCD_HSYNC = 46, PIN_LCD_PCLK = 7;
constexpr int PIN_LCD_B[5] = {14, 38, 18, 17, 10};      // B3..B7
constexpr int PIN_LCD_G[6] = {39, 0, 45, 48, 47, 21};   // G2..G7
constexpr int PIN_LCD_R[5] = {1, 2, 42, 41, 40};        // R3..R7
constexpr uint32_t LCD_PCLK_HZ = 14000000;

// ---- CH422G I/O expander on the board (backlight, panel and touch resets)
constexpr uint8_t CH422G_MODE = 0x24;   // write 0x01: IO0-7 are outputs
constexpr uint8_t CH422G_OUT = 0x38;    // output latch
constexpr uint8_t EXIO_TP_RST = 1 << 1, EXIO_LCD_BL = 1 << 2, EXIO_LCD_RST = 1 << 3, EXIO_SD_CS = 1 << 4;

// ---- GT911 touch controller (address chosen at reset by the INT pin: low -> 0x5D)
constexpr uint8_t GT911_ADDR = 0x5D, GT911_ADDR_ALT = 0x14;

// ---- our output board, on the same I2C bus
// MCP23017 (0x20): GPA0 Y, GPA1 Y2, GPA2 W, GPA3 W2, GPA4 G, GPA5 O/B -> PhotoMOS LEDs (high = on),
//                  GPA6 -> TPS3823 WDI (toggled every loop), GPA7 spare;
//                  GPB0-4 <- H11AA1 state-sense (low while 24 VAC is present): Y, Y2, W, G, O/B.
// The TPS3823's RESET goes to the ESP32's EN *and* the MCP23017's RESET, so if the firmware
// stops, the expander resets to all inputs and every output turns off.
constexpr uint8_t MCP_ADDR = 0x20;
constexpr uint8_t OUT_Y = 0, OUT_Y2 = 1, OUT_W = 2, OUT_W2 = 3, OUT_G = 4, OUT_OB = 5, OUT_WDI = 6;
constexpr uint8_t SENSE_Y = 0, SENSE_Y2 = 1, SENSE_W = 2, SENSE_G = 3, SENSE_OB = 4;

// ---- room sensor: SHT45 (0x44) on its thermally isolated tab
constexpr uint8_t SHT45_ADDR = 0x44;
constexpr float ROOM_OFFSET_F = 0.0f;   // calibrate against a reference: the display warms the case

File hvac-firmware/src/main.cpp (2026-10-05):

// HVAC Monitor node firmware
// One codebase, two builds: -DNODE_OUTDOOR (refrigerant side) and -DNODE_INDOOR (air side).

#include "common.h"
#include "config.h"
#include "lora_link.h"
#include "net.h"
#include "settings.h"
#include <WiFi.h>

static uint32_t lastPublish = 0;
static uint32_t intervalMs  = 5000;
static uint32_t lastLoraStatus = 0;
static const uint32_t LORA_STATUS_MS = 5UL * 60UL * 1000UL;   // over LoRa the status isn't retained: resend

// The link: WiFi + MQTT as before, or LoRa to the site's gateway when config.h says so.
static void publishStatus();

static void handleCommandInner(JsonDocument& cmd, JsonDocument& reply);

// Every successful change re-publishes the retained status, so the cloud shows the new settings.
static void handleCommand(JsonDocument& cmd, JsonDocument& reply) {
  handleCommandInner(cmd, reply);
  const char* c = cmd["cmd"] | "";
  if ((reply["ok"] | false) && strcmp(c, "status") && strcmp(c, "reboot")) publishStatus();
}

static void publishStatus() {
  if (LORA_ENABLED) loraSendStatus(intervalMs);
  else netPublishStatus();
}

static void fillStatus(JsonDocument& doc) {
  doc["interval_ms"] = intervalMs;
  nodeFillStatus(doc);
}

// Commands every node understands; anything else goes to the node file.
static void handleCommandInner(JsonDocument& cmd, JsonDocument& reply) {
  const char* c = cmd["cmd"] | "";
  if (!strcmp(c, "reboot")) {
    reply["ok"] = true;
    publishStatus();
    delay(300);
    ESP.restart();
  } else if (!strcmp(c, "interval")) {
    uint32_t ms = cmd["ms"] | 0;
    if (ms < 1000 || ms > 600000) { reply["ok"] = false; reply["error"] = "ms must be 1000-600000"; return; }
    intervalMs = ms;
    setPutU("interval", ms);
    reply["ok"] = true; reply["ms"] = ms;
  } else if (!strcmp(c, "status")) {
    publishStatus();
    reply["ok"] = true;
  } else if (!nodeHandleCmd(cmd, reply)) {
    reply["ok"] = false;
    reply["error"] = "unknown command";
  }
}

// Status LED: fast blink = no WiFi, slow blink = no MQTT, short flash every 3 s = all good
static void ledUpdate() {
  uint32_t t = millis();
  bool on;
  if (LORA_ENABLED) {                // LoRa: fast blink = radio problem, short flash = sending
    digitalWrite(PIN_LED, loraOk() ? (t % 3000) < 40 : (t / 100) % 2);
    return;
  }
  switch (netState()) {
    case NET_NO_WIFI: on = (t / 100) % 2; break;
    case NET_NO_MQTT: on = (t / 500) % 2; break;
    default:          on = (t % 3000) < 40; break;
  }
  digitalWrite(PIN_LED, on);
}

void setup() {
  Serial.begin(115200);
  delay(300);
  Serial.printf("\n=== HVAC monitor | %s node | fw %s ===\n", NODE_NAME, FW_VERSION);
  pinMode(PIN_LED, OUTPUT);
  settingsBegin();
  intervalMs = setGetU("interval", 5000);
  nodeSetup();
  if (LORA_ENABLED) {
    loraBegin(handleCommand);
    loraSendStatus(intervalMs);
    lastLoraStatus = millis();
  } else {
    netBegin(handleCommand, fillStatus);
  }
}

void loop() {
  if (LORA_ENABLED) loraLoop(); else netLoop();
  if (LORA_ENABLED && millis() - lastLoraStatus >= LORA_STATUS_MS) {
    lastLoraStatus = millis();
    loraSendStatus(intervalMs);
  }
  nodeLoop();
  ledUpdate();

  uint32_t now = millis();
  if (now - lastPublish >= intervalMs) {
    lastPublish = now;
    JsonDocument doc;
    doc["node"]   = NODE_NAME;
    doc["fw"]     = FW_VERSION;
    doc["uptime"] = now / 1000;
    doc["rssi"]   = WiFi.status() == WL_CONNECTED ? WiFi.RSSI() : 0;
    if (netTimeValid()) doc["ts"] = serialized(String(netEpoch(), 3));   // when it was measured (UTC)
    nodeFillTelemetry(doc);
    String out;
    serializeJson(doc, out);
    Serial.println(out);             // bench testing works with just a USB cable
    if (LORA_ENABLED) loraSendReading(doc); else netPublishTelemetry(out);
  }
}

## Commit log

2026-09-27 Add KiCad carrier boards (rev A) and design docs
    Outdoor (100x100) and indoor (100x80) carrier boards in KiCad 10, generated
    from the rev A schematics and placement preview in docs/. Includes the
    generator scripts, project footprint/symbol library, DRC-clean routed boards,
    JLCPCB Gerber/drill zips, BOMs and renders. Sensor headers are JST-XH; 24 VAC,
    mode inputs and I2C use Phoenix MC 1,5. Also adds the dashboard mockups and
    updates CLAUDE.md with the hardware layout.
    [indoor-carrier-BOM.csv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]
2026-09-29 Record carrier board order and bring-up steps in CLAUDE.md
    Also includes KiCad's reformat of outdoor-carrier.kicad_pro (settings unchanged).
2026-09-29 Rebuild the cloud stack (ingest, API, manage.py, demo publisher)
    hvac-cloud/ replaces the claude.ai-only cloud MVP. The ingest worker listens on the
    firmware's existing hvac/<site>/<node>/... topics and stores telemetry, derived
    snapshots (a tested port of the dashboard's compute/flags) and node status; the
    FastAPI API serves systems, live state, history, CSV export, settings and node
    commands per account API key. SQLite for development, TimescaleDB via Docker
    Compose (untested: Docker not installed yet). 18 tests pass.
    CLAUDE.md: document hvac-cloud and correct the DEVICE_ID cloud-mode note, which
    described the lost firmware v0.2.0.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
2026-09-29 Add the Fullscope web app to the cloud stack
    hvac-cloud/web/ is a plain-JS single-page app served by the API at /app/, styled
    from the Fullscope mockups in design/: a homeowner Home view (plain-language
    status, what we noticed, system health, last 24 hours) and a technician Monitor
    view (SH/SC/delta-T strip, live trend, operating state, sensor health,
    refrigerant and air-side tables, diagnostics, CSV export). Unmeasured values
    show "Not installed", never estimates.
    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
2026-10-02 Apply the Fullscope design system to the web app; fix two cloud bugs
    design/: add the design system (README, fullscope.css, tokens.json, logos) and the
    updated Home/Monitor mockups.
    Web app: tokens from the mockups + design/fullscope.css verbatim; dark first; chrome
    wordmark (the WebP embedded in the mockups) and tagline on the dark header bar in
    both themes; Bahnschrift/Barlow type; homeowner level words per the README; five
    health areas with Airflow "Not measured" until static pressure sensors exist.
    Fixes:
    - Ingest restarts the compressor-run timer after a data gap longer than
    STALE_SECONDS; an outage mid-cooling had continued one cycle for days and raised
    false flags.
    - start-cloud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
2026-10-02 Switch to D-DIN everywhere and self-host it in the web app
    Design system update: all text is set in D-DIN (DIN 1451) with Bahnschrift as the
    fallback, one family for tags and numbers too (README, tokens, mockups). Applied to the
    web app, the PC dashboard and the docs pages.
    The web app now serves D-DIN regular and bold itself from web/fonts/ (SIL Open Font
    License 1.1, OFL.txt included) instead of fonts.cdnfonts.com, and the API serves .woff
    as font/woff. The PC dashboard and docs still load D-DIN from the CDN.
    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
2026-10-03 Add Sensors & calibration page to the web app
    New technician page (#/setup/<id>, the mockup's "Sensors & calibration" tab) for
    commissioning the carrier boards: per channel on/off, live reading, raw volts or ohms
    and the stored calibration, with buttons for the firmware's commands (zero, span, ice
    bath / reference temperature, reset, range, B-value, 3.3 V rail, swap and rescan the
    indoor probes, interval, reboot). A command log shows each node's reply, and after a
    change the page reloads the node's settings with {"cmd":"status"}.
    - Buttons are disabled while a node is offline; zero, reset, swap and reboot confirm,
    and zero warns when the sensor reads over 25 psig.
    - Typed values and focus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
2026-10-03 Add maintenance reminders, service contractor and Request service
    Homeowner page gets the Maintenance card from the Fullscope mockup:
    - Air filter: due after 90 days or 500 hours of blower run time, whichever comes first,
    with "I changed it"; tune-up every 182 days. Progress bars, Due soon / Due now, and an
    estimated next date from the last 14 days of use.
    - Service contractor row and a Request service button (also in the status banner when
    there is an issue) that opens the homeowner's email with the current issues and the
    filter date filled in, or calls when only a phone number is set.
    - The cooling-issue banner says how long ago the filter was changed.
    The ingest worker adds blowe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
2026-10-03 Alert recipients, plain-language owner emails, acknowledge and mute
    - Per-system recipients: the account owner (default) and/or the service contractor's
    email. Owners get plain language with what to do and a "For your contractor" line;
    contractors get the technical reading, site id and a link to the technician view.
    - Acknowledge an open alert from the Alert log: shown as Handling / "Being handled" on
    the homeowner page, and no "back to normal" email is sent for it.
    - Mute emails for one kind of alert on a system for 1, 7 or 30 days; alerts are still
    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
2026-10-03 Add user sign-in with contractor and homeowner roles
    - Users sign in with email and password (scrypt, standard library). Sessions live in an
    HttpOnly SameSite=Lax cookie for 30 days, renewed while in use; only a hash of the
    token is stored. Cookie requests that change something must carry X-Requested-With.
    Eight wrong passwords lock an email for 15 minutes.
    - Contractor users see all their account's systems and the technician pages. Homeowner
    users see only systems they are members of, read-only apart from marking the filter
    changed; technician endpoints answer 403 and the web app keeps them on the home page.
    - API keys still work and act as a contractor of their account.
    - /api/au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
2026-10-03 Add invites and the contractor fleet page
    - Invites: a contractor invites a homeowner to a system (Sensors & calibration page,
    "Homeowner access") or a colleague to the account (Account page, "Your team"). The
    link (#/invite/<token>, hashed in the database, single use, 7 days) lets them choose a
    password and signs them in. Emailed when SMTP is set up, always shown to copy. An
    existing homeowner sign-in is given access at once. Members can be removed and
    pending invites revoked.
    - Fleet page (#/fleet), the contractors' landing page: every system on the account, worst
    first (service needed, offline, check soon, good to know, maintenance due), with
    issues and open alerts, node hea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
2026-10-03 Add the Equipment page and nameplate subcooling targets
    - Equipment page (#/equipment/<id>), from the monitor mockup's equipment configuration:
    system type, heat pump / straight cool, O/B, refrigerant, metering device, tonnage;
    nameplate subcooling target and tolerance, rated capacity and airflow, max external
    static; site elevation, which sets atmospheric pressure.
    - For TXV/EEV systems with a target, subcooling in cooling is judged against target ±
    tolerance instead of the generic 3-20 F, after calc.compute in the ingest worker, so
    calc.py and the PC dashboard stay identical. Monitor shows "Target 12.0 ± 2.0
    (nameplate)". Superheat keeps the generic 3-30 F; the page says why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
2026-10-03 Add service history
    - New technician tab "Service history" (#/service/<id>, from the mockup's nav): log a
    visit with date, type (tune-up, repair, installation, inspection, other), technician,
    work done, "replaced the air filter" and "attach the current readings" (main values of a
    snapshot under 15 minutes old). Visits can be deleted.
    - A tune-up visit moves the tune-up reminder, a changed filter the filter reminder,
    forward only (an old visit logged late changes nothing).
    - Homeowners see the last three visits under Maintenance.
    - Textareas and checkboxes on technician pages now survive the 5 s re-render.
    - 4 new tests (83 pass); checked in the browser as technician and homeowner.
    C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
2026-10-04 Fix the Docker broker setup and record the first Compose test
    The Compose stack ran for the first time (Docker Desktop 29.8, TimescaleDB 2.30, Mosquitto
    2.1). Everything worked except the broker, which couldn't read a password file mounted from
    Windows, and the README's step for creating that file wrote to a read-only mount.
    - mosquitto/start.sh builds the password file from MQTT_BACKEND_* / MQTT_NODES_* in .env on
    every start (owned by the mosquitto user), so there is no manual password-file step.
    - .gitattributes keeps *.sh at LF line endings on Windows checkouts.
    - README: the tested setup steps, and pg_dump for backups.
    Verified: all tables, hypertables with 365-day retention, ingest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
2026-10-04 Firmware 0.2.0: MQTT over TLS, outage backlog, status after commands
    Firmware (built for both nodes with TLS off and on; not flashed yet):
    - MQTT over TLS when config.h sets MQTT_TLS 1 and MQTT_CA_CERT (the server's tls/ca.crt as
    a string constant): WiFiClientSecure checks the broker's certificate and name. The clock is
    set by NTP after WiFi connects, and the first TLS attempt waits up to 15 s for it. Without
    MQTT_TLS the node works as before, so a 0.1.0 config.h still builds.
    - Readings carry "ts" (UTC) once NTP answers. While the broker can't be reached, up to 120
    readings (10 min) are kept and sent oldest first on reconnect, 10 per loop. Status adds
    tls, backlog, dropped and int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
    [main.cpp, net.cpp]
2026-10-04 Radio decision work: LoRa design, frame format reference, range-test firmware
    For the roadmap's "900 MHz radio architecture" decision point (no hardware bought yet):
    - radio/README.md: FCC 15.247 research (a fixed 125/250 kHz LoRa channel is neither DTS nor
    hopping, so the design uses one fixed 500 kHz channel), radio settings and link budget
    (SF9: 77 ms per frame, ~143 dB budget), frame format, security, gateway, channel plan,
    prototype parts list, production modules with FCC modular approval, range-test procedure
    with pass criteria, and the LoRa / WiFi / cellular decision table.
    - radio/lorafmt.py: tested reference implementation. Readings in 45-byte (outdoor) / 30-byte
    (indoor)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
    [main.cpp]
2026-10-04 Electrical monitoring module: design, cloud diagnostics, views, simulator
    Roadmap phase 11, built on the software side (no hardware yet):
    - electrical/README.md: what it catches, a version 1 that needs only clamp-on current
    transformers (no line contact; covers 5 of the 10 rules) and a version 2 with an isolated
    voltage board, parts, isolation rules, data format, certification (UL/IEC 61010).
    - hvaccloud/electrical.py: a third logical node "electrical" on the same MQTT topics. Its
    newest reading joins the next refrigerant snapshot as "elec" with 10 rules: compressor or
    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
2026-10-04 Add a contractor demo: six scripted homes in a separate demo account
    - demo.py setup creates "Desert Air Demo Co." with six homes (equipment, contractor card,
    maintenance dates, service history, a day of backfilled readings, past alerts) and
    generated sign-ins for a demo contractor and one homeowner, saved in demo-login.txt
    (git-ignored). Each home acts out one story: healthy, dirty filter (low delta-T, filter
    overdue), low charge (high superheat, low subcooling vs nameplate), blocked condenser,
    indoor monitor offline, liquid floodback (service needed).
    - demo.py run keeps them live through the real ingest code (no broker or nodes), first
    filling any gap since it last ran so run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
2026-10-04 Thermostat screen: homeowner alerts, technician diagnostics with electrical markers
    - display.py builds the thermostat's display feed (plain alerts, System health areas, key
    numbers, 6 h pressure/air trend, electrical fault markers); ingest publishes it retained to
    hvac/<site>/thermostat/display; GET /api/systems/{id}/thermostat/display
    - web/thermostat.html: browser preview of the 800x480 screen (Home, Alerts, Service behind
    tech.service_pin)
    - alerts.unjudged: run-only alerts (refrigerant, delta-T, electrical) stay open between
    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
2026-10-04 Alerts: keep run-only alerts open between cycles
    Superheat, subcooling, delta-T and condensing-over-ambient are only judged after 10 minutes of
    steady running, so every time the compressor stopped their alerts cleared 5 minutes later and
    re-raised on the next run: one low charge became an alert (and a "back to normal" email) per
    cycle. alerts.unjudged(snap) lists the codes that couldn't be judged (idle, not steady, a node
    offline); their raised alerts now stay open until a judged reading shows the problem gone.
    Same code as on cloud/thermostat (where it also covers the electrical checks).
2026-10-04 Thermostat firmware: C++ control core, checked step-for-step against the Python reference
    - lib/tstat_core: settings, schedule/holds and the Controller ported from hvaccloud/thermostat.py;
    config parsing (cloud's retained JSON, tech values clamped to the safe limits) and the
    telemetry report
    - tools/make_vectors.py runs the Python Controller through four scenarios (cooling with schedule
    and holds, heat-pump winter with aux/emergency/lockouts, auto with mode changes and sensor
    glitches, furnace + AC): 32,400 steps; pio test -e native replays them and every output matches
2026-10-04 Thermostat firmware for the Waveshare ESP32-S3 4.3" board; screen edits flow back to the cloud
    Firmware (thermostat/firmware, pio run -e waveshare43 builds; nothing run on hardware yet):
    - main: every 2 s read the room, step the controller on the monotonic clock (an NTP jump can't
    cut a minimum-off time short), set the outputs; report every 5 s; feed the TPS3823 watchdog
    - io: SHT45 room sensor (3 bad reads -> everything off), MCP23017 outputs / state sensing / WDI
    - net: WiFi, MQTT (+TLS), NTP + time zone, settings kept in flash, outdoor temperature from the
    outdoor monitor, the display feed; screen changes queued and sent 1.5 s after the last tap
    - display + ui: LovyanGFX RGB panel, GT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
    [board.h, display.cpp, io.cpp]
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2026-10-05 Project files: plans, parts list, screenshots and branding in one organized folder
    project-files/ with an index README:
    - 1-plans: roadmap and contractor interview kit (exported from the live Claude Docs)
    - 2-parts: the parts spreadsheet (summary, nodes, display/thermostat, LoRa)
    - 3-screenshots: 43 screenshots from building and checking each feature, by topic
    - 4-branding: the original Fullscope logo
    plus a map of where every design doc lives in the repo.
    [HVAC_Monitor_Parts_List.xlsx]
2026-10-09 Outdoor firmware: divider resistor values as config.h settings, with overdrive checks
    P_DIV_TOP_K / P_DIV_BOTTOM_K (default 10k / 20k) and RAIL_DIV_TOP_K / RAIL_DIV_BOTTOM_K
    (10k / 15k) set the divider gains, so a board built with 10k everywhere just needs two lines in
    config.h. static_asserts refuse values that would push the ADS1115 past its 3.3 V supply (or a
    faulted 5 V signal past its 3.6 V maximum), e.g. 22k for R8. The status reports p_div / rail_div.
    Parts list notes updated.
    [HVAC_Monitor_Parts_List.xlsx]
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2026-10-11 Install on own system: enclosures, terminal map, status and roadmap
    - hardware/enclosures: OpenSCAD boxes for both carrier boards, ear bars,
    cabinet mounting plates, SHT30 louvre shield, STLs and previews
    - hardware/board-terminals.md: what plugs into each connector
    - AGENTS.md: copy of the handoff brief for Codex
    - CLAUDE.md / AGENTS.md / roadmap: boards installed on Tyler's AC, fw 0.2.0
    flashed, sensors calibrated, live data in the web app; follow-ups (PC IP
    now .204, broker to Proxmox, OTA password, Y and O/B wires)
    - outdoor-carrier.kicad_pro: ERC defaults KiCad added on open
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2026-10-17 Static pressure: 3x SDP810 on the indoor mux (TESP, filter drop)
    Indoor fw 0.2.2 reads SDP810s on TCA9548A channels 2-4 (return, supply,
    filter) with a cal_zero command. Cloud airflow.py / Airflow.cs add
    snap.static, tesp_high and filter_dirty while the blower runs. Web app
    shows static on Monitor, Home airflow health and a Setup zero panel.
    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
2026-10-18 Shrink rev B boards with the same parts: outdoor 100 x 100, indoor 100 x 88
    The power corner is back at its rev A position. The radio's regulator, input cap and the
    SETUP button moved right of C1, so the top band fits in 100 mm.
    - Outdoor: the empty band is gone. The dividers sit under U2 in 3.5 mm columns, and the
    thermistor reference resistors sit under U4. Within JLCPCB's cheapest 100 x 100 size again.
    - Indoor: J5 sits under U2 on the right edge and H3 is inside the board. The mux chip
    and pull-ups are under U2, and the U6 and 1-Wire pull-ups sit below the optos.
    Both boards: DRC 0 violations, 0 unconnected, 0 footprint errors; ERC 0 / 0.
    Box, plate and docs updated for the new sizes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
2026-10-18 LXC: go live from home through a Cloudflare Tunnel, optional MQTT TLS
    PUBLIC_HOST in fullscope.env plus a tunnel token (fullscope-tunnel-token,
    hidden prompt) installs cloudflared and runs fullscope-tunnel.service to the
    web app on 8000; APP_URL becomes https://PUBLIC_HOST/app/ and COOKIE_SECURE
    true. MQTT_PUBLIC_HOST makes a private CA + broker certificate with
    hvac-cloud/tls/make-certs.sh and adds a TLS listener on 8883 for boards in
    other homes (needs broker passwords). Older settings files get the new
    lines appended. Nodes on the home network keep port 1883.
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2026-10-19 Resend readings that a quietly dead connection swallowed
    The outdoor node's WiFi link has been dropping every few minutes; PubSubClient keeps
    "publishing" into the dead socket until the keepalive notices, and those readings were lost.
    Firmware 0.3.2 listens to its own telemetry topic and resends anything the broker never
    echoed back on the next connection. The cloud (Python and C#) ignores an exact repeat of a
    reading it already has.
    Claude-Session: https://claude.ai/code/session_01BpMKP4yb835E7L8qaQcCL4
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2026-10-20 rev A OTA builds: use the normal library finder, ignore the Bluetooth libraries
    deep+ evaluated RadioLib's guarded #include <SPI.h> as false and the build failed on Tyler's PC.
    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
2026-10-20 Turn off WiFi modem power saving on the nodes
    On weak links (Tyler's boards: -68 and -79 dBm) modem sleep makes MQTT connections drop and OTA
    uploads die partway (both failed at 7-42% on 2026-10-20).
    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
2026-10-20 Keep config.h's WiFi network when Bluetooth setup saved none
    setupBleWifi cleared the SSID before checking whether one was saved, so every board without a
    Bluetooth-setup network tried to join a blank network ("SSID too long or missing"). Came in with
    0.3.1; first seen when Tyler flashed 0.3.2 on 2026-10-20.
    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
2026-10-20 Public landing page at the site root
    / now serves hvac-cloud/web/welcome.html (C# and Python servers), a
    contractor-facing page with Sign in links to /app/; falls back to the
    redirect when the file is missing.
    Claude-Session: https://claude.ai/code/session_01Q1EQBVrQ6sVeSJhEjpPHxZ
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2026-10-20 Fullscope Office: kits, boards, warranty claims and the contractor's QR claim
    Staff register kits (outdoor + indoor board by serial), print a QR label,
    ship kits to customers, open and settle warranty claims, and release a kit
    claimed by mistake. A contractor scans the label, signs in and names the
    system: it is created on their account with site_id = the kit code, the
    boards' warranty starts and the homeowner is invited. Python and C# both;
    replay grows to 372 requests.
    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
2026-10-20 Fullscope Office Flash tab and firmware 0.4.0: kit code and broker saved on the board
    Office gets a Flash tab: in Chrome or Edge it writes the factory image to a
    board over USB with esptool-js (vendored, Apache-2.0), reads its MAC as the
    serial, saves the kit code and broker on it, and registers the kit.
    Firmware 0.4.0 keeps site + broker in NVS (config.h is the default),
    answers JSON commands over USB serial, and USB builds also write a merged
    <env>-<version>-factory.bin.
    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
2026-10-29 Thermostat carrier board rev A: 2-stage outputs, read-backs, watchdog, LoRa over I2C
    The Waveshare ESP32-S3-Touch-LCD-4.3 has no free SPI pins, so the carrier hangs everything
    off its I2C header: MCP23017 outputs (Y1 Y2 W1 W2 G O/B) and read-backs, TPS3823 watchdog
    on the expander's reset, and an SC18IS602B I2C-SPI bridge for the Wio-SX1262 (DIO1 on GPIO6).
    Rh/Rc/C terminals with an Rc=Rh jumper, USB-C 5 V input for display-only use, USB-A 5 V out
    to the display. 100 x 100 mm, routed DRC/ERC clean; gerbers, BOM, CPL, JLC BOM, renders.
    Scripts take KICAD_SHARE / KICAD_CLI / KICAD_PY so they also run in the kicad/kicad Docker
    image. Firmware: board.h pin map, W2 read-back, RadioLib HAL for th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
2026-10-30 Thermostat carrier: stack behind the Waveshare 4.3 on its own outline
    The carrier now matches the display's 106 x 68 mm outline and screws to its
    four M2.5 standoffs (measured from Waveshare's STEP model). SMD parts sit on
    the wall side for JLC assembly; a right-edge notch clears the display's side
    sockets, and short HY2.0 leads go to J5 (I2C) and J6 (IO6 for LoRa DIO1).
    - Power: TPS54360B buck to 5.3 V replaces the LM2596 module; USB-C in for
    display-only use, USB-C out carries 5 V to the display.
    - route.py: fan-out vias stay inside the outline and off exposed pads;
    pour islands are joined by vias, short bridges or a grid search
    (maze_bridge) for a GND track.
    - gen_sch: PWR_FLAG on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
